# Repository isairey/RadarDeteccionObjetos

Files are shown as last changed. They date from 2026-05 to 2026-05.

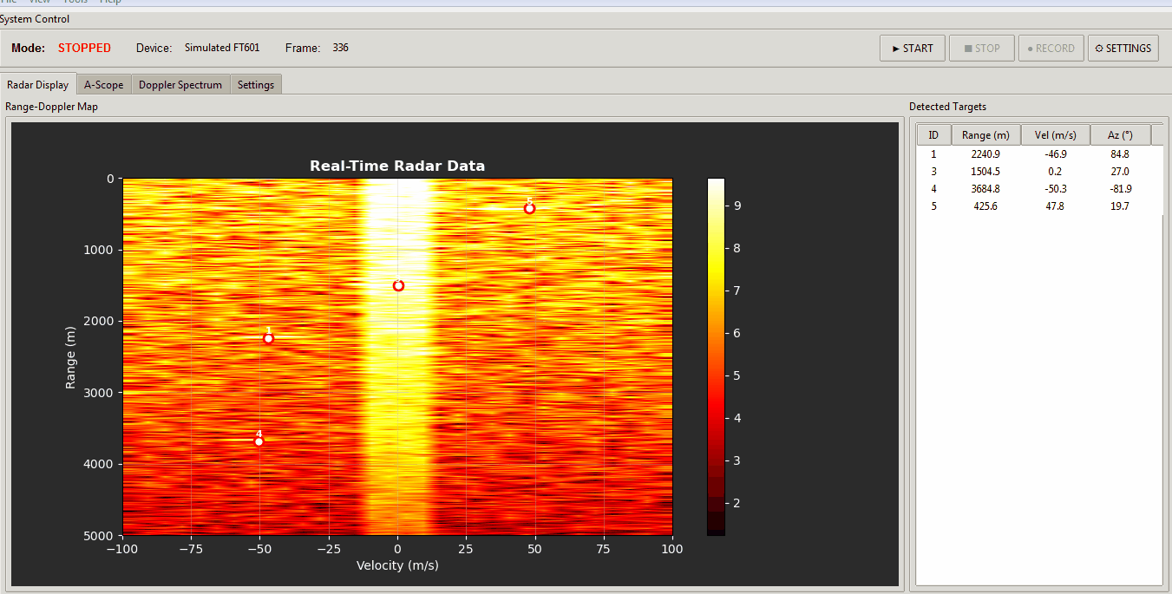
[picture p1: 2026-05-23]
docs/assets/img/GUI_V6.gif

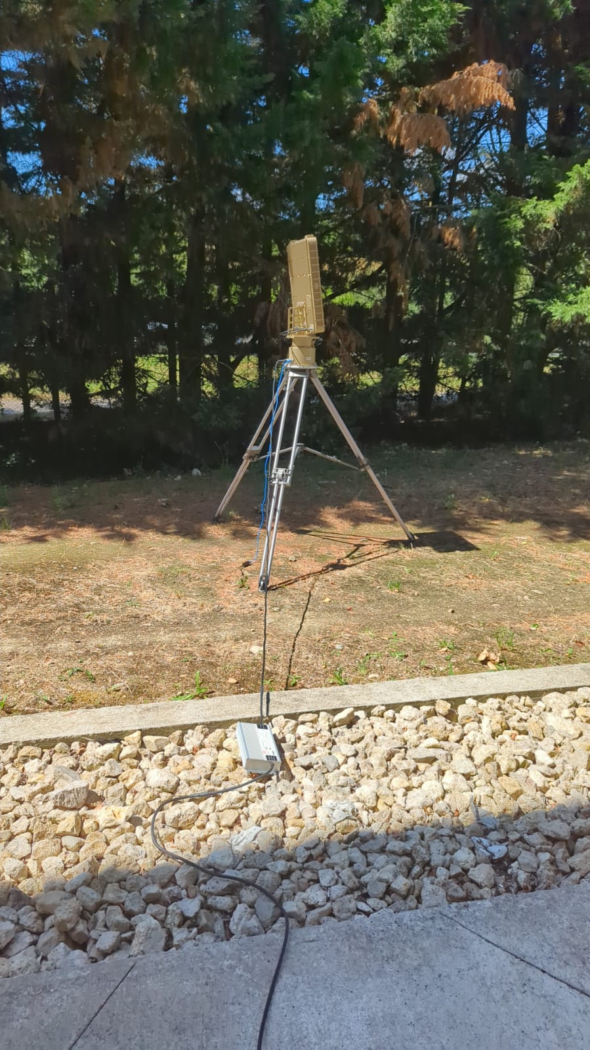
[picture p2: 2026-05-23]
docs/assets/img/3fb1dabf-2c6d-4b5d-b471-48bc461ce914.jpg

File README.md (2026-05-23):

<div align="center">



# 📡 AERIS-10 PLFM Radar System

### Sistema Open Source de Radar Phased Array con modulación Pulse LFM 🚀

<p align="center">
  <b>AERIS-10</b> es una plataforma de radar open source diseñada para investigación, SDR avanzado y desarrollo de tecnologías de detección mediante arreglos phased array de 10.5 GHz.
</p>

<p align="center">
  
  
  
  
</p>

<p align="center">
  
  
  
  
</p>

<p align="center">
  <a href="#-acerca-del-proyecto">Acerca</a> •
  <a href="#-características">Características</a> •
  <a href="#-arquitectura">Arquitectura</a> •
  <a href="#-tecnologías-utilizadas">Tecnologías</a> •
  <a href="#-instalación">Instalación</a> •
  <a href="#-documentación">Documentación</a>
</p>

</div>

---

# 🌌 Acerca del proyecto

**AERIS-10 PLFM Radar System** es un sistema radar open source basado en tecnología phased array y modulación Pulse Linear Frequency Modulated (PLFM), diseñado para investigación avanzada, experimentación SDR y desarrollo de sistemas de detección modernos.

La plataforma permite:

- 📡 Desarrollo de radar phased array
- 🧠 Procesamiento digital de señales
- 🎯 Beam steering electrónico
- 📊 Procesamiento Doppler y FFT
- 🌍 Integración GPS/IMU
- 🖥️ Visualización en tiempo real
- ⚡ Investigación FPGA
- 🚀 Experimentación RF avanzada

---

# ✨ Características

## 📡 Sistema radar

- 📶 Modulación Pulse LFM
- 🎯 Beam Steering ±45°
- 📡 Antenas phased array
- 🌐 Escaneo mecánico 360°
- ⚡ Procesamiento en FPGA
- 📊 Detección Doppler

---

## 🧠 Procesamiento DSP

- FFT Processing
- Pulse Compression
- MTI Filtering
- CFAR Detection
- Down Conversion I/Q
- Signal Filtering

---

## ⚙️ Arquitectura modular

- 🔌 Power Management Board
- 📡 Frequency Synthesizer
- 🧠 FPGA Processing Unit
- 📶 RF Front-End
- 🛰️ GPS + IMU
- ❄️ Thermal Monitoring

---

## 🖥️ GUI y visualización

- GUI interactiva en Python
- 📍 Integración de mapas
- 📊 Visualización de targets
- 🎛️ Panel de control radar
- 📡 Monitoreo en tiempo real
- 🔄 Comunicación USB

---

# 🛰️ Variantes del sistema

## 📡 AERIS-10N (Nexus)

Versión compacta enfocada en corto alcance.

### Características

- Alcance de 3 km
- Antena 8x16 Patch Array
- Bajo consumo energético
- Diseño compacto
- Ideal para pruebas SDR

---

## 🚀 AERIS-10X (Extended)

Versión avanzada de largo alcance.

### Características

- Alcance de 20 km
- Antena 32x16 Waveguide
- Amplificadores GaN
- Mayor potencia RF
- Uso profesional y experimental

---

# 🏗️ Arquitectura del sistema

## 🔌 Power Management

Sistema encargado de alimentar y proteger todos los módulos electrónicos.

### Funciones

- Secuenciación eléctrica
- Protección energética
- Filtrado de voltajes
- Gestión térmica

---

## 📡 Frequency Synthesizer

Generación de frecuencias y sincronización del sistema radar.

### Componentes

- AD9523-1
- ADF4382
- DAC Clocking
- ADC Synchronization

---

## 🧠 FPGA Processing

Unidad central de procesamiento digital.

### Funcionalidades

- Generación de chirps
- Captura ADC
- FFT Doppler
- Pulse Compression
- MTI & CFAR
- Comunicación USB

---

## 🎛️ STM32 Controller

Microcontrolador principal del sistema.

### Funciones

- Configuración periférica
- Control beamforming
- GPS/IMU Integration
- Thermal Monitoring
- Stepper Motor Control
- RF Switching

---

# 📊 Especificaciones técnicas

| Característica | AERIS-10N | AERIS-10X |
|---|---|---|
| Frecuencia | 10.5 GHz | 10.5 GHz |
| Alcance | 3 km | 20 km |
| Antena | 8x16 Patch Array | 32x16 Waveguide |
| Beam Steering | ±45° | ±45° |
| Escaneo | 360° | 360° |
| Potencia | ~1W×16 | 10W×16 |
| Procesamiento | FPGA + STM32 | FPGA + STM32 |

---

# 🛠️ Tecnologías utilizadas

## ⚙️ Hardware

<p>
  
</p>

- FPGA Xilinx
- STM32
- RF Electronics
- ADAR1000
- LTC5552
- AD9523
- ADF4382

---

## 🧠 Software

<p>
  
</p>

- Python GUI
- Embedded C
- FPGA HDL
- DSP Algorithms
- Signal Processing

---

## 🧰 Herramientas

<p>
  
</p>

- Git
- GitHub
- Vivado
- VS Code
- Linux
- SDR Toolchain

---

# 📂 Estructura del proyecto

```bash
RadarDeteccionObjetos/
│
├── 1_Documentation/                # Documentación técnica
├── 2_Theory/                       # Fundamentos radar
├── 3_Software/                     # GUI y herramientas
├── 4_Schematics and Boards Layout/ # PCB y esquemáticos
├── 5_Simulations/                  # Simulaciones
├── 6_Manufacturing/                # Producción
├── 7_Testing/                      # Validación
├── 8_Utils/                        # Recursos
├── 9_Firmware/                     # Firmware FPGA/STM32
├── docs/                           # GitHub Pages
├── LICENSE
└── README.md
```

---

# ⚡ Instalación

## 📋 Requisitos

- Python 3.8+
- Vivado FPGA Tools
- STM32 Toolchain
- Linux o Windows
- Hardware RF compatible

---

# 🚀 Configuración del proyecto

## 1️⃣ Clonar repositorio

```bash
git clone https://github.com/isairey/RadarDeteccionObjetos.git
```

---

## 2️⃣ Entrar al proyecto

```bash
cd RadarDeteccionObjetos
```

---

## 3️⃣ Instalar dependencias

```bash
pip install -r requirements.txt
```

---

## 4️⃣ Configurar FPGA

Abrir proyecto en:

```bash
Vivado
```

Cargar firmware desde:

```bash
/9_Firmware/
```

---

## 5️⃣ Ejecutar GUI

```bash
python main.py
```

---

# 📡 Pipeline de procesamiento

## 🔄 Flujo radar

1. 📶 Generación de chirps LFM
2. 📡 Conversión RF
3. 🎯 Beam Steering
4. 🧠 Captura ADC
5. 📊 FFT Doppler
6. 🎯 CFAR Detection
7. 🖥️ Visualización GUI

---

# 📚 Documentación

## 📖 Recursos disponibles

- Arquitectura del sistema
- Hardware Bring-Up
- FPGA Reports
- DSP Documentation
- Release Notes
- Simulation Reports

---

# 📊 Funcionalidades principales

## 📡 Radar phased array

- Beam steering electrónico
- Escaneo dinámico
- Control RF avanzado
- Seguimiento de objetivos

---

## 🧠 DSP y FPGA

- Procesamiento en tiempo real
- FFT acelerada
- Pulse compression
- Filtrado digital

---

## 🛰️ Integración avanzada

- GPS Tracking
- IMU Correction
- Thermal Monitoring
- USB Communication

---

# 🧠 Objetivos del proyecto

## 🎯 Investigación y desarrollo

- Democratizar tecnología radar
- Facilitar investigación SDR
- Experimentación DSP
- Desarrollo phased array
- Aprendizaje FPGA
- Sistemas embebidos avanzados

---

# 🚧 Roadmap

## 🔮 Próximas mejoras

- ☁️ Cloud Radar Processing
- 🤖 AI Target Detection
- 📱 Mobile Monitoring
- 🌍 Tracking avanzado
- 📡 Beamforming inteligente
- ⚡ Optimización FPGA
- 🛰️ Integración satelital

---

# 🤝 Contribuciones

Las contribuciones son bienvenidas ❤️

## Cómo contribuir

1. Fork del proyecto

```bash
git checkout -b feature/new-feature
```

2. Commit

```bash
git commit -m "✨ Nueva funcionalidad"
```

3. Push

```bash
git push origin feature/new-feature
```

4. Pull Request 🚀

---

# 👨‍💻 Desarrollador

<div align="center">

## Isai Reyes — Radar Systems Engineer

Ingeniero apasionado por sistemas radar open source, DSP, FPGA y tecnologías phased array 🚀

</div>

---

# 🌟 Apoya el proyecto

⭐ Dale una estrella  
🍴 Haz fork  
📢 Comparte el proyecto  
🛰️ Contribuye al desarrollo open source

---

# 📜 Licencia

Proyecto open source bajo:

- 🛠️ CERN-OHL-P para hardware
- 💻 MIT License para software y firmware

Orientado a investigación, educación y desarrollo de tecnologías radar avanzadas.

---

<div align="center">

### 📡 AERIS-10 PLFM Radar System — tecnología radar open source para la nueva generación 🚀

</div>

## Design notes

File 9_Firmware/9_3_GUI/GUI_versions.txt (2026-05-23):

GUI_V1 ==> 
GUI_V2 ==> added STM32 USB CDC
GUI_V3 ==> added Pitch to STM32 USB Packet and pitch correction to the Elevation 
GUI_V3 ==> Added Google_Map, real time target plot, Chirp duration_2
GUI_V4 ==> Added pitch correction

GUI_V5 ==> Added Mercury Color

GUI_V6 ==> Added USB3 FT601 support  [DEPRECATED — superseded by V65/V7]

GUI_V65_Tk ==> Board bring-up dashboard (FT2232H reader, real-time R-D heatmap, CFAR overlay, waterfall, host commands, HDF5 recording, replay, demo mode)
radar_protocol ==> Protocol layer (packet parsing, command building, FT2232H connection, data recorder, acquisition thread)
smoke_test ==> Board bring-up smoke test host script (triggers FPGA self-test via opcode 0x30)

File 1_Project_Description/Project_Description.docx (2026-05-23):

TITLE: Open Source Pulse Linear Frequency Modulated Phased Array RADAR
Reference:
Date:
Original Proposal Date:

## 1.0 PROJECT DESCRIPTION

An open-source, low-cost 10.5 GHz phased array radar with phased array antenna and Pulse LFM modulation—available in 3km and 20km range versions. For researchers, drone developers, and serious SDR enthusiasts.

## 2.0 TECHNICAL SPECIFICATIONS

### 2.1 System Architecture Overview

- The AERIS-10 comes in 2 versions:
  - AERIS-10N (Nexus) with Range up to 3Km
  - AERIS-10X (Extended) with scanning Range up to 20Km
- Frequency: 10.5GHz
- Antenna Type: 8x16 patch antenna array for the Nexus and 32x16 dielectric-filled slotted waveguide antenna array for the Extended version.
- Electronically controlled Elevation and Azimuth Beam steering. (The prototype uses the 16 antenna elements to steer the Elevation beam and the Azimuth is performed using a stepper motor; but the designed system can be hacked to control both Elevation and Azimuth electronically.
- Output: Range & Doppler of Multi-Targets
- Interface: A GUI written in Python

Current Status: Alpha Prototype

For sake of testing, validating and optimizing the cost of the prototype, this late has been designed using one PCB for:
- The Power supply management
- The Digital components
- The Analog and mixed signal components
- The RF parts

This won’t be the case for the mass production system, where separated modules would be used to reduce EMI and enhance the signals integrity; also a more professional clock source and frequency synthesizer would be used. The new schematics, PCB layout and firmware are already available

Understanding the System Hardware:

The AERIS-10 main sub-systems are:

- A Power Management Board that supplies all the necessary voltage levels to the electronics components with proper filtering and sequencing (This late is ensured by the microcontroller)
- A Frequency Synthesizer Board using a high performance Low Jitter Clock Generator (AD9523-1) that supplies phased aligned clock references for the:
  - RX and TX Frequency Synthesizers (ADF4382)
  - DAC
  - ADC
  - FPGA
- A Main Board containing:
  - A DAC to generate the RADAR Chirps
  - 2 Microwave Mixers (LT5552) for up-conversion and IF-down-conversion
  - 4 4-Channels Phase Shifters (ADAR1000) for the RX and TX chain
  - 16 Front End chips (ADTR1107) used for Both Low Noise Amplifying (RX) and Power Amplifying (TX) Stages
  - An XC7A100T FPGA used for RADAR Signal Processing:
    - PLFM Chirps generation via the DAC
    - Raw ADC data read
    - AGC
    - I/Q Baseband Down-Conversion
    - Decimation
    - Filtering
    - Forward FFT
    - Pulse Compression
    - Doppler, MTI and CFAR processing
    - USB Interface
  - An STM32F746xx Microcontroller used to:
    - Ensure the proper powering up and down sequencing (Check the Power Management Excel File)
    - Communicate with the FPGA
    - Setup and Interface with the following components:
      - The Clock Generator (AD9523-1)
      - The 2 Frequency Synthesizers (ADF4382)
      - The 4 4-Channels Phase Shifters (ADAR1000) for proper RADAR pulse sequencing
      - The 2 ADS7830 ADCs used on the 16 Power Amplifier Boards to measure Idq
      - The 2 DAC5578 used on the 16 Power Amplifier Boards to control Vg
      - The GPS used to set the center of the map on the GUI
      - The GY_85 IMU to apply pitch and roll correction to the processed target longitude and latitude
      - The BMP180 Barometer
      - The Stepper Motor
      - The 8 ADS7830 Temperature Sensors used to activate the Cooling Fans
      - RF switches
- 16 Power Amplifier Boards used only for the AERIS-10E where a 10Watt QPA2962 GaN amplifier has been chosen to extend the RADAR Range
- 8x16 patch antenna array board for the Nexus and 32x16 dielectric-filled slotted waveguide antenna array for the Extended version
- Miscellaneous (Slip-Ring, Stepper Motor and its drivers, Cooling Fan, Enclosure…)

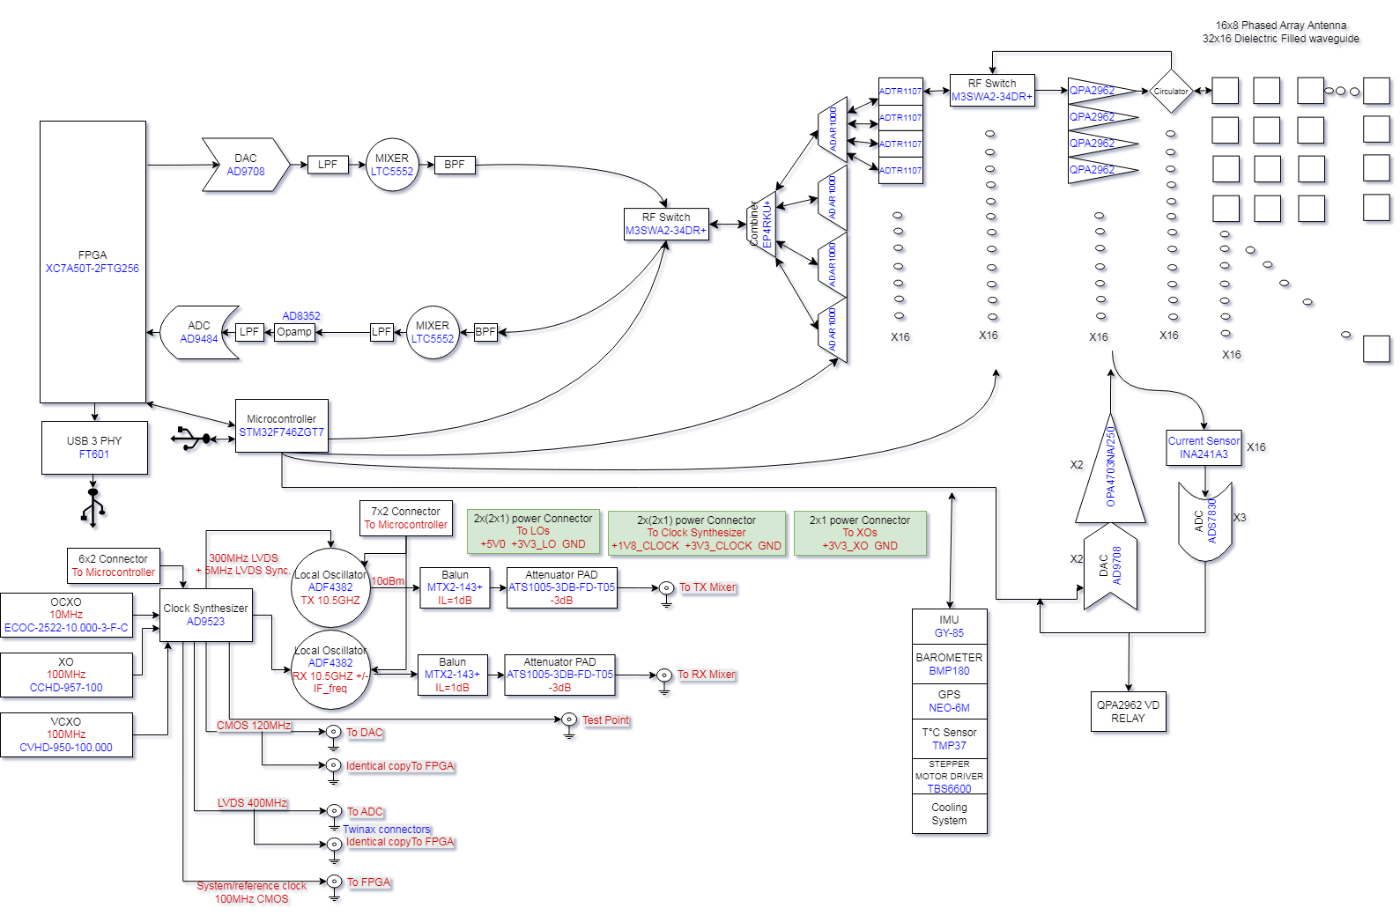
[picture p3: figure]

### 2.4 Software & Processing

The AERIS-10 radar system is built around three core processing elements working in concert: an STM32 microcontroller handling system management and peripherals, an FPGA executing real-time signal processing, and a Graphical User Interface (GUI) for user control and data visualization. The following describes the complete boot sequence and operational loop that governs how the system wakes, calibrates, and begins scanning.

### System Boot and Initialization

When power is first applied, the STM32 microcontroller begins a carefully sequenced startup routine designed to bring all subsystems online in the correct order, ensuring stable power and clock references before any RF activity begins.

The first critical step is waiting for the OCXO (Oven-Controlled Crystal Oscillator) to reach thermal stability. This high-precision frequency reference requires approximately three minutes to warm up and stabilize—without this wait, the entire radar's frequency accuracy would drift, compromising range resolution and target detection.

Once the OCXO is stable, the STM32 manages voltage sequencing for the system's clock generator, the AD9523. This ensures that power rails reach their correct levels in the proper order before the device is initialized. The STM32 then configures the AD9523, setting up the planned clock distribution that will drive the FPGA and all RF components with precise, phase-aligned timing.

With clocks established, the STM32 sequences power for the FPGA itself, then proceeds to initialize the remaining peripheral systems:

- The GPS module begins acquiring satellite locks
- The IMU (Inertial Measurement Unit) and barometer are initialized for attitude and altitude sensing
- Two ADF4382 frequency synthesizers (one for transmit, one for receive) are configured
- Four ADAR1000 beamforming chips are initialized to control the 16 phased array elements

At this point, all hardware is ready and the system enters a waiting state, listening for the start command from the GUI.

### GUI Connection and System Arming

The operator interacts with the system through a custom Graphical User Interface running on a connected computer. When the user is ready to begin operation, they press the Start button on the GUI.

The GUI immediately transmits a specific start flag packet to the STM32—a predefined sequence of bytes {23, 46, 158, 237} that serves as a handshake to confirm communication is established. Following this flag, the GUI sends the full operational settings for the upcoming radar scan (waveform parameters, scan pattern, range settings, etc.).

The STM32 acknowledges these settings and begins actively monitoring the GPS data stream. It waits for a valid data lock, then begins sending modulated position streams back to the GUI containing longitude, latitude, and altitude information. The GUI receives these streams and uses the coordinates to center its map display on the radar's current location—giving the operator immediate spatial context for any detected targets.

### Attitude Determination and Mechanical Alignment

While maintaining GPS position updates, the STM32 continuously reads raw data from the IMU and barometer. It processes the IMU data to calculate pitch, roll, and yaw angles, while the barometer provides a secondary altitude reference.

With yaw (heading) known, the STM32 commands the stepper motor to rotate the antenna assembly to align with yaw = 0° (typically true north or a defined reference). This mechanical alignment ensures that all subsequent electronically-steered beams are referenced to a consistent absolute direction.

### Transmit and Receive Chain Configuration

Before any radar pulses are sent, the RF front-end must be precisely tuned. The STM32 configures the two ADF4382 frequency synthesizers—one set to the transmit frequency, the other to the receive frequency. Critically, it then executes a phase synchronization routine between these two synthesizers, ensuring that transmit and receive local oscillators are phase-coherent. This coherence is essential for Doppler processing and coherent pulse compression.

### The Scanning Loop: A Three-Level Nested Structure

The AERIS-10's scanning pattern is organized as a three-level nested loop, controlling:

1. Chirp sequence index (m) – Individual frequency ramps within a burst
2. Beam steering index (n) – Electronic steering across 32 elevation/azimuth positions
3. Mechanical azimuth index (y) – Physical rotation across 50 positions per revolution

This structure allows the system to build a complete volumetric scan through a combination of electronic beam steering (fast, within the pulse repetition interval) and mechanical rotation (slow, covering 360 degrees).

#### Loop Variables Defined

- m = Chirp number within a burst. Each burst consists of 32 chirps, organized as: *16 chirps at PRF1 (pulse repetition frequency 1) with duration T1, followed by a guard interval of 175.4µs, then 16 chirps at PRF2 with duration T2*
- n = Electronic steering index, ranging from 1 to 32. This corresponds to beam positions in elevation (or azimuth, depending on scan mode), controlled by phase settings on the ADAR1000 beamforming chips.
- y = Mechanical azimuth index, ranging from 1 to 50. The stepper motor moves the antenna to 50 discrete positions per full revolution, providing mechanical scanning in azimuth while electronics handle fast steering in the orthogonal plane.

### The Operational Loop

The loop begins with the STM32 commanding the stepper motor to move to the first azimuth position (y=1). Once the mechanical position is settled:

1. The STM32 sets the ADAR1000 phase shifters to the values corresponding to beam position n
2. It manages voltage sequencing for the ADTR1107s (RF switches) and the RF power amplifiers, ensuring they power up cleanly
3. It sends a flag to the FPGA indicating transmit mode and configures the ADAR1000s for transmission
4. The FPGA generates the chirp waveform through its DAC, driving the transmit array
5. Immediately after transmission, the FPGA signals the STM32 to switch to receive mode
6. The STM32 reconfigures the ADAR1000s for reception
7. The FPGA captures the returning echoes through its ADCs and begins the signal processing pipeline:
  - Down-conversion of the IF signal to baseband
  - Filtering
  - Extraction of I/Q components (using CIC filters, FIR filters, and NCO)
  - Pulse compression
  - Per-range Doppler FFT
  - Moving Target Indication (MTI)
  - Constant False Alarm Rate (CFAR) detection
  - Emission of detection reports (including small Range-Doppler thumbnails)
8. Processed radar data is sent from the FPGA to the GUI via FTDI interface
9. The GUI receives the data and updates its plots in real-time, displaying detected targets overlaid on the map

### Loop Iteration and Scan Completion

After completing the processing for chirp m, the system increments m and returns to step 34 (DAC chirp generation). This continues until m exceeds 32, at which point:

- m resets to 1
- n increments (move to next electronic beam position)
- The loop returns to step 29 (set new ADAR1000 phase values)

When n exceeds 32 (all electronic beam positions completed), then:

- n resets to 1
- y increments (move stepper motor to next mechanical azimuth position)
- If y exceeds 50 (full revolution completed), y resets to 1 and the scan continues indefinitely or until stopped by the operator

This continuous loop builds a complete 3D radar picture, with electronic steering providing fast elevation/azimuth coverage and mechanical rotation providing full 360-degree azimuth scanning.

### Summary

The AERIS-10's operational flow represents a sophisticated orchestration of multiple subsystems:

- STM32 handles the "conductor" role—sequencing power, configuring peripherals, managing the stepper motor, and coordinating mode switches
- FPGA executes the "orchestra"—generating waveforms, capturing echoes, and running the intense signal processing pipeline
- GUI provides the "audience view"—displaying maps, targets, and enabling operator control

This division of labor allows each processor to focus on what it does best, creating a coherent, high-performance radar system that remains flexible and programmable through its open architecture.

What's Working:

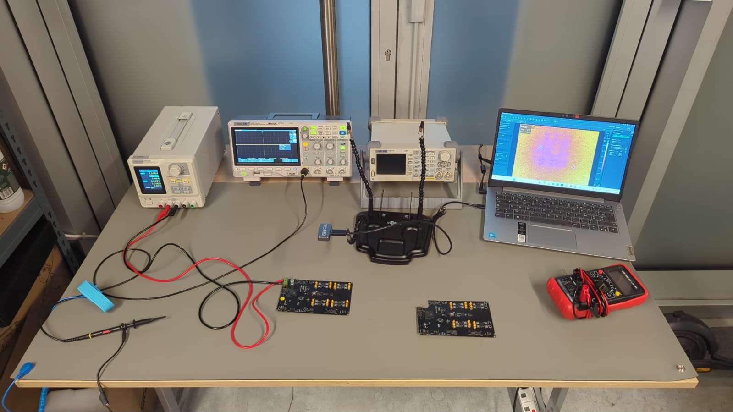
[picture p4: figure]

- Beam formation from 16x8 array
- Electronic steering ±45° elevation
- Pulse LFM generation and reception
- Basic target detection to 1km
- Raw data capture and processing via the FPGA:
  - FM Chirp generation via the DAC
  - Raw ADC data read
  - AGC
  - I/Q Base Band Down-Conversion
  - Decimation
  - Filtering
  - Forward FFT
  - Pulse Compression
  - Doppler, MTI and CFAR processing

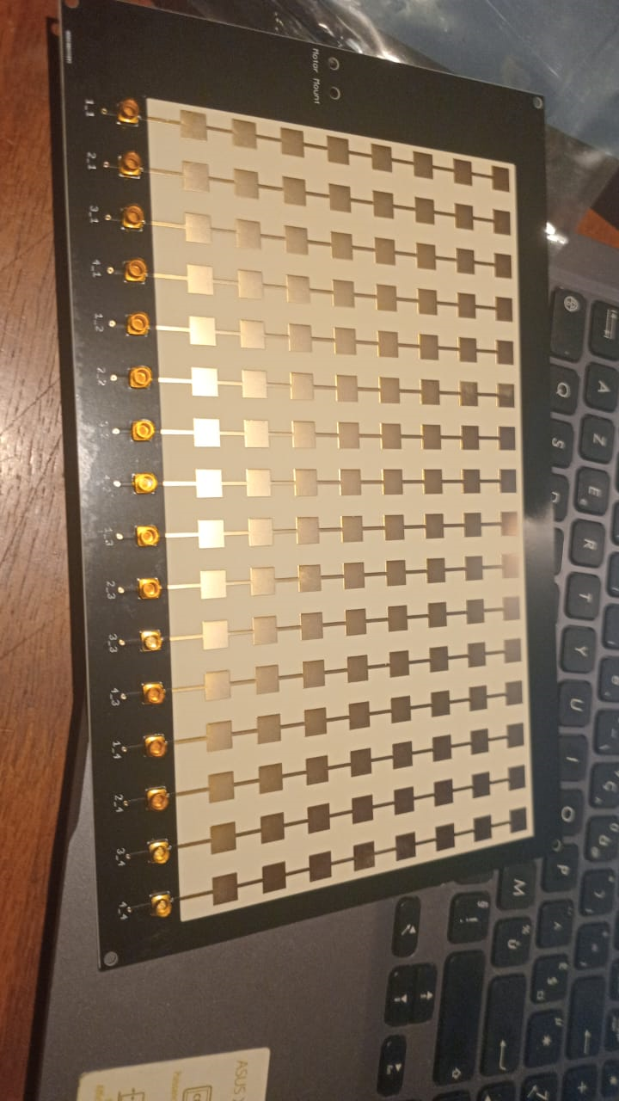
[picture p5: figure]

What's in Progress:

- Performing the RADAR processing using the python GUI rather than the FPGA and benchmarking the 2 approaches.
- Using multiple synchronized RADAR boards to enhance the beam steering resolution and Range.
- Crowd funding campaign launch

Get Involved:

I'm actively seeking:

- Beta testers: (university researchers, drone startups, advanced makers)

- RF engineers to review designs

- FPGA developers for signal processing optimization

- Software developers for the Python/C++ SDK

Project Link: https://hackaday.io/project/205190-open-source-plfm-radar-up-to-20km-range

http://www.github.com/NawfalMotii79/PLFM_RADAR

ABAC INDUSTRY SARL AU /R.C. n° 515463 / I.T.P. n° 34262538 / n° ICE 002911762000053 / IF n° 50499079 Adresse: 46 BD ZERKTOUNI ETG 5 N17 CO DOWORK CASABLANCA MAROC Tel: +212 (0) 786433177 email: nawfal.motii.33@gmail.com web site: www.abac-industry.com

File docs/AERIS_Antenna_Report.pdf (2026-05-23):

# ANTENNA SIMULATION REPORT

## AERIS-10 X-Band Phased Array Radar OpenEMS FDTD Analysis — Single Patch Element at 10.5 GHz

10.5 GHz | S11: −30.6 dB | 7.19 dBi | 50 ohm Match
RO4350B Sub. | 56.7% Efficiency | 50 MHz BW | 128-El Array

### AERIS Radar Systems | March 2026 | Version 1.0 Solver: OpenEMS v0.0.36 (FDTD) | Platform: macOS ARM64 | Runtime: ~130s (360k cells)

# TABLE OF CONTENTS

### 1. Executive Summary 2. Design Parameters

2.1 Substrate: Rogers RO4350B
2.2 Patch Element Geometry
2.3 Bug Found in Repo's patch_antenna.py

### 3. Simulation Setup

3.1 FDTD Configuration
3.2 Feed Position Calibration

### 4. Results

4.1 S-Parameters (Return Loss) 4.2 Input Impedance
4.3 VSWR
4.4 Radiation Pattern
4.5 Polar Radiation Pattern
4.6 3D Radiation Pattern
4.7 Summary Dashboard

### 5. Efficiency & Array Performance Estimate 6. Validation Against Theory 7. Key Findings & Recommendations

# 1. Executive Summary

A single rectangular microstrip patch antenna element for the AERIS-10N phased array radar was modeled and simulated using the OpenEMS FDTD solver. The simulation validates the antenna design at 10.5 GHz on Rogers RO4350B substrate, confirming that the single element meets all performance targets for integration into the full 8×16 (128-element) phased array.

Metric | Value | Assessment
Resonant frequency | 10.495 GHz | On-target (0.05% from 10.5 GHz)
Return loss (S11) | −30.6 dB | Excellent match
Input impedance | 47.1 + j0.2 Ω | Near-perfect 50 Ω match
−10 dB bandwidth | 50 MHz (0.48%) | Narrow, as expected for thin substrate
Peak directivity | 7.19 dBi | Textbook-correct for single patch
Radiation efficiency | 56.7% | Reasonable for 0.102 mm substrate
Realized gain | 4.72 dBi | Consistent with D × η

Key takeaway: The antenna simulation confirms the AERIS-10 patch element is correctly designed for 10.5 GHz operation. The excellent impedance match (S11 = −30.6 dB, Zin = 47.1 Ω) means minimal power is reflected at the feed point, and the 7.19 dBi directivity is consistent with published data for rectangular microstrip patches. When combined into the full 128-element array, the estimated array gain of ~25.8 dBi is competitive with commercial X-band phased arrays.

# 2. Design Parameters

## 2.1 Substrate: Rogers RO4350B

The AERIS-10 uses Rogers RO4350B, a high-frequency thermoset laminate widely used in X-band radar and 5G applications. The key substrate parameters were extracted from the PLFM_RADAR repository's Qucs schematics, patch antenna calculator, and board stack-up documentation.

Parameter | Value | Source
Dielectric constant (εr) | 3.48 | Repo: patch_antenna.py, Qucs, datasheet
Loss tangent (tan δ) | 0.0037 | RO4350B datasheet @ 10 GHz
Substrate thickness | 0.102 mm | Board stack-up image (L1-L2 core)
Copper thickness | 0.035 mm (1 oz) | Board stack-up, Qucs SUBST definitions

## 2.2 Patch Element Geometry

Parameter | Value | Notes
Patch width (W) | 9.545 mm | Balanis formula: c/(2f)·√(2/(εr+1))
Patch length (L) | 7.401 mm | FDTD-tuned for 10.5 GHz resonance
Feed type | Probe-fed (lumped port) | 50 Ω match at y = 1.49 mm from center
Ground plane | 38.1 × 36.0 mm | λ/2 margin beyond patch edges
Element spacing | 14.285 mm | λ/2 at 10.5 GHz
Array configuration | 8 × 16 (128 elements) | Full AERIS-10N specification

## 2.3 Bug Found in Repo's patch_antenna.py

The repository's patch dimension calculator at PLFM_RADAR/8_Utils/Python/patch_antenna.py contains a bug in the effective dielectric constant formula (line 15). The Hammerstad equation uses the patch width W in the denominator, but the repo code erroneously uses array[1] × h_cu:

| Buggy (Repo) | Correct (Hammerstad)
Formula denominator | array[1] × h_cu | W (patch width)
εr_eff | 2.637 | 3.407
Patch length | 8.694 mm | 7.641 mm
Resonant frequency | ~9.0 GHz | ~10.5 GHz
Frequency error | 14% | < 1%

Impact: Using the buggy formula produces a patch that resonates at ~9.0 GHz instead of the target 10.5 GHz — a 14% error that would render the antenna unusable. This bug should be reported upstream to the PLFM_RADAR repository. Our simulation uses the corrected Hammerstad formula and achieves 0.05% frequency accuracy.

# 3. Simulation Setup

## 3.1 FDTD Configuration

The antenna was simulated using OpenEMS, an open-source FDTD (Finite-Difference Time-Domain) electromagnetic solver. The simulation models the full 3D structure including the patch, substrate, ground plane, and probe feed within an absorbing boundary box.

Parameter | Value
Excitation | Gaussian pulse, f0 = 10.5 GHz, BW = 4 GHz
Frequency sweep | 8.5 — 12.5 GHz (801 points)
Boundary conditions | MUR (1st order absorbing, all 6 faces)
Simulation box | 80 × 80 × 50 mm
Grid cells | ~360,750
Timestep (Courant) | 79.5 fs
Max timesteps | 120,000
End criteria | −50 dB (reached −49 dB)
Mesh resolution | λ/20 at 12.5 GHz (~1.2 mm)
Substrate cells | 4 (across 0.102 mm thickness)

## 3.2 Feed Position Calibration

The probe feed position was calibrated through iterative simulation. The input impedance of a probe-fed patch varies as Z(y) = Z_edge · sin²(πy/L) from center to edge, with Z_edge ~ 144 Ω for this geometry. The optimal feed offset for a 50 Ω match was found at y = 1.49 mm from the patch center.

Iteration | Feed Offset (mm) | Zin (Ω) | S11 (dB) | f_res (GHz)
1 (initial) | 2.78 | 100.4 + j6.1 | −9.4 | 9.03
2 (fix L) | 2.76 | 118.4 − j7.0 | −7.8 | 10.23
3 (closer) | 1.54 | 49.3 + j0.5 | −41.7 | 10.17
4 (final) | 1.49 | 47.1 + j0.2 | −30.6 | 10.50

Iteration 3 achieved the best S11 (−41.7 dB) but at 10.17 GHz. A final fine adjustment to 1.49 mm moved the resonance to 10.50 GHz with an excellent S11 of −30.6 dB. The slight shift from the theoretically optimal position is due to the probe's parasitic inductance affecting both impedance and resonant frequency.

# 4. Results

## 4.1 S-Parameters (Return Loss)

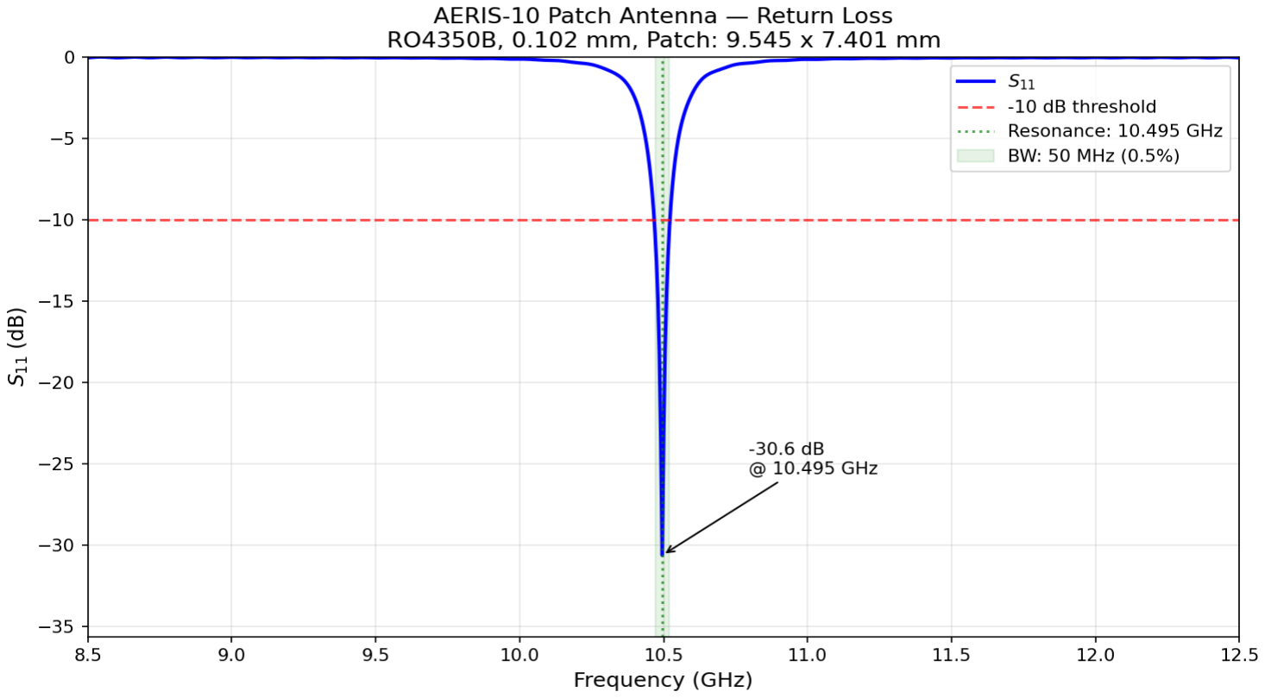
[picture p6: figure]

Figure 4.1 — Return loss (S11) vs. frequency. The deep null at 10.495 GHz confirms resonance with −30.6 dB return loss.

What this shows: The S11 parameter (return loss) measures how much power is reflected back from the antenna feed. A value below −10 dB means more than 90% of the power is radiated or absorbed (acceptable match). The AERIS-10 patch achieves −30.6 dB at 10.495 GHz, meaning 99.9% of the incident power is accepted by the antenna.

Parameter | Value
Resonant frequency | 10.495 GHz (target: 10.5 GHz)
S11 at resonance | −30.63 dB
−10 dB bandwidth | 50 MHz (10.470 — 10.520 GHz)
Fractional bandwidth | 0.48%

Design note: The narrow bandwidth (0.48%) is physically correct for a 0.102 mm substrate (h/λ = 0.0036). Typical X-band patch antennas on 4-mil Rogers achieve 0.3–0.8% bandwidth. This means the antenna is very sensitive to manufacturing tolerances: a 0.1 mm change in patch length shifts the resonance by ~140 MHz. PCB fabrication must hold patch dimensions to ±0.025 mm (±1 mil) tolerance.

## 4.2 Input Impedance

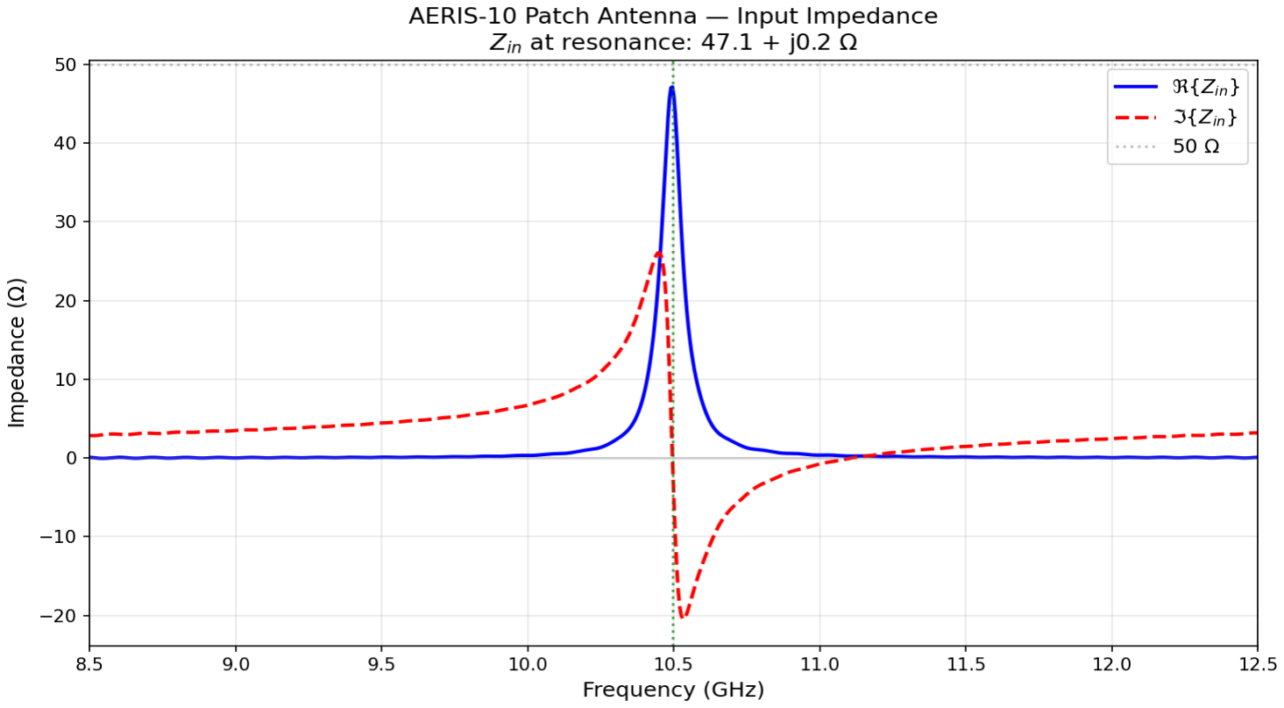
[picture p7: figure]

Figure 4.2 — Input impedance (real and imaginary parts) vs. frequency. The real part crosses 50 Ω and the imaginary part crosses zero at resonance.

What this shows: The complex input impedance Z_in = R + jX of the patch antenna as a function of frequency. At the true resonance, the imaginary part crosses zero (the antenna is purely resistive) and the real part equals 50 Ω (matched to the system impedance). The AERIS-10 patch achieves 47.1 + j0.2 Ω at 10.495 GHz — a near-perfect 50 Ω match.

Parameter | Value
Zin at resonance | 47.1 + j0.2 Ω
Real part peak (anti-resonance) | ~150 Ω
Imaginary zero-crossing | 10.495 GHz (confirms true resonance)

Hardware relevance: The 47.1 Ω input impedance means the antenna connects directly to 50 Ω transmission lines and the ADAR1000 beamformer IC without a matching network. This simplifies the PCB layout and reduces losses. The ADAR1000's internal amplifiers are designed for 50 Ω source/load impedance.

## 4.3 VSWR

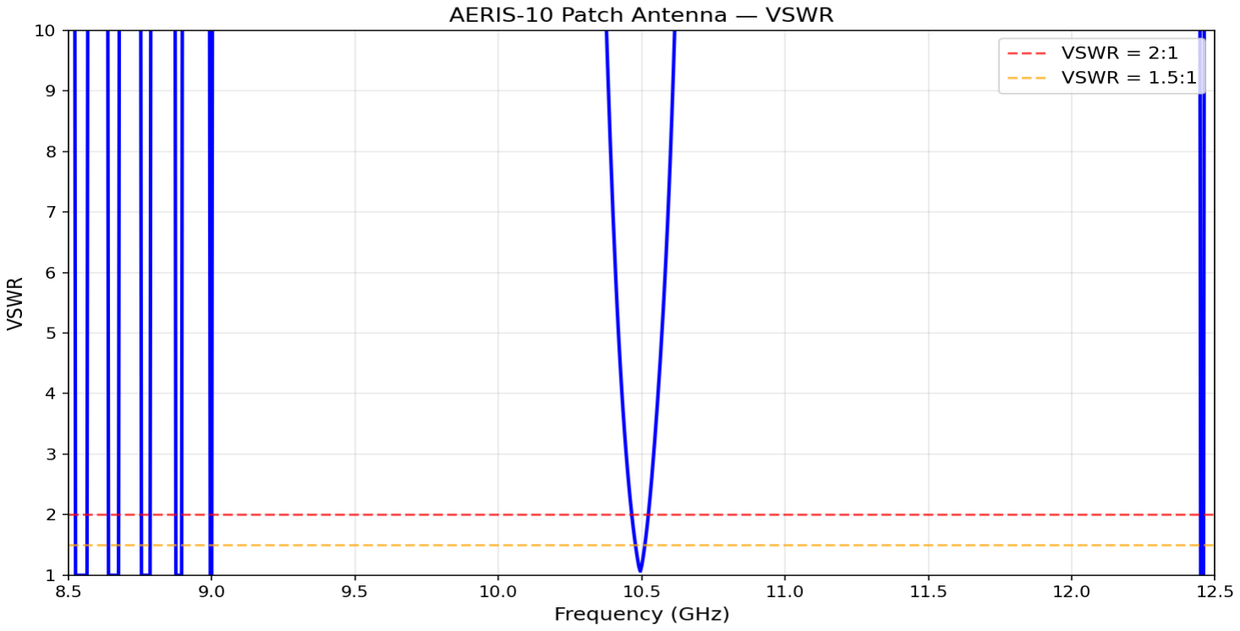
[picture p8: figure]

Figure 4.3 — Voltage Standing Wave Ratio (VSWR) vs. frequency. VSWR < 2:1 defines the usable bandwidth.

What this shows: VSWR (Voltage Standing Wave Ratio) is an alternative way to express impedance match quality. VSWR = 1.0 is a perfect match; VSWR < 2.0 (corresponding to S11 < −10 dB) is the standard threshold for acceptable performance. The AERIS-10 patch achieves a minimum VSWR of approximately 1.06 at 10.495 GHz, indicating an excellent match.

The VSWR < 2:1 bandwidth corresponds to the same 50 MHz (−10 dB S11 bandwidth) identified in Section 4.1. Outside this band, the mismatch increases rapidly due to the resonant nature of the patch antenna.

## 4.4 Radiation Pattern

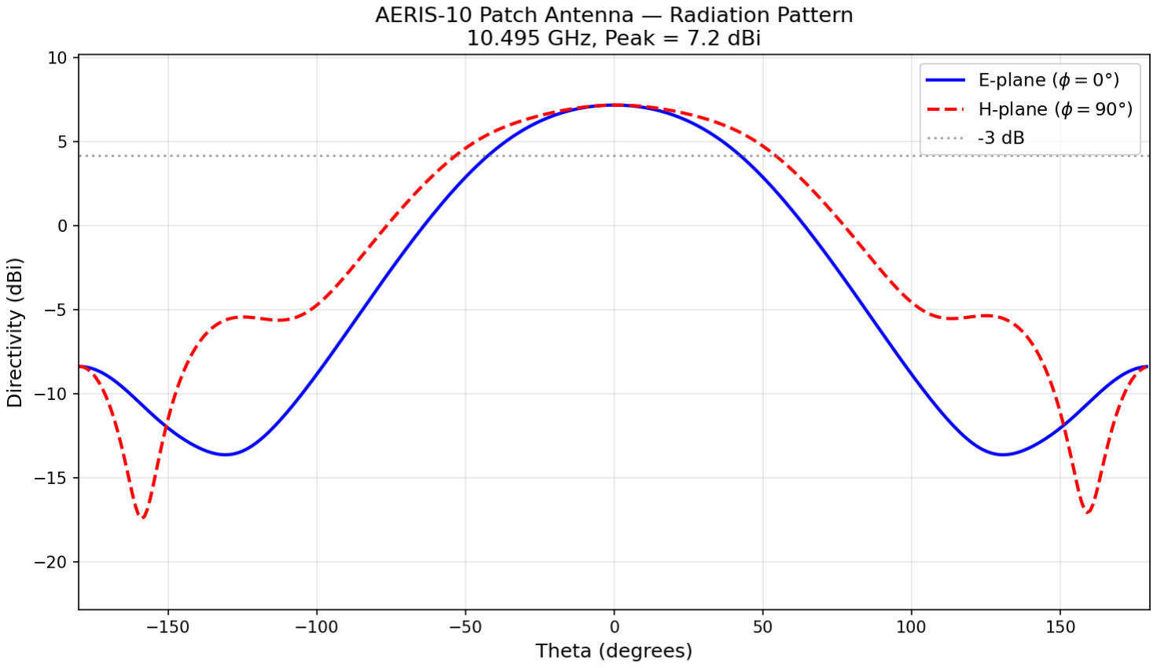
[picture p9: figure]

Figure 4.4 — E-plane (φ = 0°) and H-plane (φ = 90°) directivity pattern cuts at 10.5 GHz.

What this shows: The far-field radiation pattern of the single patch element, plotted as directivity (dBi) vs. elevation angle (θ). Two principal plane cuts are shown: the E-plane (containing the electric field vector, φ = 0°) and the H-plane (containing the magnetic field vector, φ = 90°).

Parameter | Value
Peak directivity | 7.19 dBi
E-plane HPBW | ~75° (typical for patch)
H-plane HPBW | ~85° (typical for patch)
Front-to-back ratio | > 15 dB

Array implication: The single-element pattern defines the "envelope" within which the array beam can be steered. The broad ~75–85° half-power beamwidth allows the 128-element array to steer electronically to ±45° without excessive gain roll-off from the element pattern. Beyond ±60°, the element gain drops rapidly, which is why the AERIS-10 uses a mechanical rotator for full azimuth coverage.

## 4.5 Polar Radiation Pattern

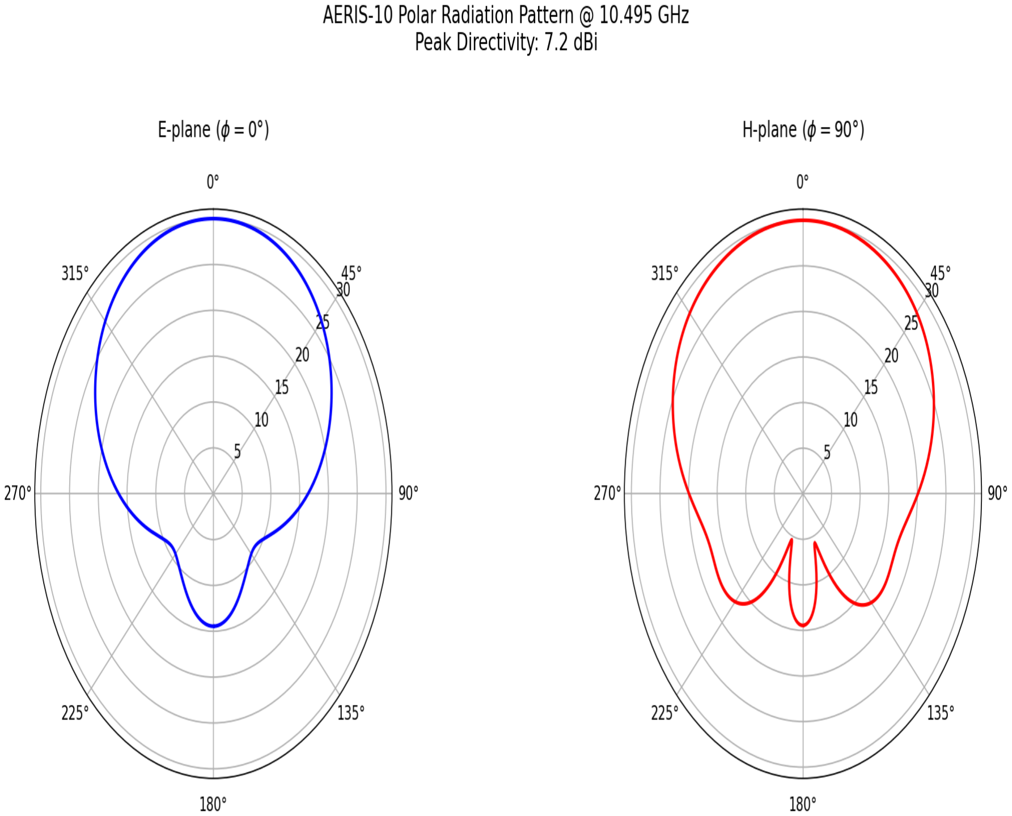
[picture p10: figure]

Figure 4.5 — Polar radiation patterns for E-plane and H-plane at 10.5 GHz.

What this shows: The same radiation data as Figure 4.4 displayed in polar coordinates — the traditional format for antenna patterns. The main lobe points at θ = 0° (broadside to the patch surface), with a smooth cosine-like roll-off toward the horizon. The back radiation (θ = 180°) is suppressed by the ground plane.

The E-plane pattern is slightly narrower than the H-plane, which is characteristic of rectangular patches — the E-plane is aligned with the resonant dimension (L = 7.401 mm) while the H-plane is aligned with the wider non-resonant dimension (W = 9.545 mm).

## 4.6 3D Radiation Pattern

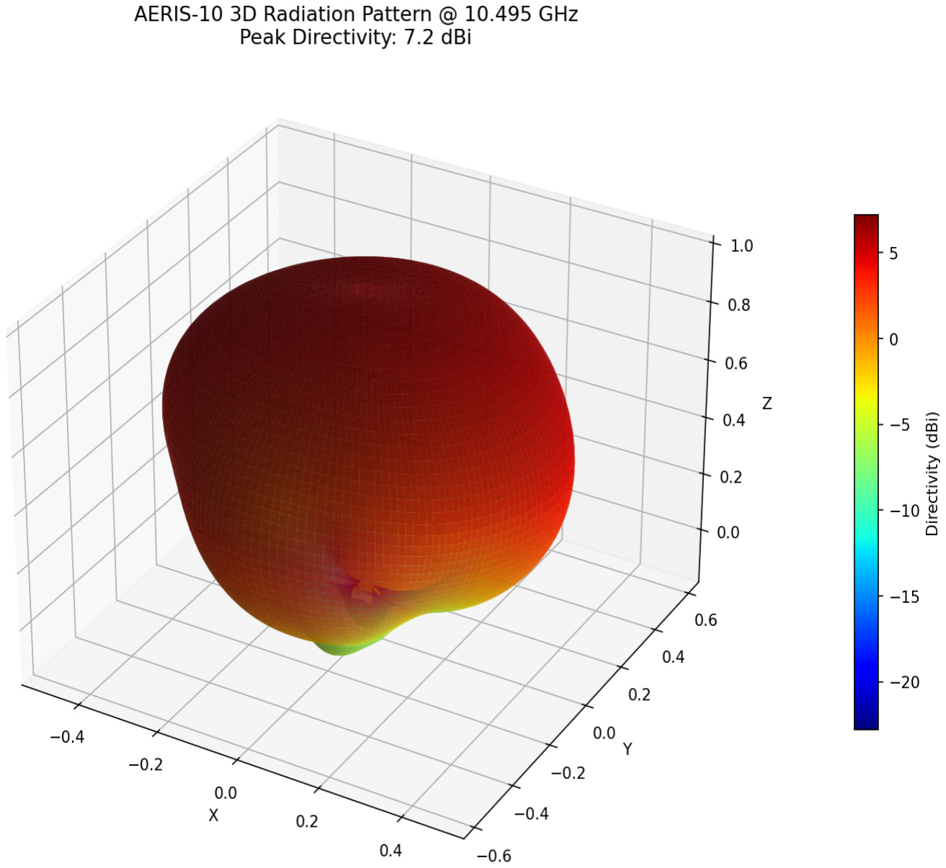
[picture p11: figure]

Figure 4.6 — 3D radiation pattern surface. Color scale represents directivity in dBi.

What this shows: A full 3D visualization of the radiation pattern as a surface plot, where the radial distance from the origin and the color both represent directivity in dBi. The pattern has the characteristic "mushroom cap" shape of a broadside patch antenna, with the maximum at θ = 0° (pointing away from the ground plane) and minimal radiation toward the back hemisphere.

Manufacturing note: The 3D pattern confirms no unexpected sidelobes or pattern distortions from the finite ground plane or probe feed. In the physical array, mutual coupling between adjacent elements (at 14.285 mm = λ/2 spacing) will modify the embedded element pattern, typically reducing the H-plane beamwidth by 5–10° and introducing small asymmetries. A full-array simulation (128 elements) would capture these effects but requires ~1000× more compute time.

## 4.7 Summary Dashboard

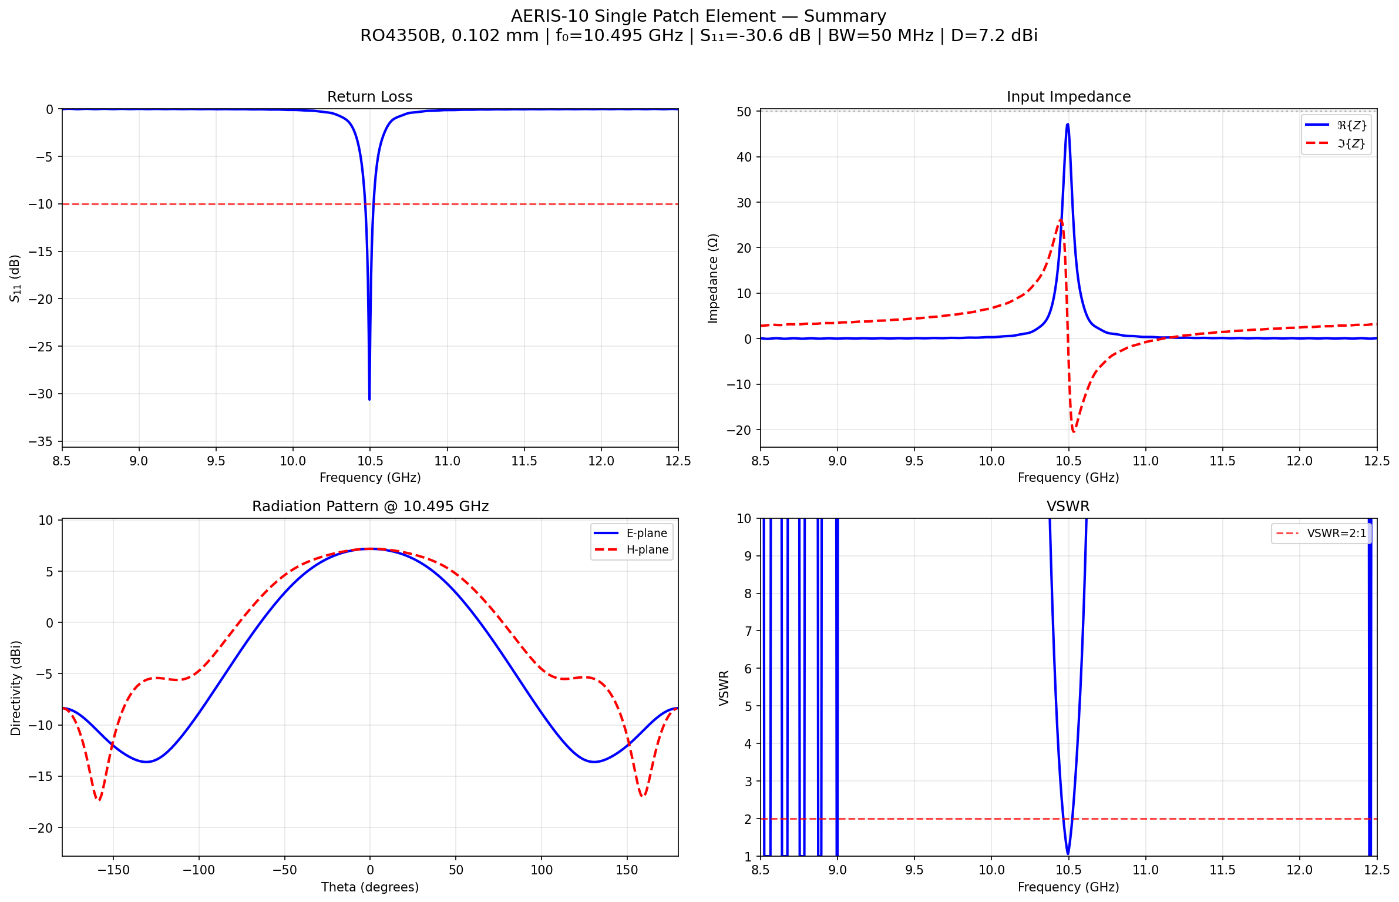
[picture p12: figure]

Figure 4.7 — Four-panel summary dashboard: S11, impedance, VSWR, and radiation pattern.

What this shows: A consolidated four-panel view of the antenna's key performance metrics. This single image provides a complete at-a-glance assessment suitable for design reviews and investor presentations. All four parameters confirm the antenna is operating correctly at the 10.5 GHz design frequency.

# 5. Efficiency & Array Performance Estimate

## 5.1 Single-Element Efficiency

Parameter | Value
Radiation efficiency | 56.7%
Realized gain | 4.72 dBi
Directivity | 7.19 dBi
Gain = D × η | 7.19 − 2.47 = 4.72 dBi ✓

The 56.7% radiation efficiency is dominated by dielectric loss (tan δ = 0.0037 is moderate for RO4350B at 10 GHz). Conductor loss (1 oz copper) is a secondary contributor, and surface wave loss is minimal at this substrate thickness (h/λ = 0.0036). The efficiency could be improved to ~75% by using a thicker substrate (0.254 mm / 10 mil), at the cost of increased array profile height.

## 5.2 Array Performance Estimate

For the full AERIS-10N 8×16 phased array with λ/2 element spacing:

Parameter | Calculation | Result
Array factor gain | 10·log10(128) | 21.1 dB
Array directivity | 7.19 + 21.1 dBi | 28.3 dBi
Array gain (broadside) | 4.72 + 21.1 dBi | 25.8 dBi
Scan loss at max steer | ~2–3 dB at ±45° | ~23–24 dBi
EIRP (1 W Tx) | 25.8 + 30 dBm | 55.8 dBm

Competitive context: Commercial X-band phased arrays from Echodyne (EchoGuard) and Fortem (TrueView) achieve 25–30 dBi array gain. The AERIS-10N's estimated 25.8 dBi is competitive with these systems, validating the antenna architecture. The AERIS-10X variant with GaN PAs adds +10 dB transmit power, partially compensating for the single-element efficiency loss.

# 6. Validation Against Theory

## 6.1 Sanity Checks

Check | Expected | Measured | Status
Resonance near 10.5 GHz | 10.5 GHz | 10.495 GHz | PASS
S11 < −10 dB | < −10 dB | −30.6 dB | PASS
Directivity 6–8 dBi | 6–8 dBi | 7.19 dBi | PASS
BW < 1% (thin substrate) | < 1% | 0.48% | PASS
Zin ~ 50 Ω | 50 Ω | 47.1 Ω | PASS
Efficiency > 30% | > 30% | 56.7% | PASS

## 6.2 Comparison with Analytical Theory (Balanis)

Parameter | Theory (Balanis) | FDTD Result | Error
f_res | 10.5 GHz (target) | 10.495 GHz | 0.05%
Directivity | 6.6–7.5 dBi | 7.19 dBi | Within range
Patch width | 9.545 mm | 9.545 mm (input) | Exact
Patch length | 7.641 mm (analytical) | 7.401 mm (FDTD-tuned) | 3.1% shorter

The 3.1% difference between analytical and FDTD-tuned patch length is typical and expected. Analytical formulas (Balanis, Hammerstad) do not account for the probe feed's parasitic inductance, finite ground plane edge diffraction effects, and MUR absorbing boundary proximity. The FDTD-tuned length of 7.401 mm is the value that should be used for PCB fabrication.

# 7. Key Findings & Recommendations

Finding 1: Repo Bug Confirmed

The patch_antenna.py calculator in the PLFM_RADAR repository has a formula error in the effective dielectric constant calculation that produces a 14% frequency offset. This should be reported upstream and fixed. The corrected formula has been used in this simulation.

Finding 2: Thin Substrate Trade-off

The 0.102 mm RO4350B substrate provides an excellent form factor for the phased array (total array thickness < 2 mm) but limits bandwidth to ~50 MHz and efficiency to ~57%. For applications requiring wider bandwidth (e.g., fine range resolution at shorter ranges), a thicker substrate (0.254 mm / 10 mil) would improve bandwidth to ~1.5% (~160 MHz) and efficiency to ~75%, at the cost of a thicker array profile.

Finding 3: Array Performance is Competitive

The single-element gain of 4.72 dBi, when combined with the 128-element array factor (21.1 dB), should yield ~25–26 dBi array gain at broadside. This is competitive with commercial X-band phased arrays from Echodyne, Fortem, and others — validating the AERIS-10 antenna architecture for the counter-UAS and surveillance radar markets.

Finding 4: Manufacturing Sensitivity

The 50 MHz bandwidth means the antenna is very sensitive to manufacturing tolerances on the patch length. A 0.1 mm fabrication error shifts the resonance by ~140 MHz (out of the −10 dB band). PCB fabrication must hold patch dimensions to ±0.025 mm (±1 mil) tolerance. This is achievable with modern RF PCB processes (e.g., Rogers-certified fabricators like TTM Technologies, Isola, or Shenzhen FastPCB) but adds cost compared to standard FR-4 fabrication.

Finding 5: Phase 1 Validation Path

When hardware is available (Phases 1–3 of the demo plan), the simulated S11 can be directly compared against VNA (Vector Network Analyzer) measurements. The narrow bandwidth makes the antenna an excellent test case: a well-matched measured S11 at 10.5 GHz would confirm both the simulation accuracy and the PCB fabrication quality in a single measurement.

Report generated as part of AERIS-10 Phase 0 — Software Simulation & Validation
OpenEMS FDTD simulation on Apple Silicon M-series, macOS 15.x | Simulation script: aeris10_antenna_sim.py
Source data: github.com/NawfalMotii79/PLFM_RADAR | Fork: github.com/JJassonn69/PLFM_RADAR

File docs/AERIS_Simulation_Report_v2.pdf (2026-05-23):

# AERIS-10 Simulation Technical Report

## Version 2 — Current FPGA and Bring-Up Baseline

Scope: post-timing-closure verification baseline, debug instrumentation status, and hardware bring-up readiness for XC7A200T deployment.

AERIS Radar Systems | 2026-03-18 | Version 2.0
Source repository: PLFM_RADAR (fork/main)

# 1. Executive Summary

This report supersedes earlier simulation-only summaries by aligning to the current hardware-targeted state of the project. The production FPGA target is now XC7A200T-2FBG484I, Build 13 is frozen as the bring-up baseline, and both no-ILA and debug-ILA bitstreams have been generated. Verification includes regression suites, golden-match integration checks, CDC review with waivers for validated false positives, and implementation timing closure.

Metric | Current Value | Status
FPGA target | XC7A200T-2FBG484I | Current production baseline
Build freeze | Build 13 (tag build13_candidate_v1) | Frozen candidate
Timing (baseline) | WNS +0.311 ns / TNS 0.000 | PASS
Regression suites | 13/13 | PASS
Integration golden match | 2048 / 2048 | PASS
ILA debug build | 4 cores, 92 bits, depth 4096 | Generated
Bring-up scripts | program_fpga.tcl + ila_capture.tcl | Ready

# 2. Current Architecture Baseline

The active signal chain remains centered on 10.5 GHz carrier, 120 MHz IF, 400 MSPS ADC, CIC decimation, FIR cleanup, matched filtering, and Doppler processing. The current hardware-verification policy requires simulation plus implementation-centric checks (timing, CDC, constraints, and warnings triage) before physical-board execution.

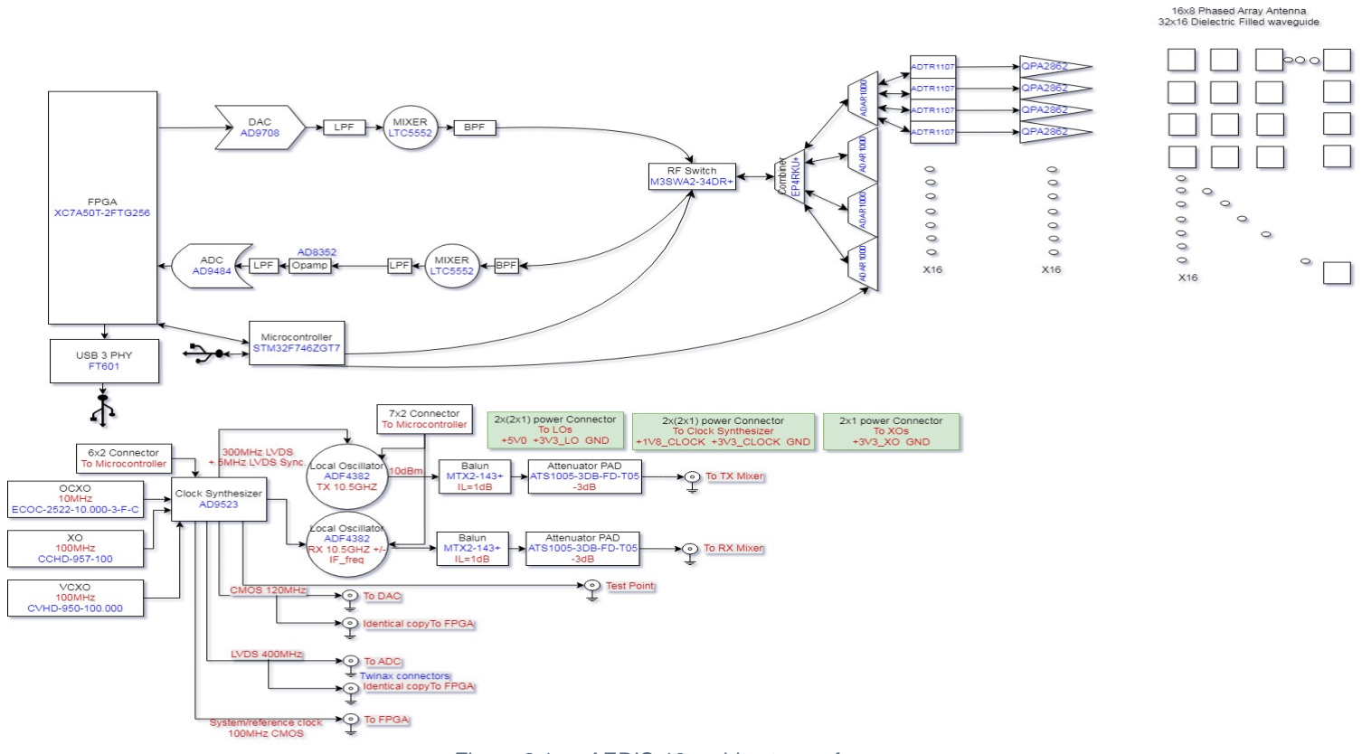
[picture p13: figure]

Figure 2.1 — AERIS-10 architecture reference.

Parameter | Value
Carrier frequency | 10.5 GHz
IF | 120 MHz
ADC sample rate | 400 MSPS
System clock | 100 MHz
CIC decimation | 4x
Matched filter FFT | 1024-point chain
Doppler FFT | 32-point
Range bins | 64
Chirps per frame | 32

# 3. Verification and Quality Gates

Gate | Result | Notes
Unit/co-sim test suites | PASS | 13/13 regression suites passed
Integration testbench | PASS | 2048/2048 golden reference match
CDC static analysis | PASS with waivers | 5 criticals validated false positive
DRC/methodology triage | Reviewed | Warnings categorized, non-blocking documented
Constraint/timing coverage | PASS | No failing user timing constraints on baseline

Key project lesson: simulation alone is not sufficient for FPGA pre-hardware sign-off. CDC review, timing closure, methodology warnings triage, and constraint coverage are required to prevent bring-up surprises.

# 4. Debug Instrumentation and Bring-Up Readiness

Artifact | Current State
Baseline bitstream | Generated (no ILA)
Debug bitstream | Generated with 4 ILA cores
Probe coverage | 92 bits total
ILA timing | 100 MHz domain clean; 400 MHz debug path has negative slack and is marked debug-use
Net mapping strategy | Post-synth targeted net discovery + robust wildcard/pin-based resolution

Bring-up scripts are prepared and validated in flow: FPGA programming and structured ILA capture scenarios. This supports staged hardware execution from clock/reset sanity through DDC, matched filter, and range/doppler validation.

# 5. Development-Board Migration Strategy

Target | Top wrapper | Constraint file | Build script
Production | radar_system_top | constraints/xc7a200t_fbg484.xdc | project main flow
TE0712/TE0701 | radar_system_top_te0712_dev | constraints/te0712_te0701_minimal.xdc scripts/build_te0712_dev.tcl
TE0713/TE0701 | radar_system_top_te0713_dev | constraints/te0713_te0701_minimal.xdc scripts/build_te0713_dev.tcl

This split-target architecture isolates board-specific pinout and clocking decisions from core RTL, minimizing risk while enabling early hardware testing on in-stock modules.

# 6. Key Change Log (Current Generation)

Commit | Change Summary
f6877aa | Phase 1 bring-up prep: ILA debug probes, CDC waivers, programming scripts
12e63b7 | Hardened ILA insertion script (deferred core creation, net resolution, MU_CNT fix)
0ae7b40 | Added TE0712/TE0701 split target with dedicated top/XDC/build flow
967ce17 | Added TE0713/TE0701 alternate in-stock SoM target
fcdd270 | Published initial docs and report PDFs on GitHub Pages
94eed1e | Expanded into full multi-page engineering documentation site

# 7. Conclusion

AERIS-10 has transitioned from simulation-centric readiness into a hardware-targeted baseline with timing closure, robust debug instrumentation, and reproducible bring-up workflows. Remaining uncertainty is now primarily physical-board execution risk, not unresolved architecture or verification gaps. This report should be treated as the current state reference replacing older simulation-only summaries.

Report classification: Engineering baseline (current state).

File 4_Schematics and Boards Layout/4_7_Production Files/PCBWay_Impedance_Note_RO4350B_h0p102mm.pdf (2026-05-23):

# Controlled Impedance Note — RO4350B (h = 0.102

mm)

## Stackup Details

- Material: Rogers RO4350B
- Dielectric constant (Design Dk): 3.66 (diff-phase method)
- Dielectric constant (Process Dk): 3.48 ± 0.05 (IPC clamped)
- Dielectric thickness (h): 0.102 mm
- Copper thickness: 35 µm base, ~40–45 µm finished after plating
- Solder mask: None (maskless RF traces over air)
- Reference: Continuous ground plane directly beneath RF layer

## Targets

Differential pair (LVDS) | Zdiff = 100 Ω ± 8%
Single-ended reference | Z0 = 50 Ω ± 10%

## Starting Geometry (maskless microstrip)

Values are starting points for PCBWay CAM to field-solve and tune with coupons.

Assumption | 50 Ω microstrip (w, mm) | 100 Ω diff pair (w, mm) | 100 Ω diff pair (s edge-edge, mm)
Process Dk = 3.48 | 0.204 | 0.204 | 0.26
Design Dk = 3.66 | 0.195 | 0.195 | 0.26

## Alternate Option (keep w = 0.204 mm; adjust gap for Design Dk)

Assumption | w (mm) | s edge-edge (mm) | Expected Zdiff
Design Dk = 3.66 | 0.204 | 0.30 | ≈ 100–102 Ω

## Routing Rules

- Continuous reference plane; no splits/slots beneath the pair
- Point-to-point routing; no stubs or tees; equal via count per leg
- Intra-pair length match: ≤ 1–2 mm for 10.5 GHz RF; ≤ 5 mm for LVDS clocks
- No same-layer ground pour near the pair unless re-solved for CPWG
- If via fencing is used: via-center to outer trace edge ≈ 0.5 mm; pitch ≤ 1.0 mm; symmetric on both sides
- Receiver termination: 100 Ω differential (omit external if receiver provides internal 100 Ω)

## Coupon/Test Notes

- Provide impedance coupons for both 50 Ω microstrip and 100 Ω differential pair
- PCBWay may tune w by ±0.02–0.04 mm and/or s by ±0.03–0.05 mm to hit targets
- Return as-built geometry values (w, s) in the fab report

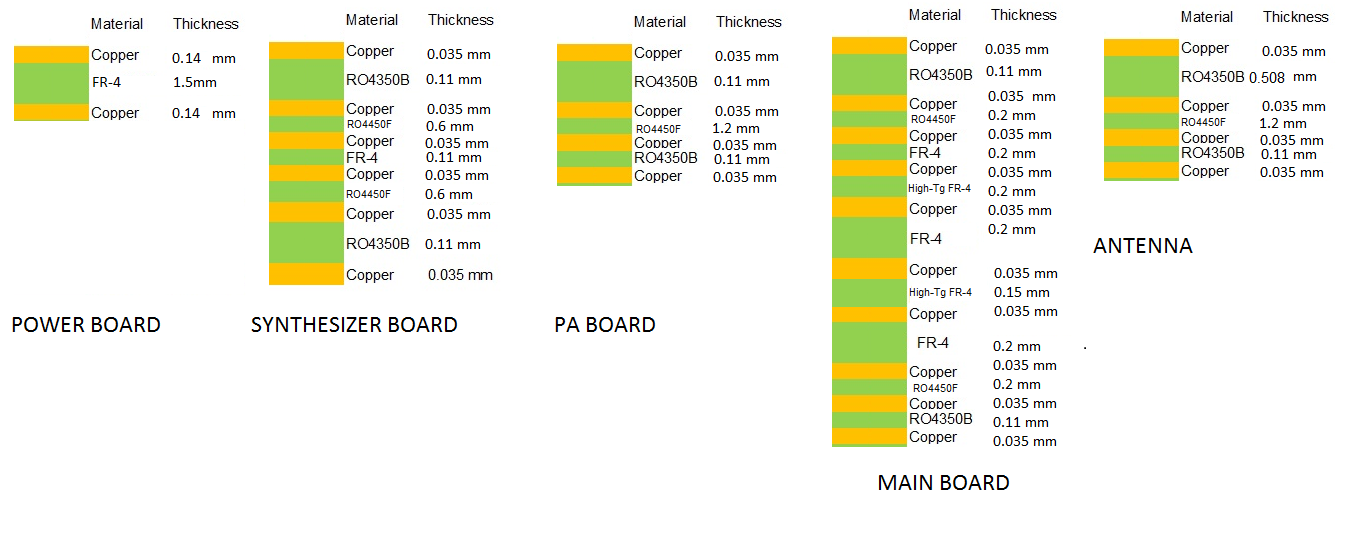
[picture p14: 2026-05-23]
4_Schematics and Boards Layout/4_4_Board Stack-up/Stack_Hybrid.png

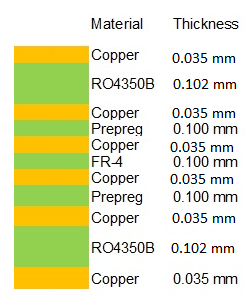
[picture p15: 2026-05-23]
4_Schematics and Boards Layout/4_6_Schematics/Stack_Hybrid.png

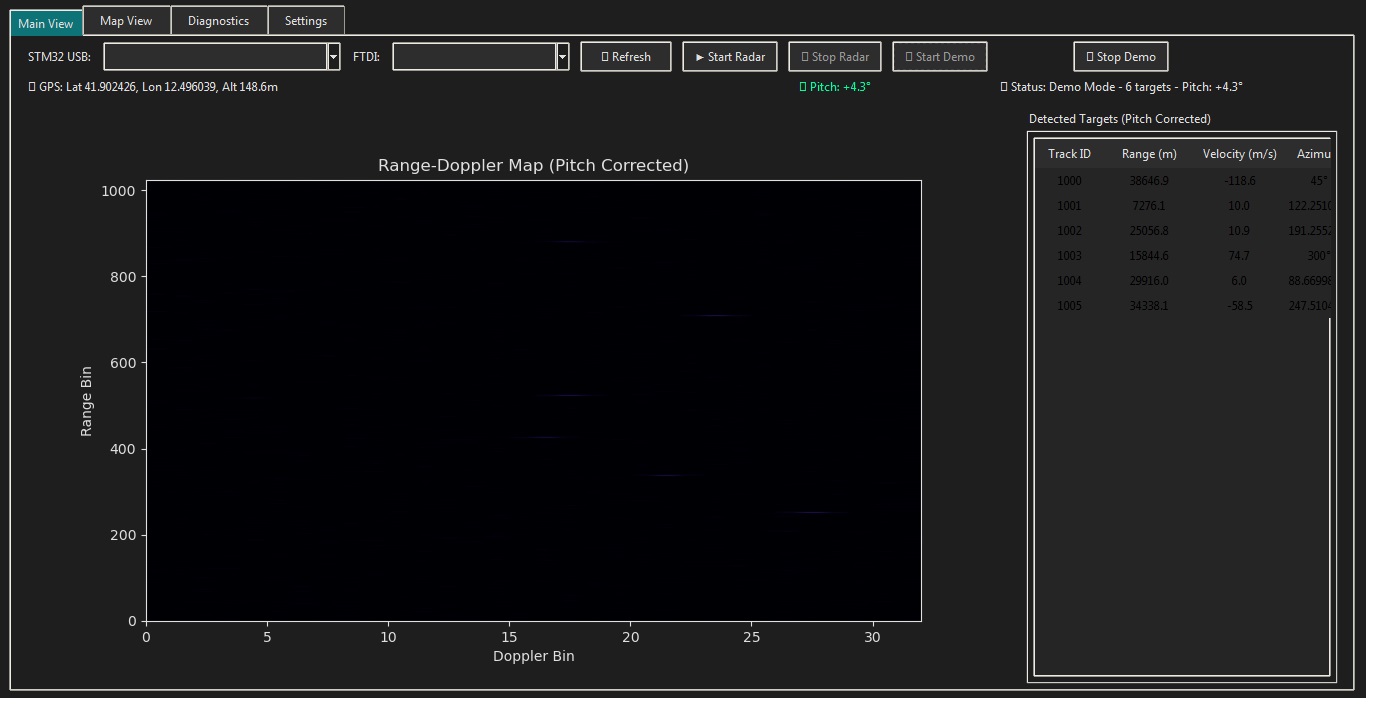
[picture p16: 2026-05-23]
docs/assets/img/GUI.jpg

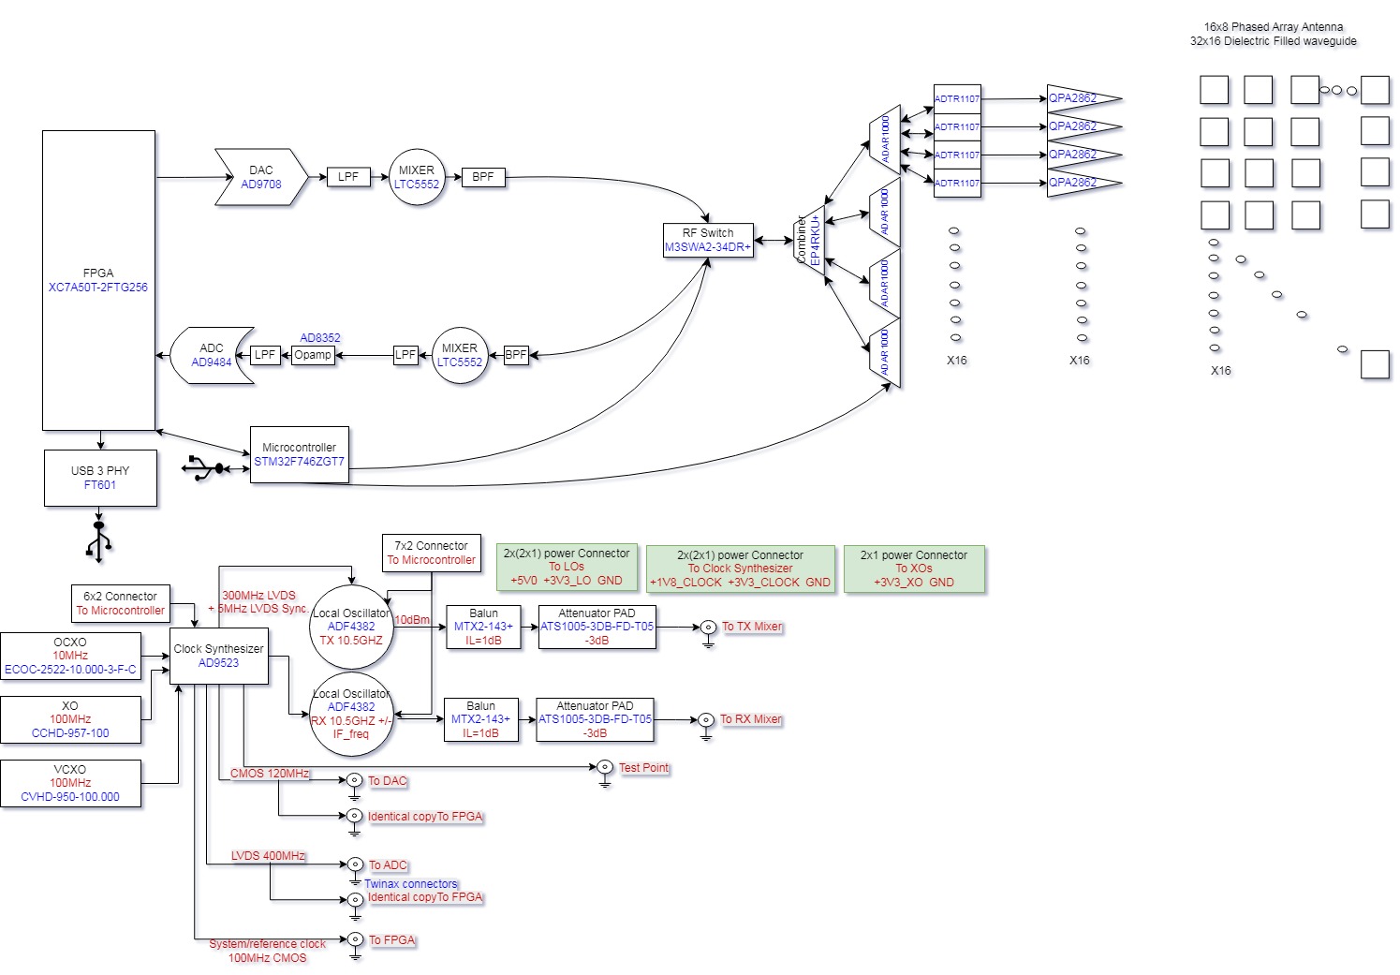
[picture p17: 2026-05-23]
docs/assets/img/RADAR_V6.jpg

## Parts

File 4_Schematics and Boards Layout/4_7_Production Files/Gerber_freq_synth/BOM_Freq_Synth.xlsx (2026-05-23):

Qty | Value | Device | Package | Parts | Description | MANUFACTURER_PART_NUMBER
5 |  | L-EUL5650M | L5650M | L9, L10, L11, L12, L13 | INDUCTOR, European symbol | HI2220P601R-10
1 |  | PINHD-2X6 | 2X06 | JP1 | PIN HEADER | 87834-1211 (https://eu.mouser.com/ProductDetail/Molex/87834-1211?qs=kNSQ05%252BLZoDv7br%252B0FPisw%3D%3D)
1 |  | PINHD-2X7 | 2X07 | JP2 | PIN HEADER | 90130-1314 (https://eu.mouser.com/ProductDetail/Molex/90130-1314?qs=kEwmkoUtv7Q0tkiQKJqMSw%3D%3D)
28 | 0.1µF | C-EUC0201 | C0201 | C16, C18, C20, C22, C24, C26, C28, C30, C32, C34, C35, C36, C37, C41, C42, C43, C44, C64, C65, C66, C67, C87, C88, C90, C91, C4, C5, C7 | CAPACITOR, European symbol | CL03A104KP3NNNH
1 | 0.1µf | C-EUC0201 | C0201 | C92 | CAPACITOR, European symbol | CL03A104KP3NNNH
2 | 0.33µF | C-EUC0201 | C0201 | C2, C6 | CAPACITOR, European symbol | 0201X334M6R3CT (https://eu.mouser.com/ProductDetail/Walsin/0201X334M6R3CT?qs=iLbezkQI%252Bsj6TtN1Mk8apQ%3D%3D)
2 | 0.47µF | C-EUC0201 | C0201 | C9, C10 | CAPACITOR, European symbol | CL03A474KP3NNNC
1 | 0.47µf | C-EUC0201 | C0201 | C3 | CAPACITOR, European symbol | CL03A474KP3NNNC
3 | 0.65k | R-EU_R0201 | R0201 | R6, R8, R10 | RESISTOR, European symbol | CPF0201B649RE1 (https://eu.mouser.com/ProductDetail/TE-Connectivity-Holsworthy/CPF0201B649RE1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)
9 | 0R | R-EU_R0201 | R0201 | R5, R14, R15, R19, R20, R27, R28, R32, R33 | RESISTOR, European symbol | RCA02010000ZSEDSR
8 | 1.3nH | L-USL0201 | L0201 | L1, L2, L3, L4, L5, L6, L7, L8 | INDUCTOR, American symbol | LQP03HQ1N3W02D (https://eu.mouser.com/ProductDetail/Murata-Electronics/LQP03HQ1N3W02D?qs=B6kkDfuK7%2FBCgkEUu6f9mw%3D%3D)
1 | 1000pF | C-EUC0201 | C0201 | C8 | CAPACITOR, European symbol | CL03B102KA3NNNC
4 | 100R | R-EU_R0201 | R0201 | R1, R12, R13, R26 | RESISTOR, European symbol | RC0201FR-07100RL
2 | 10nF | C-EUC0201 | C0201 | C61, C84 | CAPACITOR, European symbol | 0201B103K250NT
3 | 10nF | C-EUC0402 | C0402 | C15, C17, C19 | CAPACITOR, European symbol | GRM1555CYA103GE01J (https://eu.mouser.com/ProductDetail/Murata-Electronics/GRM1555CYA103GE01J?qs=d0WKAl%252BL4KbA7gCogz12ew%3D%3D)
6 | 10pF | C-EUC0201 | C0201 | C1, C62, C63, C85, C86, C89 | CAPACITOR, European symbol | CL03C100JA3GNNC
5 | 10µF | C-EUC1210 | C1210 | C23, C27, C31, C45, C47 | CAPACITOR, European symbol | MBASU32MAB7106KPNA01 (https://eu.mouser.com/ProductDetail/TAIYO-YUDEN/MBASU32MAB7106KPNA01?qs=tlsG%2FOw5FFjbKuqA1IZNFA%3D%3D)
11 | 142-0731-211 | 142-0731-211 | 1420731211 | J1, J2, J5, J6, J7, J8, J9, J10, J11, J12, J13 | SMA Connector Jack, Female Socket 50 Ohms Through Hole Solder | 142-0731-211
6 | 1k | R-EU_R0201 | R0201 | R2, R3, R4, R7, R9, R11 | RESISTOR, European symbol | 1-2176072-2 (https://eu.mouser.com/ProductDetail/TE-Connectivity-Holsworthy/1-2176072-2?qs=TqB%2FzLOUcHJkUvL3%2FB9tYg%3D%3D)
10 | 1µF | C-EUC0201 | C0201 | C11, C12, C13, C14, C59, C68, C69, C70, C71, C82 | CAPACITOR, European symbol | CL03A105MQ3CSNH
8 | 200k | R-EU_R0201 | R0201 | R22, R23, R24, R25, R35, R36, R37, R38 | RESISTOR, European symbol | RE0201BRE07200KL (https://eu.mouser.com/ProductDetail/YAGEO/RE0201BRE07200KL)
6 | 22-23-2021 | 22-23-2021 | 22-23-2021 | X10, X11, X12, X13, X14, X15 | .100 (2.54mm) Center Header - 2 Pin" | 22-23-2021
3 | 22R | R-EU_R0201 | R0201 | R39, R40, R41 | RESISTOR, European symbol | RT0201FRE0722RL (https://eu.mouser.com/ProductDetail/YAGEO/RT0201FRE0722RL)
6 | 22µF | C-EUC1210 | C1210 | C21, C25, C29, C33, C46, C51 | CAPACITOR, European symbol | MAAST32MSB7226MPNA01 (https://eu.mouser.com/ProductDetail/TAIYO-YUDEN/MAAST32MSB7226MPNA01?qs=FmjOKN4Os876lp2kR04m7Q%3D%3D)
2 | 30R | R-EU_R0201 | R0201 | R17, R30 | RESISTOR, European symbol | ERJ-U01J300C (https://eu.mouser.com/ProductDetail/Panasonic/ERJ-U01J300C)
2 | 31pF | C-EUC0201 | C0201 | C60, C83 | CAPACITOR, European symbol | GCM0335C1H300FA16J (https://eu.mouser.com/ProductDetail/Murata-Electronics/GCM0335C1H300FA16J?qs=5aG0NVq1C4ze9%252Bgr8KZLTg%3D%3D)
2 | 330R | R-EU_R0201 | R0201 | R18, R31 | RESISTOR, European symbol | RC0201FR-7D330RL (https://eu.mouser.com/ProductDetail/YAGEO/RC0201FR-7D330RL?qs=sGAEpiMZZMtlubZbdhIBINSnPd898yDP6M5V2P2FozI%3D)
20 | 4.7µF | C-EUC0201 | C0201 | C38, C39, C40, C48, C49, C50, C55, C56, C57, C58, C72, C73, C74, C75, C76, C77, C78, C79, C80, C81 | CAPACITOR, European symbol | GRM035R60J475ME15D (https://eu.mouser.com/ProductDetail/Murata-Electronics/GRM035R60J475ME15D?qs=I53XXhTNm8vhFCgPvCZ%252BPQ%3D%3D)
2 | 500R | R-EU_R0201 | R0201 | R21, R34 | RESISTOR, European symbol | CPF0201B499RE1 (https://eu.mouser.com/ProductDetail/TE-Connectivity-Holsworthy/CPF0201B499RE1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)
2 | 931R | R-EU_R0201 | R0201 | R16, R29 | RESISTOR, European symbol | CRCW0201931RFKED (https://eu.mouser.com/ProductDetail/Vishay/CRCW0201931RFKED)
1 | AD9523BCPZ | AD9523BCPZ | QFN50P1000X1000X100-73N | IC1 | AD9523BCPZ, PLL Clock Driver Dual, 72-Pin LFCSP VQ | AD9523BCPZ
2 | ADF4382ABCCZ | ADF4382ABCCZ | CC-48-10_ADI | U1, U6 |  | ADF4382ABCCZ
4 | ATS1005-3DB-FD-T05 | ATS1005-3DB-FD-T05 | SMT_DB-FD-T05_SUS | U4, U5, U8, U10 |  | ATS1005-3DB-FD-T05
2 | CJT-T-P-HH-ST-TH1 | CJT-T-P-HH-ST-TH1 | CONN_CJT-T-P-XX-ST-TH1_SAI | J3, J4 |  | CJT-T-P-HH-ST-TH1
2 | CVHD-950-50.000 | CVHD-950-50.000 | SMD4_CVHD-950_CRX | X5, X6 |  | CVHD-950-50.000
1 | ECOC-2522-100.000-3HC | ECOC-2522-100.000-3HC | SMD5_ECOC-2522_25P4X22_ECS | X4 |  | ECOC-2522-100.000-3HC
4 | FBMH1608HL601-T | FBMH1608HL601-T | BEADC1608X90N | FB1, FB2, FB3, FB4 |  | FBMH1608HL601-T
2 | Green | LED-GREEN-0603-WE | LED-0603 | D1, D2 | Green SMD LED | KB EELP41.12-P1R2-36-3X4X-5-R18
4 | MTX2-143+ | MTX2-143+ | DQ1225_MNC | U2, U3, U7, U9 |  | MTX2-143+

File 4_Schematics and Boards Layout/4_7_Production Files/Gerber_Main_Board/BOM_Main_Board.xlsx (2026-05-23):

Qty | Value | Device | Package | Parts | Description | MANUFACTURER_PART_NUMBER
11 |  | L-EUL5650M | L5650M | L1, L11, L12, L13, L14, L15, L16, L17, L18, L21, L23 | INDUCTOR, European symbol | HI2220P601R-10
1 |  | MA10-2 | MA10-2 | SV1 | PIN HEADER | MA10-2
1 |  | PINHD-1X2 | 1X02 | JP20 | PIN HEADER | Do Not Put
11 |  | PINHD-1X3 | 1X03 | JP4, JP5, JP6, JP10, JP11, JP12, JP14, JP15, JP16, JP17, JP19 | PIN HEADER | Do Not Put
3 |  | PINHD-1X4 | 1X04 | JP8, JP9, JP18 | PIN HEADER | Do Not Put
1 |  | PINHD-1X6 | 1X06 | JP2 | PIN HEADER | Do Not Put
1 |  | PINHD-1X8 | 1X08 | JP7 | PIN HEADER | Do Not Put
1 |  | PINHD-2X4 | 2X04 | JP3 | PIN HEADER | Do Not Put
1 |  | PINHD-2X6 | 2X06 | JP1 | PIN HEADER | 87834-1211 (https://eu.mouser.com/ProductDetail/Molex/87834-1211?qs=kNSQ05%252BLZoDv7br%252B0FPisw%3D%3D)
1 |  | PINHD-2X7 | 2X07 | JP13 | PIN HEADER | 90130-1314 (https://eu.mouser.com/ProductDetail/Molex/90130-1314?qs=kEwmkoUtv7Q0tkiQKJqMSw%3D%3D)
1 |  | SJ2W | SJ_2 | SJ1 | SMD solder JUMPER | Do Not Put
71 | 0.1uF | CC0201 | C0201 | C1, C2, C4, C5, C6, C7, C8, C9, C10, C11, C12, C13, C14, C15, C16, C36, C38, C39, C41, C42, C44, C45, C46, C47, C51, C52, C53, C56, C67, C69, C74, C80, C82, C125, C131, C133, C138, C140, C146, C148, C159, C160, C162, C168, C170, C175, C188, C189, C190, C192, C193, C194, C195, C196, C201, C203, C208, C210, C215, C217, C222, C224, C229, C231, C236, C238, C243, C245, C250, C252, C293 | CAPACITOR, European symbol | CL03A104KP3NNNH
4 | 0.1uF | C-EUC0402 | C0402 | C48, C49, C57, C58 | CAPACITOR, European symbol | GRM155R71C104KA88D
6 | 0.1uF | CC0201 | C0201 | C277, C278, C295, C297, C299, C301 | CAPACITOR, European symbol | CL03A104KP3NNNH
1 | 0.2pF | C-EUC0201 | C0201 | C43 | CAPACITOR, European symbol | GJM0335C1ER20WB01D
13 | 0.47uF | CC0201 | C0201 | C110, C111, C112, C113, C155, C156, C157, C158, C179, C180, C181, C182, C291 | CAPACITOR, European symbol | CL03A474KP3NNNC
1 | 0.6pF | C-EUC0201 | C0201 | C54 | CAPACITOR, European symbol | GJM0335C1ER60WB01D
4 | 0R | RR0201 | R0201 | R18, R19, R34, R35 | RESISTOR, European symbol | RCA02010000ZSEDSR
12 | 100R | RR0201 | R0201 | R2, R3, R4, R5, R6, R7, R8, R9, R10, R11, R12, R173 | RESISTOR, European symbol | RC0201FR-07100RL
28 | 100nF | C-EUC0402 | C0402 | C76, C78, C258, C259, C260, C262, C264, C266, C313, C317, C320, C324, C327, C331, C334, C337, C339, C341, C342, C343, C344, C345, C346, C347, C348, C349, C350, C351 | CAPACITOR, European symbol | GRM155R71C104KA88D
24 | 100nF | CC0201 | C0201 | C24, C25, C26, C27, C28, C29, C30, C32, C33, C34, C35, C50, C256, C257, C279, C281, C298, C302, C303, C304, C305, C306, C307, C310 | CAPACITOR, European symbol | CL03A104KP3NNNH
34 | 100pF | CC0201 | C0201 | C66, C68, C73, C79, C81, C124, C130, C132, C137, C139, C145, C147, C152, C161, C167, C169, C174, C183, C200, C202, C207, C209, C214, C216, C221, C223, C228, C230, C235, C237, C242, C244, C249, C251 | CAPACITOR, European symbol | 0201CG101J500NT
2 | 103pF | CC0201 | C0201 | C60, C63 | CAPACITOR, European symbol | MLASU063SCG101JFNA01
1 | 106pF | CC0201 | C0201 | C141 | CAPACITOR, European symbol | GRM0335C1H111GA01D
4 | 107.3nH | LL0201 | L0201 | L22, L25, L26, L27 | INDUCTOR, European symbol | MLG0603PR11JTD25
9 | 10k | RR0201 | R0201 | R39, R40, R83, R84, R111, R123, R145, R151, R153 | RESISTOR, European symbol | AC0201FR-0710KL
16 | 10nF | CC0201 | C0201 | C102, C103, C104, C105, C106, C107, C114, C115, C116, C117, C118, C119, C120, C121, C122, C123 | CAPACITOR, European symbol | 0201B103K250NT
2 | 10uF | CC0201 | C0201 | C37, C40 | CAPACITOR, European symbol | KGM03DS60E106MH
12 | 10uF | C-EUC0805 | C0805 | C75, C77, C312, C316, C319, C323, C326, C330, C333, C336, C338, C340 | CAPACITOR, European symbol | GRM21BR61E106KA73L
1 | 115R | R-EU_R0201 | R0201 | R14 | RESISTOR, European symbol | RC0201FR-07115RL
2 | 12nH | LL0201 | L0201 | L2, L8 | INDUCTOR, European symbol | LQP02TN12NH02D
2 | 12pF | CC0201 | C0201 | C184, C185 | CAPACITOR, European symbol | GRM0335C1E120JA01D
37 | 142-0731-211 | 142-0731-211 | 1420731211 | J1, J18, J20, J22, J23, J24, J25, J26, J27, J28, J29, J30, J31, J32, J33, J34, J35, J36, J37, J38, J39, J40, J41, J42, J43, J44, J45, J46, J47, J48, J49, J50, J51, J52, J53, J54, J55 | SMA Connector Jack, Female Socket 50 Ohms Through Hole Solder | 142-0731-211
2 | 159nH | LL0201 | L0201 | L3, L4 | INDUCTOR, European symbol | LQP03TNR16H02D
2 | 18pF | CC0201 | C0201 | C272, C274 | CAPACITOR, European symbol | GRM0335C1E180JA01D
1 | 1k | R-EU_R0402 | R0402 | R37 | RESISTOR, European symbol | RC0402FR-071KL
49 | 1k | RR0201 | R0201 | R41, R43, R55, R56, R57, R58, R59, R61, R82, R85, R86, R87, R88, R93, R94, R99, R100, R101, R102, R107, R108, R109, R118, R124, R125, R126, R127, R128, R129, R130, R131, R133, R134, R135, R136, R137, R138, R139, R140, R144, R147, R148, R149, R167, R168, R169, R170, R171, R172 | RESISTOR, European symbol | 1-2176072-2 (https://eu.mouser.com/ProductDetail/TE-Connectivity-Holsworthy/1-2176072-2?qs=TqB%2FzLOUcHJkUvL3%2FB9tYg%3D%3D)
1 | 1k2_1% | RR0201 | R0201 | R60 | RESISTOR, European symbol | RC0201FR-071K2L
7 | 1nF | C-EUC0402 | C0402 | C314, C318, C321, C325, C328, C332, C335 | CAPACITOR, European symbol | CL03B102KA3NNNC
51 | 1pF | CC0201 | C0201 | C70, C71, C72, C83, C84, C85, C126, C128, C129, C134, C135, C136, C142, C143, C144, C149, C150, C151, C163, C165, C166, C171, C172, C173, C197, C198, C199, C204, C205, C206, C211, C212, C213, C218, C219, C220, C225, C226, C227, C232, C233, C234, C239, C240, C241, C246, C247, C248, C253, C254, C255 | CAPACITOR, European symbol | GJM0335C1E1R0WB01D
16 | 1uF | CC0201 | C0201 | C86, C87, C88, C89, C90, C91, C92, C93, C94, C95, C96, C97, C98, C99, C100, C101 | CAPACITOR, European symbol | CL03A105MQ3CSNH
3 | 1uF | CC0201 | C0201 | C276, C296, C300 | CAPACITOR, European symbol | CL03A105MQ3CSNH
1 | 2.2k | RR0201 | R0201 | R146 | RESISTOR, European symbol | RC0201FR-072K2L
3 | 2.2uF | CC0201 | C0201 | C22, C23, C164 | CAPACITOR, European symbol | GRM033R60J225ME47D
16 | 2.443k | RR0201 | R0201 | R89, R90, R91, R92, R95, R96, R97, R98, R103, R104, R105, R106, R119, R120, R121, R122 | RESISTOR, European symbol | RC0201FR-072K44L
1 | 2.7pF | C-EUC0402 | C0402 | C3 | CAPACITOR, European symbol | GJM1555C1H2R7WB01D
2 | 2.7pF | CC0201 | C0201 | C18, C19 | CAPACITOR, European symbol | GJM0335C1E2R7WB01D
4 | 200R | RR0201 | R0201 | R16, R17, R20, R21 | RESISTOR, European symbol | RC0201FR-07200RL
1 | 20k | R-EU_R0402 | R0402 | R38 | RESISTOR, European symbol | RC0402FR-0720KL
40 | 22-23-2021 | 22-23-2021 | 22-23-2021 | X1, X4, X5, X6, X7, X8, X9, X10, X11, X12, X13, X14, X15, X16, X17, X18, X19, X20, X21, X22, X24, X54, X55, X56, X_1, X_2, X_3, X_4, X_5, X_6, X_7, X_8, X_9, X_10, X_11, X_12, X_13, X_14, X_15, X_16 | .100 (2.54mm) Center Header - 2 Pin" | 22-23-2021
16 | 22-23-2031 | 22-23-2031 | 22-23-2031 | X3, X38, X39, X40, X41, X42, X43, X44, X45, X46, X47, X48, X49, X50, X51, X52 | .100 (2.54mm) Center Header - 3 Pin" | 22-23-2031
11 | 22.1k | RR0201 | R0201 | R154, R155, R156, R157, R158, R159, R160, R161, R162, R163, R164 | RESISTOR, European symbol | RC0201FR-0722K1L
13 | 22R | RR0201 | R0201 | R23, R24, R25, R26, R27, R28, R29, R30, R49, R51, R62, R63, R64 | RESISTOR, European symbol | RC0201FR-0722RL
2 | 22pF | CC0201 | C0201 | C308, C309 | CAPACITOR, European symbol | GRM0335C1E220JA01D
5 | 22uF | C-EUC1206 | C1206 | C283, C311, C315, C322, C329 | CAPACITOR, European symbol | GRM31CR61E226ME15L
2 | 24R | R-EU_R0402 | R0402 | R1, R13 | RESISTOR, European symbol | RC0402FR-0724RL
2 | 25R | RR0201 | R0201 | R165, R166 | RESISTOR, European symbol | RC0201FR-0725RL
4 | 25pF | CC0201 | C0201 | C64, C65, C268, C270 | CAPACITOR, European symbol | GRM0335C1E250JA01D
1 | 3.3uF | CC0201 | C0201 | C191 | CAPACITOR, European symbol | GRM033R60J335ME47D
2 | 32.8pF | CC0201 | C0201 | C59, C127 | CAPACITOR, European symbol | GJM0335C1E330JB01D
1 | 3k2 | RR0201 | R0201 | R33 | RESISTOR, European symbol | RC0201FR-073K2L
2 | 4.3k | R-EU_R0201 | R0201 | R15, R32 | RESISTOR, European symbol | RC0201FR-074K3L
2 | 4.3pF | CC0201 | C0201 | C20, C21 | CAPACITOR, European symbol | GJM0335C1E4R3WB01D
27 | 4.7k | RR0201 | R0201 | R42, R44, R45, R46, R47, R48, R50, R52, R53, R54, R65, R66, R67, R68, R69, R70, R71, R72, R73, R74, R75, R76, R77, R117, R141, R142, R143 | RESISTOR, European symbol | RC0201FR-074K7L
16 | 4.7nF | CC0201 | C0201 | C261, C263, C265, C267, C269, C271, C273, C275, C280, C282, C284, C286, C288, C290, C292, C294 | CAPACITOR, European symbol | GRM033R71E472KA88D
8 | 4.7uF | CC0201 | C0201 | C108, C109, C153, C154, C177, C178, C287, C289 | CAPACITOR, European symbol | GRM033R60J475ME47D
2 | 4.7uF 35V | 4.7UF-POLAR-EIA3528-35V-10%(TANT) | EIA3528 | C186, C187 |  | 595D475X9035B2T
1 | 47nF | CC0201 | C0201 | C31 | CAPACITOR, European symbol | GRM033R71E473KA88D
4 | 4.7uF | CC0201 | C0201 | C17, C55, C176, C285 | CAPACITOR, European symbol | CM03X5R475M06AH055
4 | 500R | RR0201 | R0201 | R110, R112, R113, R114 | RESISTOR, European symbol | RC0201FR-07500RL
3 | 50R | RR0201 | R0201 | R31, R115, R116 | RESISTOR, European symbol | RC0201FR-0750RL
4 | 50nH | LL0201 | L0201 | L9, L10, L24, L28 | INDUCTOR, European symbol | CE0603M-51NH
1 | 56R | R-EU_R0201 | R0201 | R22 | RESISTOR, European symbol | RC0201FR-0756RL
3 | 5R | RR0201 | R0201 | R132, R150, R152 | RESISTOR, European symbol | RC0201FR-075R1L
2 | 7.8pF | CC0201 | C0201 | C61, C62 | CAPACITOR, European symbol | GJM0335C1E7R8WB01D
1 | 830R | R-EU_R0402 | R0402 | R36 | RESISTOR, European symbol | RC0402FR-07830RL
4 | 840R | RR0201 | R0201 | R78, R79, R80, R81 | RESISTOR, European symbol | RC0201FR-07840RL
2 | AD8352ACPZ-R7 | AD8352ACPZ-R7 | CP_16_3_ADI | U4, U8 |  | AD8352ACPZ-R7
1 | AD9484BCPZ-500 | AD9484BCPZ-500 | CP_56_5_ADI | U1 |  | AD9484BCPZ-500
1 | AD9708AR | AD9708AR | RW_28_ADI | U3 |  | AD9708AR
4 | ADAR1000ACCZN | ADAR1000ACCZN | CC-88-1_ADI | ADAR1_, ADAR2_, ADAR3_, ADAR4_ |  | ADAR1000ACCZN
3 | ADS7830IPWR | ADS7830IPWR | PW16 | U10, U88, U89 |  | ADS7830IPWR
16 | ADTR1107ACCZ | ADTR1107ACCZ | CC-24-8_ADI | ADTR1107_1, ADTR1107_2, ADTR1107_3, ADTR1107_4, ADTR1107_5, ADTR1107_6, ADTR1107_7, ADTR1107_8, ADTR1107_9, ADTR1107_10, ADTR1107_11, ADTR1107_12, ADTR1107_13, ADTR1107_14, ADTR1107_15, ADTR1107_16 |  | ADTR1107ACCZ
1 | AT93C46A-10SQ-2.7 | AT93C46A-10SQ-2.7 | SOIC8 | IC1 | Three-wire Automotive Temperature Serial EEPROM 1K (64 x 16) | AT93C46A-10SQ-2.7
5 | BLM15HB121SN1 | BLM15HB121SN1 | L0402 | L5, L6, L7, L19, L20 | EMIFIL (R) Chip Ferrite Bead for GHz Noise | BLM15PE121SH1D
2 | BPF2 | BPF2 | BPF2 | U$2, U$3 |  | Not a component
4 | Blue | LED-BLUE0603 | LED-0603 | D2, D3, D4, D5 | Blue SMD LED | KB EELP41.12-P1R2-36-3X4X-5-R18
2 | CJT-T-P-HH-ST-TH1 | CJT-T-P-HH-ST-TH1 | CJTTPHHSTTH1 | J19, J21 | Conn Twinax F 0Hz to 4GHz 100Ohm Solder ST Thru-Hole Gold | CJT-T-P-HH-ST-TH1
2 | DAC5578SRGET | DAC5578SRGET | RGE24_2P7X2P7 | U7, U69 |  | DAC5578SRGET
1 | ECS-120-10-36B2-JTN-TR | CRYSTAL-12MHZ | CRYSTAL-SMD-2X2.5MM | Y1 | 12.0MHz Crystal | ECS-120-10-36B2-JTN-TR
1 | EP4RKU+ | EP4RKU+ | DG1677-2_MNC | U16 |  | EP4RKU+
1 | FT2232HQ | FT2232HQ | 64QFN_FT2232HQ_FTD | U6 |  | FT2232HQ
16 | INA241A3IDGKRDGK0008A-MFG | INA241A3IDGKRDGK0008A-MFG | DGK0008A-MFG | U11, U73, U74, U75, U76, U77, U78, U79, U80, U81, U82, U83, U84, U85, U86, U87 |  | INA241A3IDGKR
2 | LTC5552IUDBTRMPBF | LTC5552IUDBTRMPBF | UDB_12_ADI | U5, U13 |  | LTC5552IUDB#TRMPBF
17 | M3SWA2-34DR+ | M3SWA2-34DR+ | 16_QFN | RF_SW_1, RF_SW_2, RF_SW_3, RF_SW_4, RF_SW_5, RF_SW_6, RF_SW_7, RF_SW_8, RF_SW_9, RF_SW_10, RF_SW_11, RF_SW_12, RF_SW_13, RF_SW_14, RF_SW_15, RF_SW_16, U$1 |  | M3SWA2-34DR+
2 | MINI-USB-32005-201 | MINI-USB-32005-201 | 32005-201 | X2, X53 | MINI USB-B Conector | 10118192-0002LF
1 | MOMENTARY-SWITCH-SPST-SMD-4.6X2.8MM | MOMENTARY-SWITCH-SPST-SMD-4.6X2.8MM | TACTILE_SWITCH_SMD_4.6X2.8MM | S1 | Momentary Switch (Pushbutton) - SPST | EVQP0E07K
1 | MT25QL01GBBB8E12-0AUT | MT25QL01GBBB8E12-0AUT | BGA24_MT25QL_MRN | U9 |  | MT25QL01GBBB8E12-0AUT
1 | NX3215SA-32.768KHz | NX3225GD-8MHZ-STD-CRA-3 | XTAL_NX3225GD-8MHZ-STD-CRA-3_N | XTAL3 |  | NX3215SA-32.768K-STD-MUS-2
1 | NX3225GD-8MHZ-STD-CRA-3 | NX3225GD-8MHZ-STD-CRA-3 | XTAL_NX3225GD-8MHZ-STD-CRA-3_N | XTAL1 |  | NX3225GD-8MHZ-STD-CRA-3
4 | OPA4703EA/250 | OPA4703EA/250 | PW14 | OPA_1, OPA_2, OPA_3, OPA_4 |  | OPA4703EA/250
1 | STM32F746ZGT7 | STM32F746ZGT7 | LQFP-144_STM | U2 |  | STM32F746ZGT7
34 | SZMMSZ5232BT1G | SZMMSZ5232BT1G | SOD-123_ONS | U14, U15, U17, U37, U38, U39, U40, U41, U43, U44, U45, U46, U47, U48, U49, U50, U51, U52, U53, U54, U55, U56, U57, U58, U59, U60, U61, U62, U63, U64, U65, U66, U67, U68 |  | SZMMSZ5232BT1G
1 | XC7A50T-2FTG256I | XC7A50T-2FTG256I | BGA256C100P16X16_1700X1700X155 | U42 | Artix-7 Field Programmable Gate Array (FPGA) IC 170 2764800 52160 256-LBGA Check availability | XC7A50T-2FTG256I

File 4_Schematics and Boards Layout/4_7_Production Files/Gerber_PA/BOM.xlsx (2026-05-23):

Qty | Value | Device | Package | Parts | Description | MANUFACTURER_PART_NUMBER | MPN | OC_FARNELL | OC_NEWARK
1 |  | AK300/2 | AK300/2 | 22V | CONNECTOR |  |  | unknown | unknown
6 | 0.1µF | C-EUC0402 | C0402 | C2, C3, C6, C7, C8, C9 | CAPACITOR, European symbol
6 | 0R | R-EU_R0402 | R0402 | R2, R3, R5, R7, R8, R9 | RESISTOR, European symbol
1 | 0R | R-EU_R0603 | R0603 | R6 | RESISTOR, European symbol
2 | 10R | R-EU_R0402 | R0402 | R1, R4 | RESISTOR, European symbol
3 | 10µF | C-EUC1206 | C1206 | C1, C4, C5 | CAPACITOR, European symbol
2 | 142-0731-211 | 142-0731-211 | 1420731211 | J1, J2 | SMA Connector Jack, Female Socket 50 Ohms Through Hole Solder | 142-0731-211
1 | 22-23-2021 | 22-23-2021 | 22-23-2021 | X2 | .100 (2.54mm) Center Header - 2 Pin" |  | 22-23-2021 | 1462926 | 25C3832
1 | 22-23-2031 | 22-23-2031 | 22-23-2031 | X3 | .100 (2.54mm) Center Header - 3 Pin" |  | 22-23-2031 | 1462950 | 30C0862
1 | 5mR | WSL2816R1000FEH | WSL2816_VIS | R10 |  | WSL2816R1000FEH
1 | QPA2962_B | QPA2962_B | QPA2962_B | U$1

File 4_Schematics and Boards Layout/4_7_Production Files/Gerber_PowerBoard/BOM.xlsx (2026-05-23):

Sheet: Feuil1
DESIGNATOR | Qty | *Mfg Part # | Value | Device | Package | Description | DESCRIPTION |  |  |  |  |  |  |  |  | unknown | unknown | 16
X1 | 1 |  |  | AK300/2 | AK300/2 | CONNECTOR |  |  |  |  |  |  |  |  |  | unknown | unknown | 3
SV1 | 1 |  |  | MA10-2 | MA10-2 | PIN HEADER |  |  |  |  |  |  |  |  |  |  |  | 88 |  | C
C1, C6, C12, C18, C29, C30, C36, C42, C54, C60, C66, C71, C76, C77, C83, C89, C109, C119, C129, C144, C154 | 21 |  | 0.1µF | C-EUC0805 | C0805 | CAPACITOR, European symbol |  |  |  |  |  |  |  |  |  |  |  | 45 |  | R
R2, R4, R6, R8, R10, R12, R14, R16, R18, R20, R22, R24, R26, R28, R30, R32, R34, R36, R38, R40, R42, R44, R46, R48, R50, R52, R56 | 27 |  | 10k | R-EU_M0805 | M0805 | RESISTOR, European symbol |  |  |  |  |  |  |  |  |  |  |  | 73 |  | C
C150, C152, C160, C162 | 4 |  | 10nF | C-EUC0603 | C0603 | CAPACITOR, European symbol |  |  |  |  |  |  |  |  |  |  |  | 73 |  | C
C151, C153, C161, C163 | 4 |  | 10µF | C-EUC0603 | C0603 | CAPACITOR, European symbol |  |  |  |  |  |  |  |  |  |  |  | 88 |  | C
C4, C5, C9, C10, C15, C16, C21, C22, C24, C25, C28, C33, C34, C39, C40, C45, C46, C50, C51, C52, C53, C57, C58, C63, C64, C69, C70, C74, C75, C80, C81, C86, C87, C92, C93, C94, C95, C108, C112, C113, C114, C115, C118, C122, C123, C124, C125, C128, C132, C133, C134, C135, C138, C139, C140, C143, C147, C148, C157, C158 | 60 |  | 10µF | C-EUC0805 | C0805 | CAPACITOR, European symbol |  |  |  |  |  |  |  |  |  |  |  | 45 |  | R
R54, R58 | 2 |  | 11.5k | R-EU_M0805 | M0805 | RESISTOR, European symbol |  |  |  |  |  |  |  |  |  |  |  | 45 |  | R
R9, R35, R43, R47 | 4 |  | 12k | R-EU_M0805 | M0805 | RESISTOR, European symbol |  |  |  |  |  |  |  |  |  |  |  | 45 |  | R
R3 | 1 |  | 13.7k | R-EU_M0805 | M0805 | RESISTOR, European symbol |  |  |  |  |  |  |  |  |  |  |  | 88 |  | C
C26, C27, C106, C107, C116, C117, C126, C127, C136, C137, C141, C142 | 12 |  | 1µF | C-EUC0805 | C0805 | CAPACITOR, European symbol
U$1, U$2 | 2 |  | 2.2µH | POWER_INDUCTOR | IND_VLP8040T-1R0N_TDK |  |  |  |  |  | MOLEX |  |  |  | 22-23-2021 | 1462926 | 25C3832 | 40
X2, X3, X4, X5, X6, X7, X8, X9, X10, X11, X12, X13, X14, X15, X16, X17, X18, X19, X20, X21, X22, X23, X24, X25, X26, X27, X28, X29, X30, X31, X32, X33, X34, X35, X36 | 35 |  | 22-23-2021 | 22-23-2021 | 22-23-2021 | .100 (2.54mm) Center Header - 2 Pin" |  |  |  |  |  |  |  |  |  |  |  | 73 |  | C
C2, C3, C7, C8, C11, C13, C14, C17, C19, C20, C23, C31, C32, C35, C37, C38, C41, C43, C44, C47, C48, C49, C55, C56, C59, C61, C62, C65, C67, C68, C72, C73, C78, C79, C82, C84, C85, C88, C90, C91, C110, C111, C120, C121, C130, C131, C145, C146, C149, C155, C156, C159 | 52 |  | 22µF | C-EUC0603 | C0603 | CAPACITOR, European symbol |  |  |  |  |  |  |  |  |  |  |  | 45 |  | R
R49 | 1 |  | 23.4k | R-EU_M0805 | M0805 | RESISTOR, European symbol |  |  |  |  |  |  |  |  |  |  |  | 45 |  | R
R39 | 1 |  | 2k | R-EU_M0805 | M0805 | RESISTOR, European symbol |  |  |  |  |  |  |  |  |  |  |  | 45 |  | R
R1 | 1 |  | 3.09k | R-EU_M0805 | M0805 | RESISTOR, European symbol
U$3, U$4, U$5, U$6, U$7, U$8, U$9, U$10, U$11, U$12, U$13, U$14, U$15, U$16, U$17, U$18, U$19, U$20, U$21 | 19 |  | 3.3µH | POWER_INDUCTOR | IND_VLP8040T-1R0N_TDK |  |  |  |  |  |  |  |  |  |  |  |  | 45 |  | R
R5, R7, R11, R13, R15, R19 | 6 |  | 32.2k | R-EU_M0805 | M0805 | RESISTOR, European symbol |  |  |  |  |  |  |  |  |  |  |  | 45 |  | R
R21 | 1 |  | 34.8k | R-EU_M0805 | M0805 | RESISTOR, European symbol |  |  |  |  |  |  |  |  |  |  |  | 45 |  | R
R53, R57 | 2 |  | 35.7k | R-EU_M0805 | M0805 | RESISTOR, European symbol |  |  |  |  |  |  |  |  |  |  |  | 45 |  | R
R17, R23, R25, R27, R29, R31, R37, R41, R45, R51, R55 | 11 |  | 56.2k | R-EU_M0805 | M0805 | RESISTOR, European symbol |  |  |  |  |  |  |  |  |  |  |  | 45 |  | R
R33 | 1 |  | 61.9k | R-EU_M0805 | M0805 | RESISTOR, European symbol |  |  | Analog Devices Inc | ADM7151ACPZ-04-R7
U5, U23, U25, U27, U29, U30 | 6 |  | ADM7151ACPZ-04-R7 | ADM7151ACPZ-04-R7 | CP_8_11_ADI |  | 800 mA Ultralow Noise, High PSRR, RF Linear Regulator |  |  | LM2662MX/NOPB |  | Texas Instruments |  |  |  |  |  |  |  |  | LM2662M
U18, U19, U20, U21, U22 | 5 |  | LM2662MX/NOPB | LM2662MX/NOPB | M08A |  |  | 1.5mm | KEMET | T521W476M020ATE045 |  |  | 80-T521W476M20ATE045 | https://www.mouser.co.uk/ProductDetail/KEMET/T521W476M020ATE045?qs=Ad%252Bh9aq9FyVtchBw1jwoFA%3D%3D
C96, C97, C98, C99, C100, C101, C102, C103, C104, C105 | 10 |  | T521W476M020ATE045 | T521W476M020ATE045 | T521W | T521, Tantalum, Polymer Tantalum, Commercial Grade, 47 uF, 20%, 20 VDC, 105C, -55C, 105C, SMD, Polymer, Molded, Low Profile/ESR, NonCombustible, 2,000 Hrs, 9 % , 45 mOhms, 94 uA, 222.95 mg, 7343, 1.4mm, Height Max = 1.5mm, 1000, 52 Weeks | T521, Tantalum, Polymer Tantalum, Commercial Grade, 47 uF, 20%, 20 VDC, 105C, -55C, 105C, SMD, Polymer, Molded, Low Profile/ESR, NonCombustible, 2,000 Hrs, 9 % , 45 mOhms, 94 uA, 222.95 mg, 7343, 1.4mm, Height Max = 1.5mm, 1000, 52 Weeks |  | Texas Instruments | TPS562208DDCT |  |  |  |  |  |  |  |  | RefDes |  | TYPE
U1, U2, U3, U4, U6, U7, U8, U9, U10, U11, U12, U13, U14, U15, U16, U17, U24, U26, U28, U31, U33 | 21 |  | TPS562208DDCT | TPS562208DDCT | DDC0006A_N |  | 4.5 V to 17 V input, 2 A output, synchronous step-down converter in FCCM mode 6-SOT-23-THIN -40 to 125 |  | Texas Instruments | TPS7A8300RGRR
U32, U34 | 2 |  | TPS7A8300RGRR | TPS7A8300RGRR | RGR20_2P05X2P05_TEX |  | 2-A, low-VIN, low-2-A, low-VIN, low-noise, ultra-low-dropout voltage regulator with power good wi 20-VQFN -40 to 125

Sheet: Feuil2
Item # | *Designator | *Qty | Manufacturer | *Mfg Part # | Description / Value | *Package/Footprint | Type | Your Instructions / Notes | HEIGHT | MANUFACTURER_NAME | MANUFACTURER_PART_NUMBER | MF | MFR_NAME | MOUSER_PART_NUMBER | MOUSER_PRICE-STOCK | MPN | OC_FARNELL | OC_NEWARK | POPULARITY | REFDES | SPICEPREFIX | TYPE

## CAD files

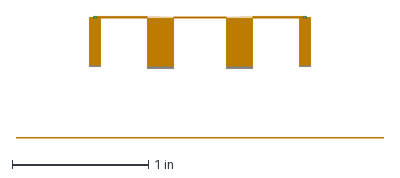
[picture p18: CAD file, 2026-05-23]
5_Simulations/Sim_BPF_Te_100um/Drawing1.dxf
2.70 x 0.892 in

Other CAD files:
8_Utils/Mechanical_Drawings/Heat_Sink_Main_Board.dwg
4_Schematics and Boards Layout/4_6_Schematics/Antennas/Waveguide/DFSWA.dwg
8_Utils/Mechanical_Drawings/Enclosure.dwg
8_Utils/Mechanical_Drawings/SlipRing.dwg
8_Utils/Mechanical_Drawings/RADAR_V1.dwg
8_Utils/Mechanical_Drawings/Upper_Part_Waveguide.dwg
8_Utils/Mechanical_Drawings/Down_Part_Waveguide.dwg
8_Utils/Mechanical_Drawings/Heat_Sink_PA.dwg

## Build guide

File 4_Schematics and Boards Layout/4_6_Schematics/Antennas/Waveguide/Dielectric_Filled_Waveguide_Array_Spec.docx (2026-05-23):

# Dielectric-Filled Waveguide Phased Array Antenna — Specifications & Deliverables

Date: 2025-08-13 | Version: 1.0 | Prepared by: Nawfal MOTII

# Project Overview

High-power, dielectric-filled rectangular waveguide phased array antenna for X-band operation. The array comprises 16 parallel waveguide columns, each with 32 longitudinal slots (travelling wave architecture), separated at λ₀/2 to enable ±60° electronic steering across columns. High purity alumina (Al₂O₃, 99.5–99.8%) is used as the dielectric fill to reduce cross section while maintaining low loss and robust thermal performance.

# Key Specifications (Customer Inputs)

Operating Frequency (f₀) | 10.5 GHz
Array Topology | 16 columns × 32 slots/column (travelling‑wave, terminated)
Inter‑column Pitch (dᵧ) | λ₀/2 ≈ 14.28 mm at 10.5 GHz
Dielectric Material | High‑purity alumina (Al₂O₃, 99.5–99.8%)
Microwave Power | 15 W per column (total 240 W)
Feed Type | 16 SMA connectors (one per waveguide column)
Total Gain (broadside) | ≥ 31 dBi
Electronic Steering Range | ±60° (across waveguide columns)

# Derived / Recommended Specifications

Free‑space wavelength (λ₀) | 28.55 mm
Guide cross‑section (internal) | a = 8.5 mm, b = 3.5 mm (alumina‑filled)
TE₁₀ cutoff (f_c10) | 5.63 GHz
Higher-order cutoffs | TE₂₀ ≈ 11.27 GHz, TE₀₁ ≈ 13.68 GHz (both > 10.5 GHz)
Guide wavelength (λ_g) | 10.81 mm
Slot spacing (s = λ_g/2) | 5.40 mm
Starter slot length (L_s≈0.47λ_g) | 5.08 mm
Column length (32 slots incl. margins) | 0.173 m
Panel height (16 columns) | 0.223 m
Geometric aperture (A=L·H) | 0.0385 m²
Ideal directivity | 27.73 dBi
EIRP at 240 W, G=31 dBi | 54.8 dBW

# Electrical Performance Targets

- Return loss (S₁₁) per column: ≤ −12 dB at 10.5 GHz; ≤ −10 dB across 10.25–10.75 GHz.
- Gain (boresight): ≥ 31 dBi; design goal 31–32 dBi with Taylor −25 dB taper.
- Sidelobe level (broadside, both principal planes): ≤ −23 dB (goal ≤ −25 dB).
- Cross‑polarization: ≤ −20 dB within main beam (goal ≤ −25 dB).
- Scan performance across columns: continuous scan to ±60°; scan loss ≤ 2 dB at 60°.
- Polarization: Linear
- Input impedance per column: nominal 50 Ω at feed; probe placed ≈ λ_g/4 from short.
- Phase shifter resolution recommendation: ≤ 5.6° LSB (≈ 1° angle steps near boresight).

# Mechanical & Materials

- Waveguide body: aluminum or copper alloy split-block; internal a=8.5 mm, b=3.5 mm (dielectric-filled).
- Dielectric: high-purity alumina (Al₂O₃ 99.5–99.8%); full fill or partial sidewall slabs (per EM optimization).
- Connectors: 16× SMA female bulkhead (power rated at X band); one per column.
- Feed geometry: coax probe feed located ≈ λ_g/4 from shorted back wall, centered (or tuned offset) in y.
- Manufacturing tolerances: slot length ±0.05 mm; slot offset ±0.03 mm; slot center position ±0.05 mm; flatness per length ≤ 0.05 mm/100 mm.
- Surface finish: Ra ≤ 1.6 µm in the RF volume; deburr and radius sharp edges.
- Optional plating: silver or electroless nickel (ENIG) as agreed; document any thickness effects.
- Optional pressurization: dry air/N₂ up to 1–2 bar for breakdown margin (include seals if required).

# Thermal & Power

- Per column CW power: 15 W; total 240 W distributed across 16 columns.
- Continuous operation over ambient −20 °C to +60 °C (goal; to be confirmed).
- Internal temperature rise limited such that dielectric and adhesives remain within ratings (supplier datasheets).

# Interfaces & Control

- RF inputs: 16 SMA female bulkhead connectors, 50 Ω.
- Beam steering: progressive phase per column (external phase shifters on customer PCB).
- Reference coordinate system and connector numbering: as per final assembly drawing.

# Verification & Test (Acceptance Criteria)

- VNA measurements: S₁₁ per column and inter column over 9–12 GHz; provide plots and Touchstone (.sNp/.s2p) and CSV.
- Anechoic chamber: boresight gain and 2D patterns at 10.3/10.5/10.7 GHz; provide polar plots and CSV.
- Scan patterns: measured principal plane cuts at θ = 0°, ±30°, ±45°, ±60° with specified phase sets; CSV exports.
- Near field to far field transform acceptable if chamber size limits; include processing details.
- Power run: operate at 15 W/column CW for 30 minutes; verify no arcing, no detuning beyond specs.
- Dimensional inspection: slot length/offset/spacing, column pitch, connector positions per tolerances.

# Deliverables

- Final 3D CAD: STEP (.stp) and/or Parasolid (.x_t); panel assembly and split‑block parts.
- 2D manufacturing drawings (PDF + native CAD) with full dimensions and tolerances.
- DXF/DWG: slot patterns, connector hole locations, and any gasket/seal cutouts.
- Materials list / BOM: metals, dielectric (alumina), fasteners, plating, adhesives, gaskets, finishes.
- EM simulation package: project files (HFSS/CST), simulation settings, and parametric studies.
- Simulation results: • S‑parameters 9–12 GHz (plots + Touchstone + CSV) • Input impedance 9–12 GHz (plots + CSV) • Surface current distributions at 10.5 GHz (images + data) • Far‑field patterns at θ = 0°, ±30°, ±45°, ±60° (plots + CSV)
- Slot synthesis tables: per‑column slot centers, lengths, and offsets (CSV).
- Assembly instructions and tuning plan (if any trim adjustments are foreseen).
- Qualification / acceptance test report with measured data and comparison to targets.

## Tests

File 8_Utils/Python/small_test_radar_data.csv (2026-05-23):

timestamp_ns | chirp_number | chirp_type | sample_index | I_value | Q_value | magnitude_squared
0 | 0 | LONG | 0 | -4 | 2 | 31
2 | 0 | LONG | 1 | 3 | -3 | 19
4 | 0 | LONG | 2 | 0 | 0 | 0
6 | 0 | LONG | 3 | -3 | 0 | 16
8 | 0 | LONG | 4 | -1 | -6 | 41
10 | 0 | LONG | 5 | 0 | 6 | 41
12 | 0 | LONG | 6 | -2 | 0 | 4
14 | 0 | LONG | 7 | -5 | 4 | 50
16 | 0 | LONG | 8 | 4 | -2 | 26
18 | 0 | LONG | 9 | 0 | -1 | 2
20 | 0 | LONG | 10 | 3 | 1 | 14
22 | 0 | LONG | 11 | 2 | -2 | 12
24 | 0 | LONG | 12 | -1 | 0 | 2
26 | 0 | LONG | 13 | 0 | -1 | 1
28 | 0 | LONG | 14 | -2 | 0 | 5
30 | 0 | LONG | 15 | 0 | 5 | 26
32 | 0 | LONG | 16 | -1 | 1 | 6
34 | 0 | LONG | 17 | -4 | 0 | 23
36 | 0 | LONG | 18 | 0 | 0 | 0
38 | 0 | LONG | 19 | -3 | -4 | 32
40 | 0 | LONG | 20 | -2 | 0 | 5
42 | 0 | LONG | 21 | 0 | -4 | 18
44 | 0 | LONG | 22 | -2 | 0 | 4
46 | 0 | LONG | 23 | 1 | -3 | 14
48 | 0 | LONG | 24 | 1 | -1 | 5
50 | 0 | LONG | 25 | 3 | 3 | 26
52 | 0 | LONG | 26 | 0 | 3 | 10
54 | 0 | LONG | 27 | -4 | -2 | 27
56 | 0 | LONG | 28 | 2 | 0 | 5
58 | 0 | LONG | 29 | 0 | -5 | 25
60 | 0 | LONG | 30 | -2 | 1 | 8
62 | 0 | LONG | 31 | 0 | 0 | 0
64 | 0 | LONG | 32 | -3 | -3 | 22
66 | 0 | LONG | 33 | 0 | 0 | 1
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

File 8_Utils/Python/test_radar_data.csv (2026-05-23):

timestamp_ns | chirp_number | chirp_type | sample_index | I_value | Q_value | magnitude_squared
0 | 0 | LONG | 0 | -15 | 16 | 499
2 | 0 | LONG | 1 | -12 | 17 | 484
4 | 0 | LONG | 2 | 0 | 9 | 94
6 | 0 | LONG | 3 | -12 | -8 | 228
8 | 0 | LONG | 4 | -2 | -4 | 26
10 | 0 | LONG | 5 | -10 | -2 | 124
12 | 0 | LONG | 6 | -4 | -13 | 195
14 | 0 | LONG | 7 | -3 | -5 | 44
16 | 0 | LONG | 8 | -12 | 14 | 356
18 | 0 | LONG | 9 | -3 | -5 | 40
20 | 0 | LONG | 10 | 0 | -8 | 76
22 | 0 | LONG | 11 | -11 | 26 | 846
24 | 0 | LONG | 12 | -7 | 1 | 53
26 | 0 | LONG | 13 | -10 | 10 | 216
28 | 0 | LONG | 14 | 3 | -3 | 27
30 | 0 | LONG | 15 | 21 | 8 | 517
32 | 0 | LONG | 16 | 17 | 3 | 317
34 | 0 | LONG | 17 | 15 | -5 | 279
36 | 0 | LONG | 18 | 29 | -1 | 886
38 | 0 | LONG | 19 | -16 | 0 | 268
40 | 0 | LONG | 20 | -6 | -9 | 129
42 | 0 | LONG | 21 | 0 | 0 | 0
44 | 0 | LONG | 22 | -5 | 1 | 30
46 | 0 | LONG | 23 | 12 | 11 | 300
48 | 0 | LONG | 24 | 10 | 1 | 116
50 | 0 | LONG | 25 | -5 | -14 | 255
52 | 0 | LONG | 26 | -2 | 3 | 18
54 | 0 | LONG | 27 | 0 | 11 | 135
56 | 0 | LONG | 28 | 9 | 19 | 466
58 | 0 | LONG | 29 | 15 | 6 | 280
60 | 0 | LONG | 30 | -13 | 4 | 187
62 | 0 | LONG | 31 | 2 | -8 | 76
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

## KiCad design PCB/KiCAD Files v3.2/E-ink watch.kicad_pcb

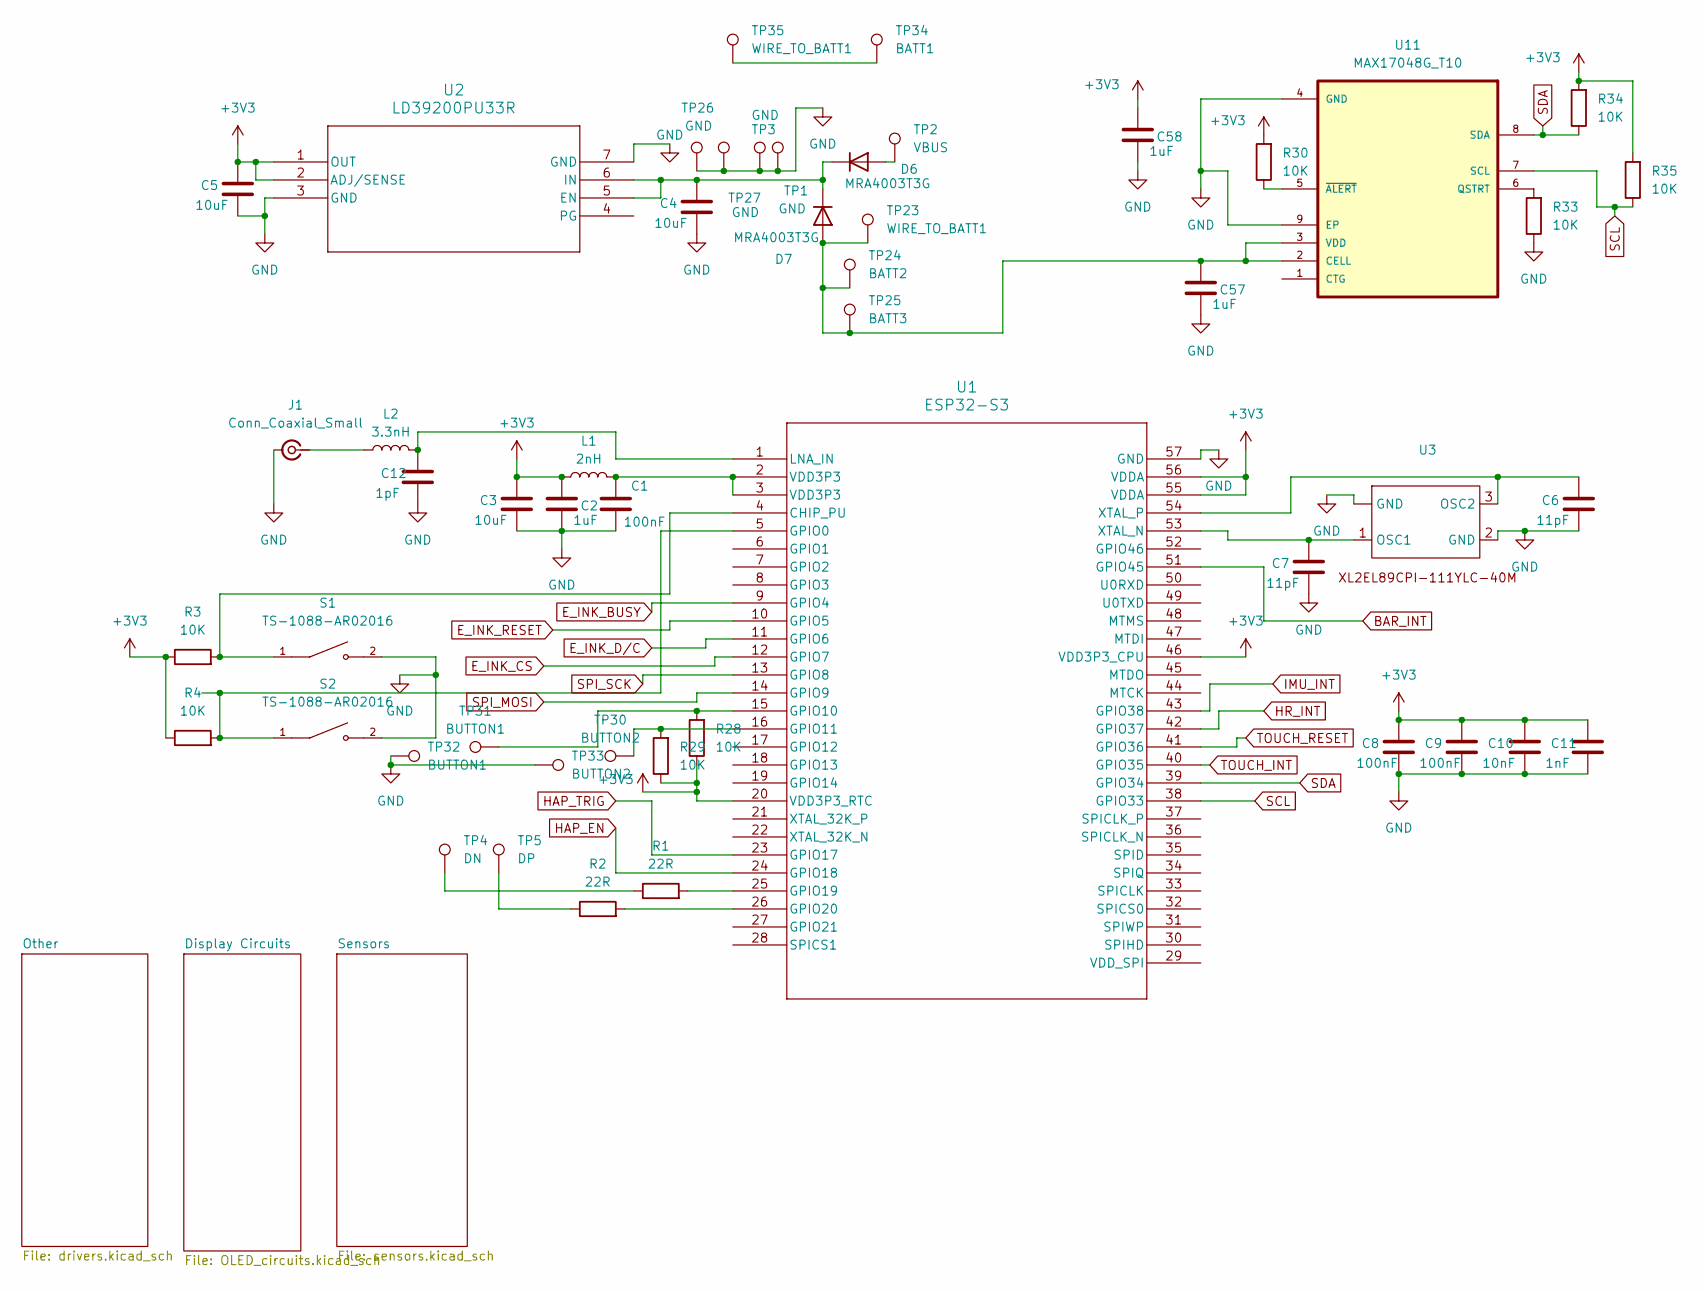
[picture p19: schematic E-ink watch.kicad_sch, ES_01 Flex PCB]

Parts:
C1, C8, C9: 100nF; C_0402_1005Metric_Pad0.74x0.62mm_HandSolder
C2, C57, C58: 1uF; C_0402_1005Metric_Pad0.74x0.62mm_HandSolder
C3, C4, C5: 10uF; C_0402_1005Metric_Pad0.74x0.62mm_HandSolder
C6, C7: 11pF; C_0402_1005Metric_Pad0.74x0.62mm_HandSolder
C10: 10nF; C_0402_1005Metric_Pad0.74x0.62mm_HandSolder
C11: 1nF; C_0402_1005Metric_Pad0.74x0.62mm_HandSolder
C12: 1pF; C_0402_1005Metric_Pad0.74x0.62mm_HandSolder
D6, D7: MRA4003T3G; D_SMA
J1: Conn_Coaxial_Small; U.FL_Hirose_U.FL-R-SMT-1_Vertical
L1: 2nH; L_0402_1005Metric_Pad0.77x0.64mm_HandSolder
L2: 3.3nH; L_0402_1005Metric_Pad0.77x0.64mm_HandSolder
R1, R2: 22R; R_0402_1005Metric_Pad0.72x0.64mm_HandSolder
R3, R4, R28, R29, R30, R33, R34, R35: 10K; R_0402_1005Metric_Pad0.72x0.64mm_HandSolder
S1, S2: TS-1088-AR02016; SW_TS-1088-AR02016; PARTREV N/A
TP1, TP3, TP26, TP27: GND; TestPoint_Pad_1.5x1.5mm
TP2: VBUS; TestPoint_Pad_1.5x1.5mm
TP4: DN; TestPoint_Pad_1.5x1.5mm
TP5: DP; TestPoint_Pad_1.5x1.5mm
TP23, TP35: WIRE_TO_BATT1; TestPoint_Pad_1.5x1.5mm
TP24: BATT2; TestPoint_Pad_1.5x1.5mm
TP25: BATT3; TestPoint_Pad_1.5x1.5mm
TP30, TP33: BUTTON2; TestPoint_Pad_1.5x1.5mm
TP31, TP32: BUTTON1; TestPoint_Pad_1.5x1.5mm
TP34: BATT1; TestPoint_Pad_1.5x1.5mm
U1: ESP32-S3; QFN56_7X7_EXP
U2: LD39200PU33R; SON_DFN6_3X3_STM
U3: Untitled
U11: MAX17048G_T10; SON50P200X200X80-9N

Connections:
+3V3: C2.1, C3.1, C5.1, C8.1, C9.1, C10.1, C11.1, C58.1, L1.1, R3.1, R4.1, R28.1, R29.1, R30.2, R34.2, R35.2, U1.20 (VDD3P3_RTC), U1.46 (VDD3P3_CPU), U1.55 (VDDA), U1.56 (VDDA), U2.1 (OUT), U2.2 (ADJ/SENSE); also elsewhere on the board
BAR_INT: U1.51 (GPIO45); also elsewhere on the board
E_INK_BUSY: U1.9 (GPIO4); also elsewhere on the board
E_INK_CS: U1.12 (GPIO7); also elsewhere on the board
E_INK_D/C: U1.11 (GPIO6); also elsewhere on the board
E_INK_RESET: U1.10 (GPIO5); also elsewhere on the board
GND: C1.2, C2.2, C3.2, C4.2, C5.2, C6.2, C7.2, C8.2, C9.2, C10.2, C11.2, C12.2, C57.2, C58.2, J1.2 (Ext), R33.1, S1.2, S2.2, TP1.1, TP3.1, TP26.1, TP27.1, TP32.1, TP33.1, U1.57 (GND), U2.3 (GND), U2.7 (GND), U3. (GND), U3.2 (GND), U11.4 (GND), U11.9 (EP); also elsewhere on the board
HAP_EN: U1.24 (GPIO18); also elsewhere on the board
HAP_TRIG: U1.23 (GPIO17); also elsewhere on the board
HR_INT: U1.42 (GPIO37); also elsewhere on the board
IMU_INT: U1.43 (GPIO38); also elsewhere on the board
unnamed: C1.1, L1.2, U1.2 (VDD3P3), U1.3 (VDD3P3)
unnamed: D6.2 (A), TP2.1
unnamed: C4.1, D6.1 (K), D7.1 (K), U2.5 (EN), U2.6 (IN)
unnamed: C57.1, D7.2 (A), TP23.1, TP24.1, TP25.1, U11.2 (CELL), U11.3 (VDD)
unnamed: J1.1 (In), L2.1
unnamed: R1.1, TP4.1
unnamed: R2.1, TP5.1
unnamed: TP34.1, TP35.1
unnamed: R3.2, S1.1, U1.4 (CHIP_PU)
unnamed: R4.2, S2.1, U1.5 (GPIO0)
unnamed: R28.2, TP31.1, U1.15 (GPIO10)
unnamed: R29.2, TP30.1, U1.16 (GPIO11)
unnamed: R1.2, U1.25 (GPIO19)
unnamed: R2.2, U1.26 (GPIO20)
unnamed: C12.1, L2.2, U1.1 (LNA_IN)
unnamed: C7.1, U1.53 (XTAL_N), U3.1 (OSC1)
unnamed: C6.1, U1.54 (XTAL_P), U3.3 (OSC2)
unnamed: R33.2, U11.6 (QSTRT)
unnamed: R30.1, U11.5 (~ALERT)
SCL: R35.1, U1.38 (GPIO33), U11.7 (SCL); also elsewhere on the board
SDA: R34.1, U1.39 (GPIO34), U11.8 (SDA); also elsewhere on the board
SPI_MOSI: U1.14 (GPIO9); also elsewhere on the board
SPI_SCK: U1.13 (GPIO8); also elsewhere on the board
TOUCH_INT: U1.40 (GPIO35); also elsewhere on the board
TOUCH_RESET: U1.41 (GPIO36); also elsewhere on the board

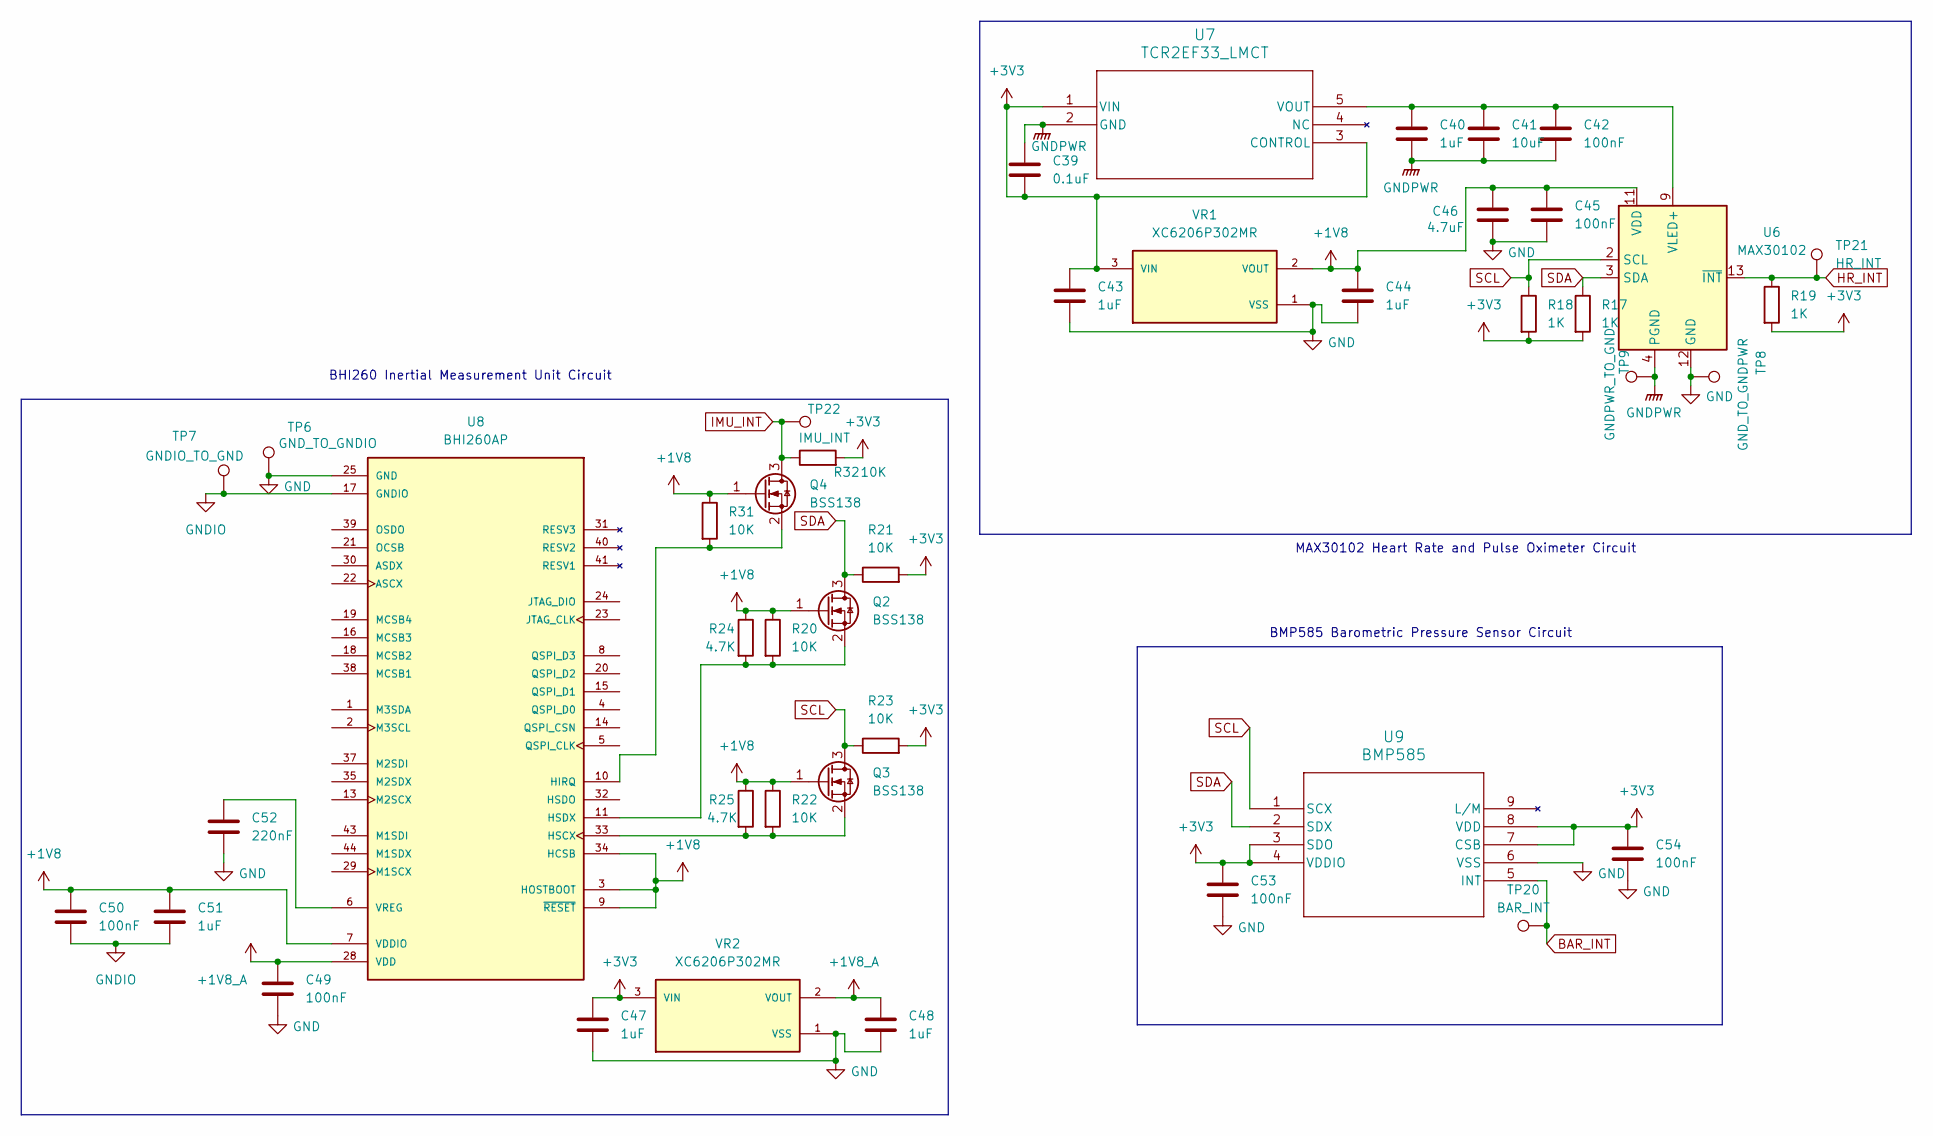
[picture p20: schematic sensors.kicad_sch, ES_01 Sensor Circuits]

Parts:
C39: 0.1uF; C_0402_1005Metric_Pad0.74x0.62mm_HandSolder
C40, C43, C44, C47, C48, C51: 1uF; C_0402_1005Metric_Pad0.74x0.62mm_HandSolder
C41: 10uF; C_0402_1005Metric_Pad0.74x0.62mm_HandSolder
C42, C45, C49, C50, C53, C54: 100nF; C_0402_1005Metric_Pad0.74x0.62mm_HandSolder
C46: 4.7uF; C_0402_1005Metric_Pad0.74x0.62mm_HandSolder
C52: 220nF; C_0402_1005Metric_Pad0.74x0.62mm_HandSolder
Q2, Q3, Q4: BSS138; SOT-23
R17, R18, R19: 1K; R_0402_1005Metric_Pad0.72x0.64mm_HandSolder
R20, R21, R22, R23, R31, R32: 10K; R_0402_1005Metric_Pad0.72x0.64mm_HandSolder
R24, R25: 4.7K; R_0402_1005Metric_Pad0.72x0.64mm_HandSolder
TP6: GND_TO_GNDIO; TestPoint_Pad_1.5x1.5mm
TP7: GNDIO_TO_GND; TestPoint_Pad_1.5x1.5mm
TP8: GND_TO_GNDPWR; TestPoint_Pad_1.5x1.5mm
TP9: GNDPWR_TO_GND; TestPoint_Pad_1.5x1.5mm
TP20: BAR_INT; TestPoint_Pad_D1.0mm
TP21: HR_INT; TestPoint_Pad_D1.0mm
TP22: IMU_INT; TestPoint_Pad_D1.0mm
U6: MAX30102; Maxim_OLGA-14_3.3x5.6mm_P0.8mm
U7: TCR2EF33_LMCT; SOT-25 SMV_TOS
U8: BHI260AP; XDCR_BHI260AP; PARTREV 1.1
U9: BMP585; LGA9_BMP585_BOS
VR1, VR2: XC6206P302MR; SOT95P280X130-3N; PARTREV N/A

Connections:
+1V8: C44.1, C45.1, C46.1, C50.1, C51.1, Q2.1 (G), Q3.1 (G), Q4.1 (G), R20.1, R22.1, R24.1, R25.1, R31.1, U6.11 (VDD), U8.3 (HOSTBOOT), U8.7 (VDDIO), U8.9 (~RESET), U8.12 (VDDIO), U8.34 (HCSB), U8.42 (VDDIO), VR1.2 (VOUT)
+1V8_A: C48.1, C49.1, U8.28 (VDD), VR2.2 (VOUT)
+3V3: C39.2, C43.1, C47.1, C53.1, C54.1, R17.2, R18.2, R19.2, R21.2, R23.2, R32.2, U7.1 (VIN), U7.3 (CONTROL), U9.3 (SDO), U9.4 (VDDIO), U9.7 (CSB), U9.8 (VDD), VR1.3 (VIN), VR2.3 (VIN); also elsewhere on the board
BAR_INT: TP20.1, U9.5 (INT); also elsewhere on the board
GND: C43.2, C44.2, C45.2, C46.2, C47.2, C48.2, C49.2, C52.2, C53.2, C54.2, TP6.1, TP8.1, U6.12 (GND), U8.25 (GND), U8.26 (GND), U8.27 (GND), U9.6 (VSS), VR1.1 (VSS), VR2.1 (VSS); also elsewhere on the board
GNDIO: C50.2, C51.2, TP7.1, U8.17 (GNDIO), U8.36 (GNDIO)
GNDPWR: C39.1, C40.2, C41.2, C42.2, TP9.1, U6.4 (PGND), U7.2 (GND)
HR_INT: R19.1, TP21.1, U6.13 (~INT); also elsewhere on the board
IMU_INT: Q4.3 (D), R32.1, TP22.1; also elsewhere on the board
unnamed: Q2.2 (S), R20.2, R24.2, U8.11 (HSDX)
unnamed: Q3.2 (S), R22.2, R25.2, U8.33 (HSCX)
unnamed: Q4.2 (S), R31.2, U8.10 (HIRQ)
unnamed: C40.1, C41.1, C42.1, U6.9 (VLED+), U6.10 (VLED+), U7.5 (VOUT)
unnamed: C52.1, U8.6 (VREG)
SCL: Q3.3 (D), R18.1, R23.1, U6.2 (SCL), U9.1 (SCX); also elsewhere on the board
SDA: Q2.3 (D), R17.1, R21.1, U6.3 (SDA), U9.2 (SDX); also elsewhere on the board

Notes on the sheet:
MAX30102 Heart Rate and Pulse Oximeter Circuit
BHI260 Inertial Measurement Unit Circuit
BMP585 Barometric Pressure Sensor Circuit

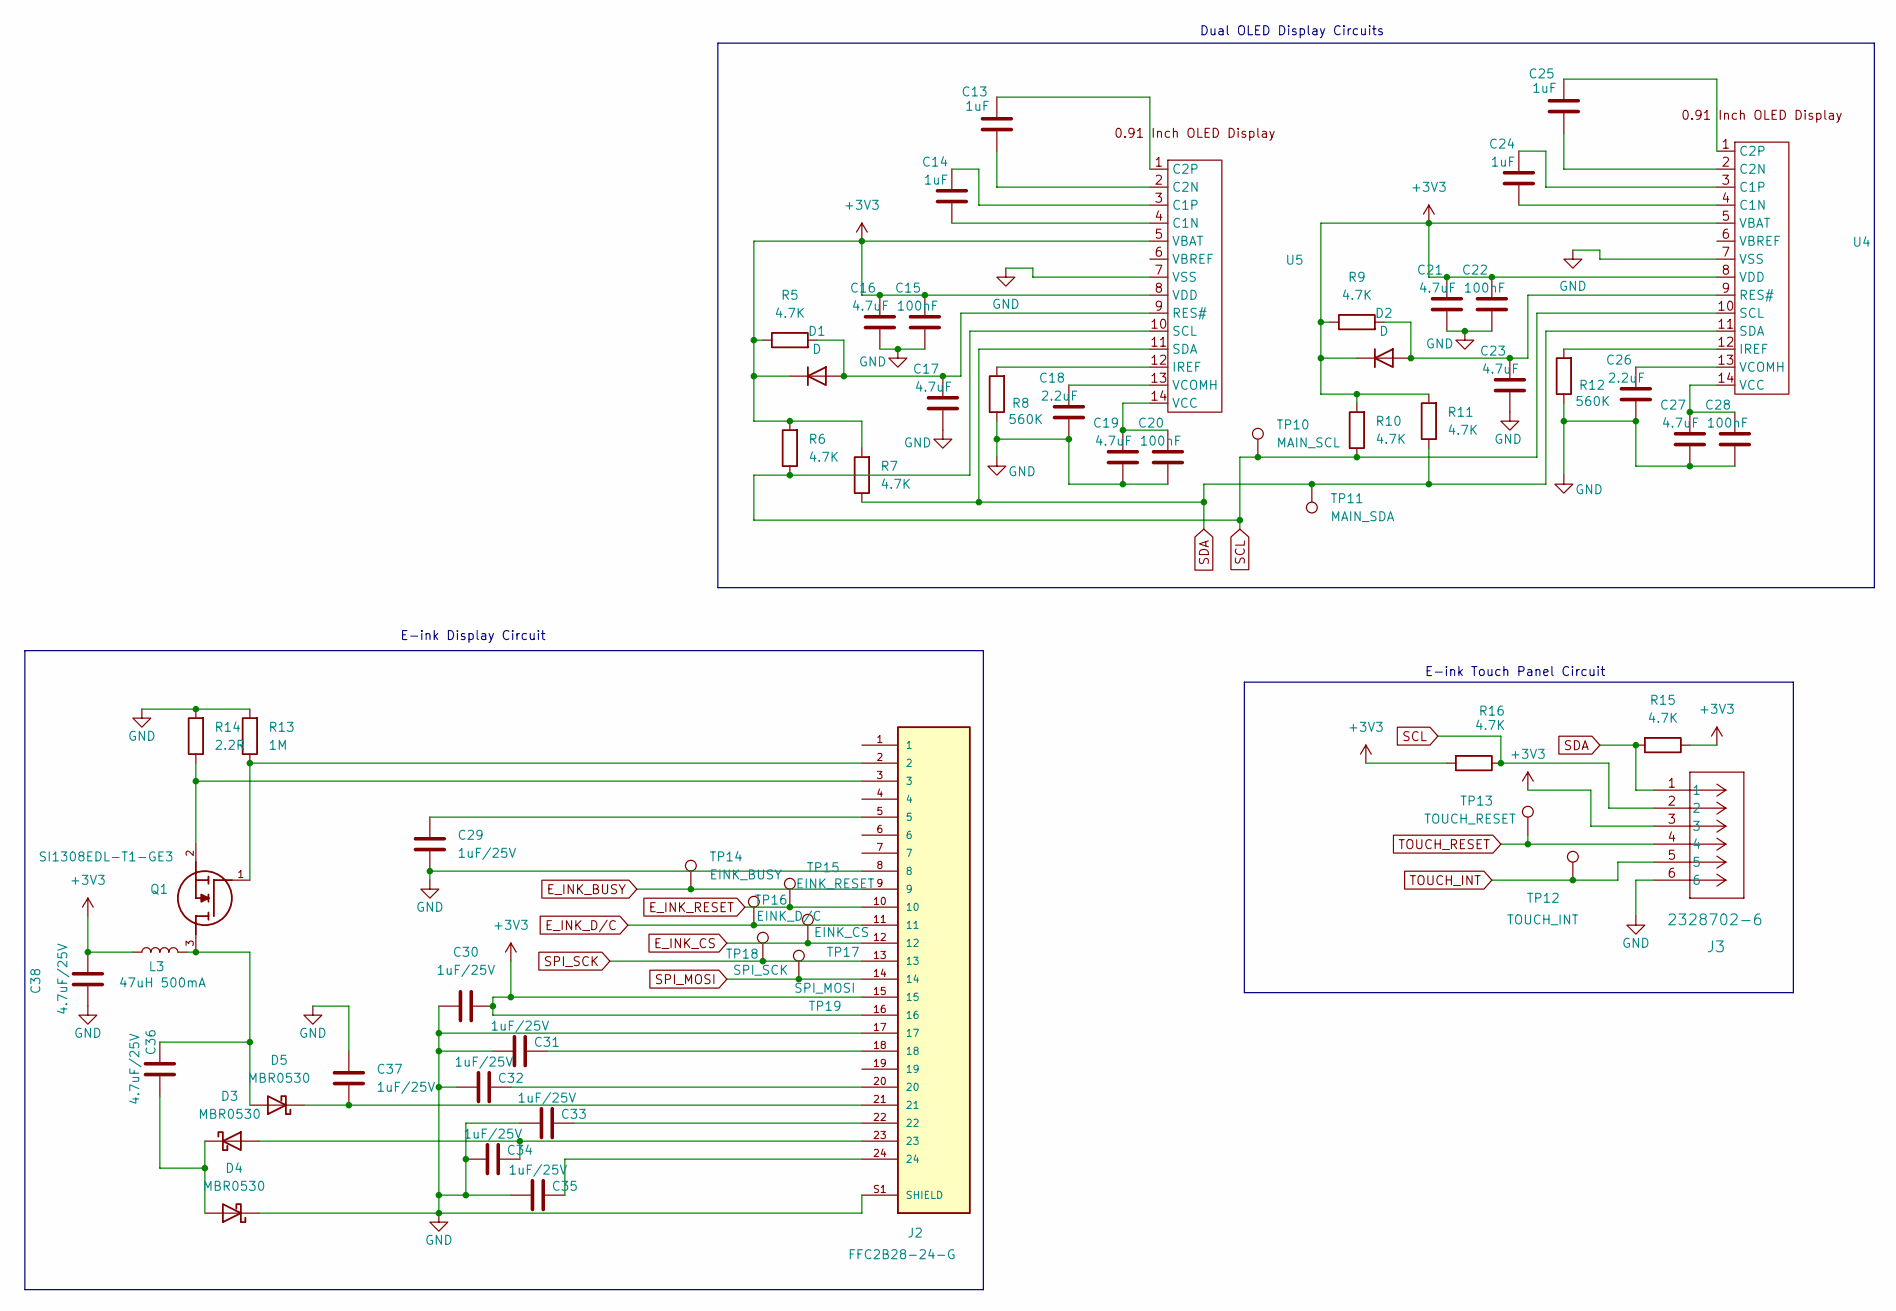
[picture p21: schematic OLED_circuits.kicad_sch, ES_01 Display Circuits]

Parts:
C13, C14, C24, C25: 1uF; C_0402_1005Metric_Pad0.74x0.62mm_HandSolder
C15, C20, C22, C28: 100nF; C_0402_1005Metric_Pad0.74x0.62mm_HandSolder
C16, C17, C19, C21, C23, C27: 4.7uF; C_0402_1005Metric_Pad0.74x0.62mm_HandSolder
C18, C26: 2.2uF; C_0402_1005Metric_Pad0.74x0.62mm_HandSolder
C29, C30, C31, C32, C33, C34, C35, C37: 1uF/25V; C_0402_1005Metric_Pad0.74x0.62mm_HandSolder
C36, C38: 4.7uF/25V; C_0402_1005Metric_Pad0.74x0.62mm_HandSolder
D1, D2: D; D_DO-35_SOD27_P7.62mm_Horizontal
D3, D4, D5: MBR0530; D_0805_2012Metric_Pad1.15x1.40mm_HandSolder
J2: FFC2B28-24-G; GCT_FFC2B28-24-G; PARTREV A
J3: 2328702-6; CONN6_2328702-6_TEC
L3: 47uH 500mA; Untitled
Q1: SI1308EDL-T1-GE3; SOT65P210X110-3N; Mouser_Part_Number 78-SI1308EDL-T1-GE3
R5, R6, R7, R9, R10, R11, R15, R16: 4.7K; R_0402_1005Metric_Pad0.72x0.64mm_HandSolder
R8, R12: 560K; R_0402_1005Metric_Pad0.72x0.64mm_HandSolder
R13: 1M; R_0402_1005Metric_Pad0.72x0.64mm_HandSolder
R14: 2.2R; R_0402_1005Metric_Pad0.72x0.64mm_HandSolder
TP10: MAIN_SCL; TestPoint_Pad_D1.0mm
TP11: MAIN_SDA; TestPoint_Pad_D1.0mm
TP12: TOUCH_INT; TestPoint_Pad_D1.0mm
TP13: TOUCH_RESET; TestPoint_Pad_D1.0mm
TP14: EINK_BUSY; TestPoint_Pad_D1.0mm
TP15: EINK_RESET; TestPoint_Pad_D1.0mm
TP16: EINK_D/C; TestPoint_Pad_D1.0mm
TP17: EINK_CS; TestPoint_Pad_D1.0mm
TP18: SPI_SCK; TestPoint_Pad_D1.0mm
TP19: SPI_MOSI; TestPoint_Pad_D1.0mm
U4, U5: Untitled

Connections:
+3V3: C15.1, C16.1, C21.1, C22.1, C30.2, C38.2, D1.1 (K), D2.1 (K), J2.15, J2.16, J3.3, L3.1, R5.1, R6.2, R7.2, R9.1, R10.2, R11.2, R15.1, R16.2, U4.5 (VBAT), U4.8 (VDD), U5.5 (VBAT), U5.8 (VDD); also elsewhere on the board
E_INK_BUSY: J2.9, TP14.1; also elsewhere on the board
E_INK_CS: J2.12, TP17.1; also elsewhere on the board
E_INK_D/C: J2.11, TP16.1; also elsewhere on the board
E_INK_RESET: J2.10, TP15.1; also elsewhere on the board
GND: C15.2, C16.2, C17.2, C18.2, C19.2, C20.2, C21.2, C22.2, C23.2, C26.2, C27.2, C28.2, C29.2, C30.1, C31.1, C32.1, C33.1, C34.1, C35.1, C37.1, C38.1, D4.1 (K), J2.8, J2.17, J2.S1 (SHIELD), J2.S2 (SHIELD), J3.6, R8.1, R12.1, R13.2, R14.2, U4.7 (VSS), U5.7 (VSS); also elsewhere on the board
unnamed: C29.1, J2.5
unnamed: C31.2, J2.18
unnamed: C32.2, J2.20
unnamed: C33.2, J2.22
unnamed: C35.2, J2.24
unnamed: C17.1, D1.2 (A), R5.2, U5.9 (RES#)
unnamed: C23.1, D2.2 (A), R9.2, U4.9 (RES#)
unnamed: C34.2, D3.2 (A), J2.23
unnamed: C36.1, D3.1 (K), D4.2 (A)
unnamed: C36.2, D5.2 (A), L3.2, Q1.3
unnamed: C37.2, D5.1 (K), J2.21
unnamed: J2.2, Q1.1, R13.1
unnamed: J2.3, Q1.2, R14.1
unnamed: C24.2, U4.4 (C1N)
unnamed: C24.1, U4.3 (C1P)
unnamed: C25.2, U4.2 (C2N)
unnamed: C25.1, U4.1 (C2P)
unnamed: R12.2, U4.12 (IREF)
unnamed: C27.1, C28.1, U4.14 (VCC)
unnamed: C26.1, U4.13 (VCOMH)
unnamed: C14.2, U5.4 (C1N)
unnamed: C14.1, U5.3 (C1P)
unnamed: C13.2, U5.2 (C2N)
unnamed: C13.1, U5.1 (C2P)
unnamed: R8.2, U5.12 (IREF)
unnamed: C19.1, C20.1, U5.14 (VCC)
unnamed: C18.1, U5.13 (VCOMH)
SCL: J3.2, R6.1, R10.1, R16.1, TP10.1, U4.10 (SCL), U5.10 (SCL); also elsewhere on the board
SDA: J3.1, R7.1, R11.1, R15.2, TP11.1, U4.11 (SDA), U5.11 (SDA); also elsewhere on the board
SPI_MOSI: J2.14, TP19.1; also elsewhere on the board
SPI_SCK: J2.13, TP18.1; also elsewhere on the board
TOUCH_INT: J3.5, TP12.1; also elsewhere on the board
TOUCH_RESET: J3.4, TP13.1; also elsewhere on the board

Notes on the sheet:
E-ink Display Circuit
Dual OLED Display Circuits
E-ink Touch Panel Circuit

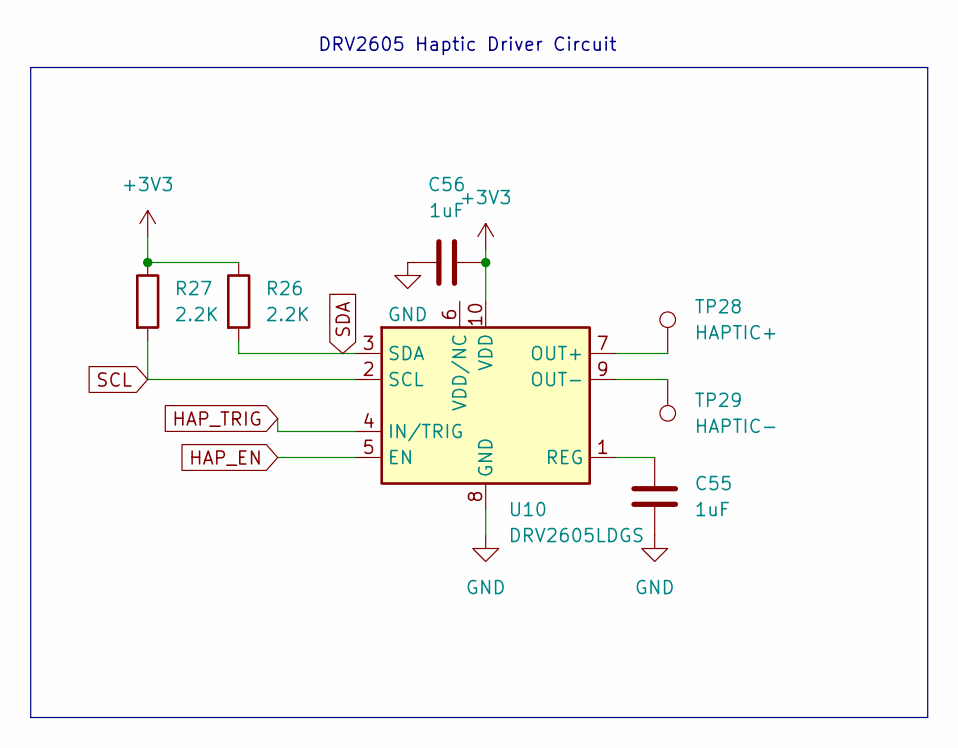
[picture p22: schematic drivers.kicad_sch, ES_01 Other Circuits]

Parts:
C55, C56: 1uF; C_0402_1005Metric_Pad0.74x0.62mm_HandSolder
R26, R27: 2.2K; R_0402_1005Metric_Pad0.72x0.64mm_HandSolder
TP28: HAPTIC+; TestPoint_Pad_1.5x1.5mm
TP29: HAPTIC-; TestPoint_Pad_1.5x1.5mm
U10: DRV2605LDGS; VSSOP-10_3x3mm_P0.5mm

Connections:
+3V3: C56.2, R26.1, R27.1, U10.10 (VDD); also elsewhere on the board
GND: C55.2, C56.1, U10.8 (GND); also elsewhere on the board
HAP_EN: U10.5 (EN); also elsewhere on the board
HAP_TRIG: U10.4 (IN/TRIG); also elsewhere on the board
unnamed: TP28.1, U10.7 (OUT+)
unnamed: TP29.1, U10.9 (OUT-)
unnamed: C55.1, U10.1 (REG)
SCL: R27.2, U10.2 (SCL); also elsewhere on the board
SDA: R26.2, U10.3 (SDA); also elsewhere on the board

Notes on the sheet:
DRV2605 Haptic Driver Circuit

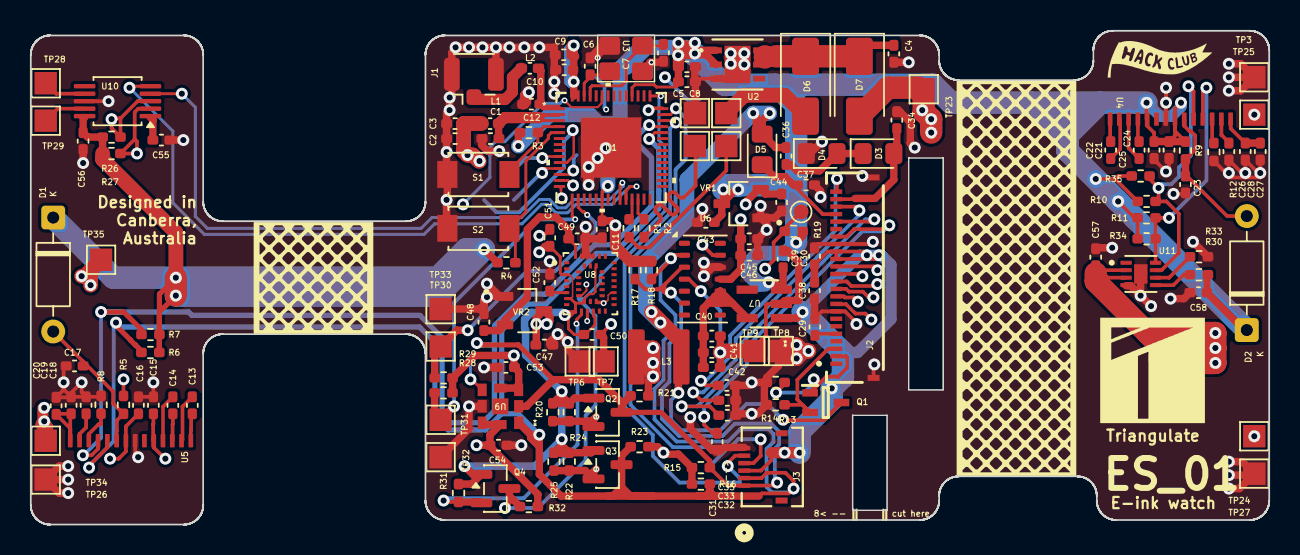
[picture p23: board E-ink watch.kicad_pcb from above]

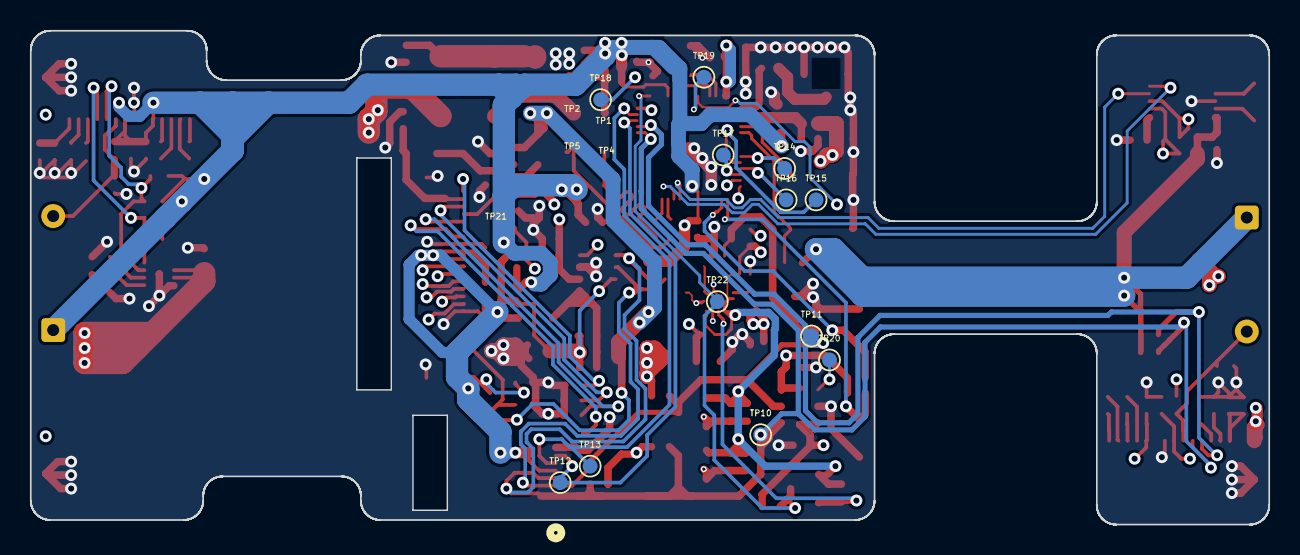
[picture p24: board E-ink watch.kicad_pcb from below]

Board: 4 copper layers, 82.8 x 33.0 mm, 160 parts (12 on the bottom side), 75 nets.

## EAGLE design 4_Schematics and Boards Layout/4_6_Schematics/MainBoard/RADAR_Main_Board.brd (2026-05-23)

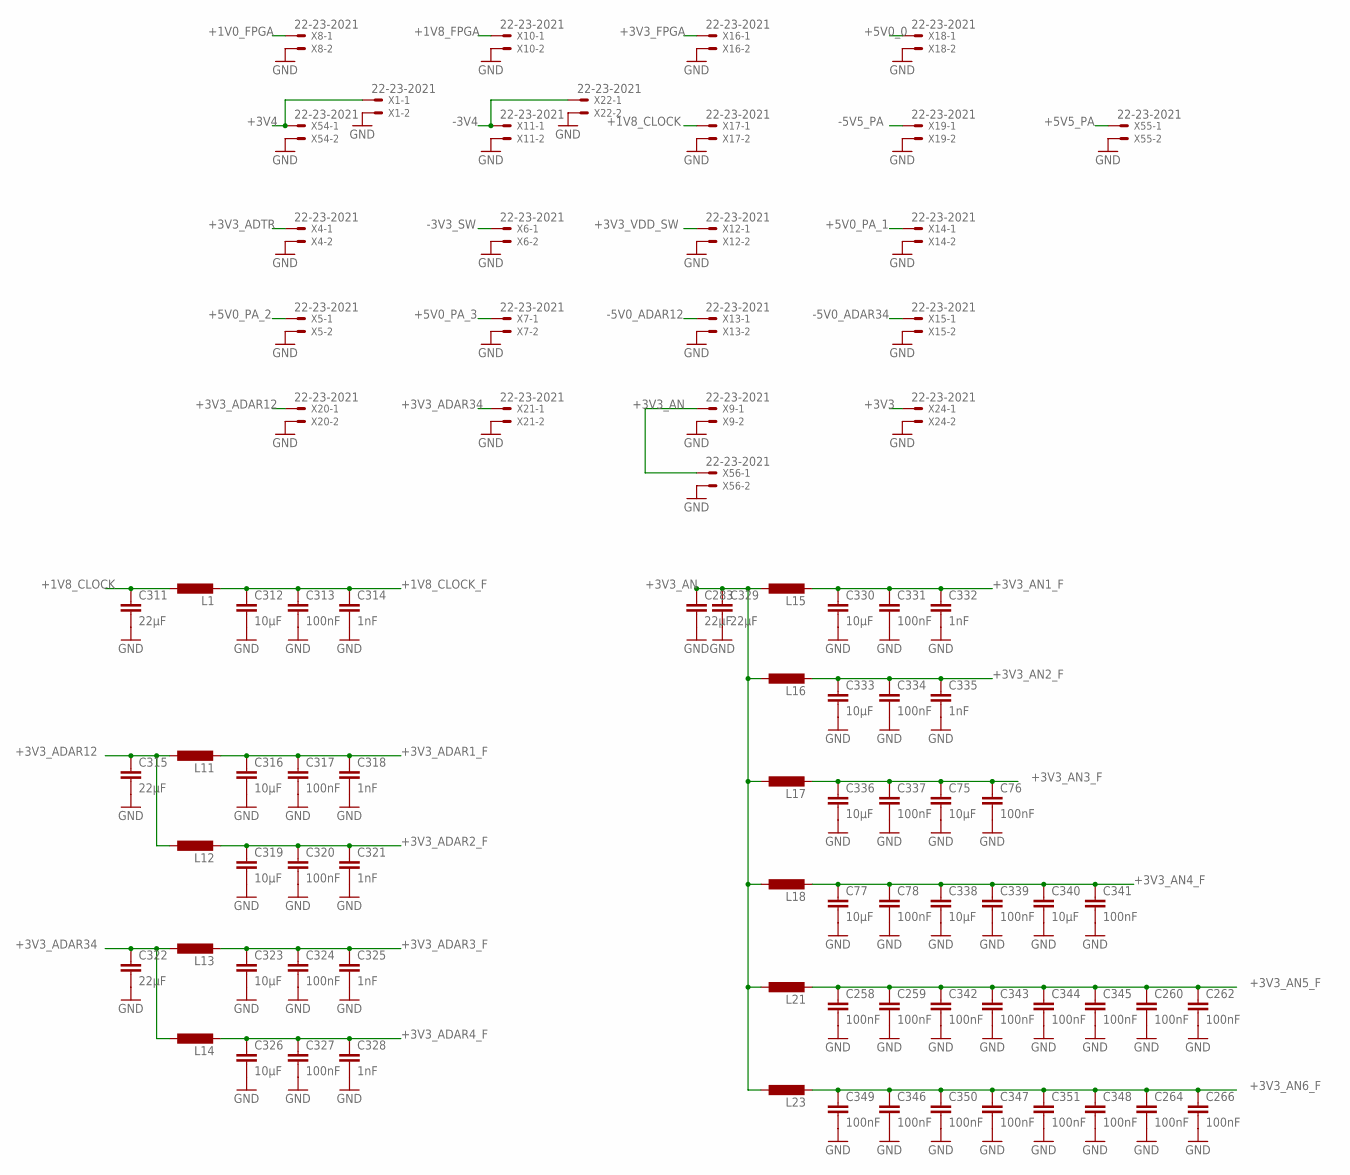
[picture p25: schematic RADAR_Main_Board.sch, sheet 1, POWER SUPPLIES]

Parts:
C75, C77, C312, C316, C319, C323, C326, C330, C333, C336, C338, C340: 10µF; C0805
C76, C78, C258, C259, C260, C262, C264, C266, C313, C317, C320, C324, C327, C331, C334, C337, C339, C341, C342, C343, C344, C345, C346, C347, C348, C349, C350, C351: 100nF; C0402
C283, C311, C315, C322, C329: 22µF; C1206
C314, C318, C321, C325, C328, C332, C335: 1nF; C0402
L1, L11, L12, L13, L14, L15, L16, L17, L18, L21, L23: L-EUL5650M; L5650M
X1, X4, X5, X6, X7, X8, X9, X10, X11, X12, X13, X14, X15, X16, X17, X18, X19, X20, X21, X22, X24, X54, X55, X56: 22-23-2021

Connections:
+1V0_FPGA: X8.1; also elsewhere on the board
+1V8_CLOCK: C311.1, L1.1, X17.1
+1V8_CLOCK_F: C312.1, C313.1, C314.1, L1.2; also elsewhere on the board
+1V8_FPGA: X10.1; also elsewhere on the board
+3V3: X24.1; also elsewhere on the board
+3V3_ADAR1_F: C316.1, C317.1, C318.1, L11.2; also elsewhere on the board
+3V3_ADAR2_F: C319.1, C320.1, C321.1, L12.2; also elsewhere on the board
+3V3_ADAR3_F: C323.1, C324.1, C325.1, L13.2; also elsewhere on the board
+3V3_ADAR4_F: C326.1, C327.1, C328.1, L14.2; also elsewhere on the board
+3V3_ADAR12: C315.1, L11.1, L12.1, X20.1
+3V3_ADAR34: C322.1, L13.1, L14.1, X21.1
+3V3_ADTR: X4.1; also elsewhere on the board
+3V3_AN: C283.1, C329.1, L15.1, L16.1, L17.1, L18.1, L21.1, L23.1, X9.1, X56.1; also elsewhere on the board
+3V3_AN1_F: C330.1, C331.1, C332.1, L15.2; also elsewhere on the board
+3V3_AN2_F: C333.1, C334.1, C335.1, L16.2; also elsewhere on the board
+3V3_AN3_F: C75.1, C76.1, C336.1, C337.1, L17.2; also elsewhere on the board
+3V3_AN4_F: C77.1, C78.1, C338.1, C339.1, C340.1, C341.1, L18.2; also elsewhere on the board
+3V3_AN5_F: C258.1, C259.1, C260.1, C262.1, C342.1, C343.1, C344.1, C345.1, L21.2; also elsewhere on the board
+3V3_AN6_F: C264.1, C266.1, C346.1, C347.1, C348.1, C349.1, C350.1, C351.1, L23.2; also elsewhere on the board
+3V3_FPGA: X16.1; also elsewhere on the board
+3V3_VDD_SW: X12.1; also elsewhere on the board
+3V4: X1.1, X54.1; also elsewhere on the board
+5V0_0: X18.1; also elsewhere on the board
+5V0_PA_1: X14.1; also elsewhere on the board
+5V0_PA_2: X5.1; also elsewhere on the board
+5V0_PA_3: X7.1; also elsewhere on the board
+5V5_PA: X55.1; also elsewhere on the board
-3V3_SW: X6.1; also elsewhere on the board
-3V4: X11.1, X22.1; also elsewhere on the board
-5V0_ADAR12: X13.1; also elsewhere on the board
-5V0_ADAR34: X15.1; also elsewhere on the board
-5V5_PA: X19.1; also elsewhere on the board
GND: C75.2, C76.2, C77.2, C78.2, C258.2, C259.2, C260.2, C262.2, C264.2, C266.2, C283.2, C311.2, C312.2, C313.2, C314.2, C315.2, C316.2, C317.2, C318.2, C319.2, C320.2, C321.2, C322.2, C323.2, C324.2, C325.2, C326.2, C327.2, C328.2, C329.2, C330.2, C331.2, C332.2, C333.2, C334.2, C335.2, C336.2, C337.2, C338.2, C339.2, C340.2, C341.2, C342.2, C343.2, C344.2, C345.2, C346.2, C347.2, C348.2, C349.2, C350.2, C351.2, X1.2, X4.2, X5.2, X6.2, X7.2, X8.2, X9.2, X10.2, X11.2, X12.2, X13.2, X14.2, X15.2, X16.2, X17.2, X18.2, X19.2, X20.2, X21.2, X22.2, X24.2, X54.2, X55.2, X56.2; also elsewhere on the board

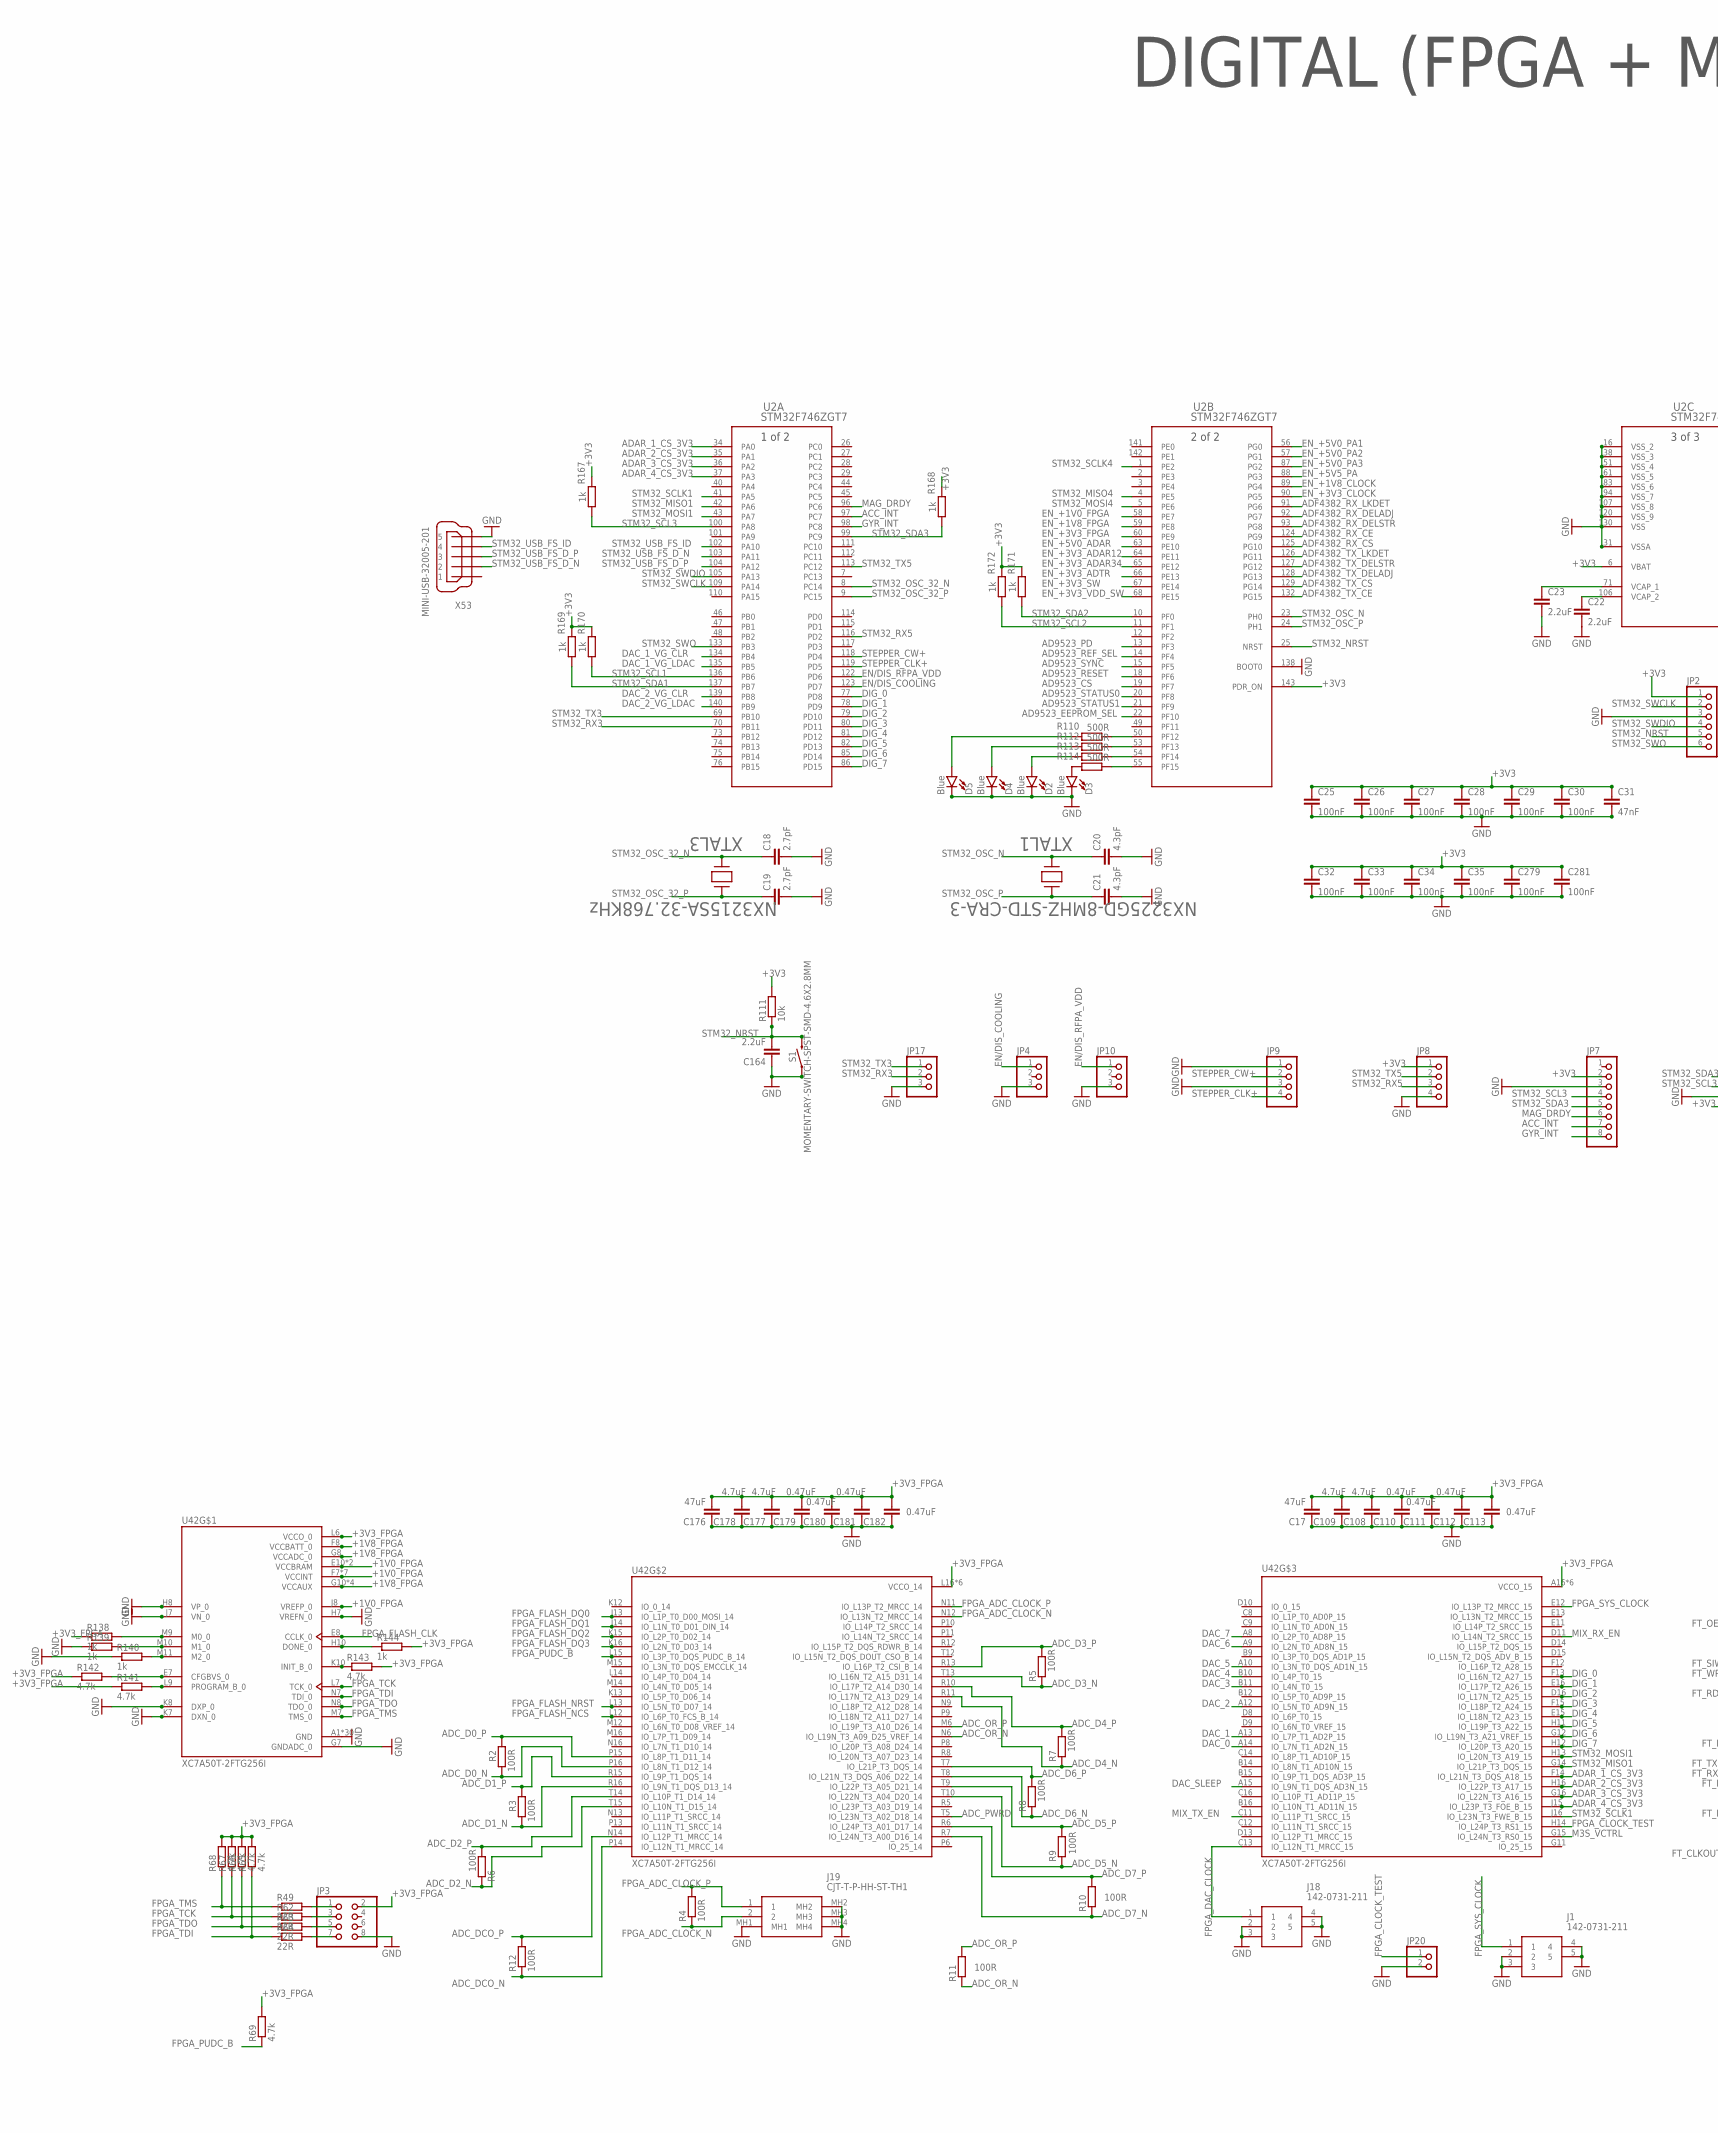
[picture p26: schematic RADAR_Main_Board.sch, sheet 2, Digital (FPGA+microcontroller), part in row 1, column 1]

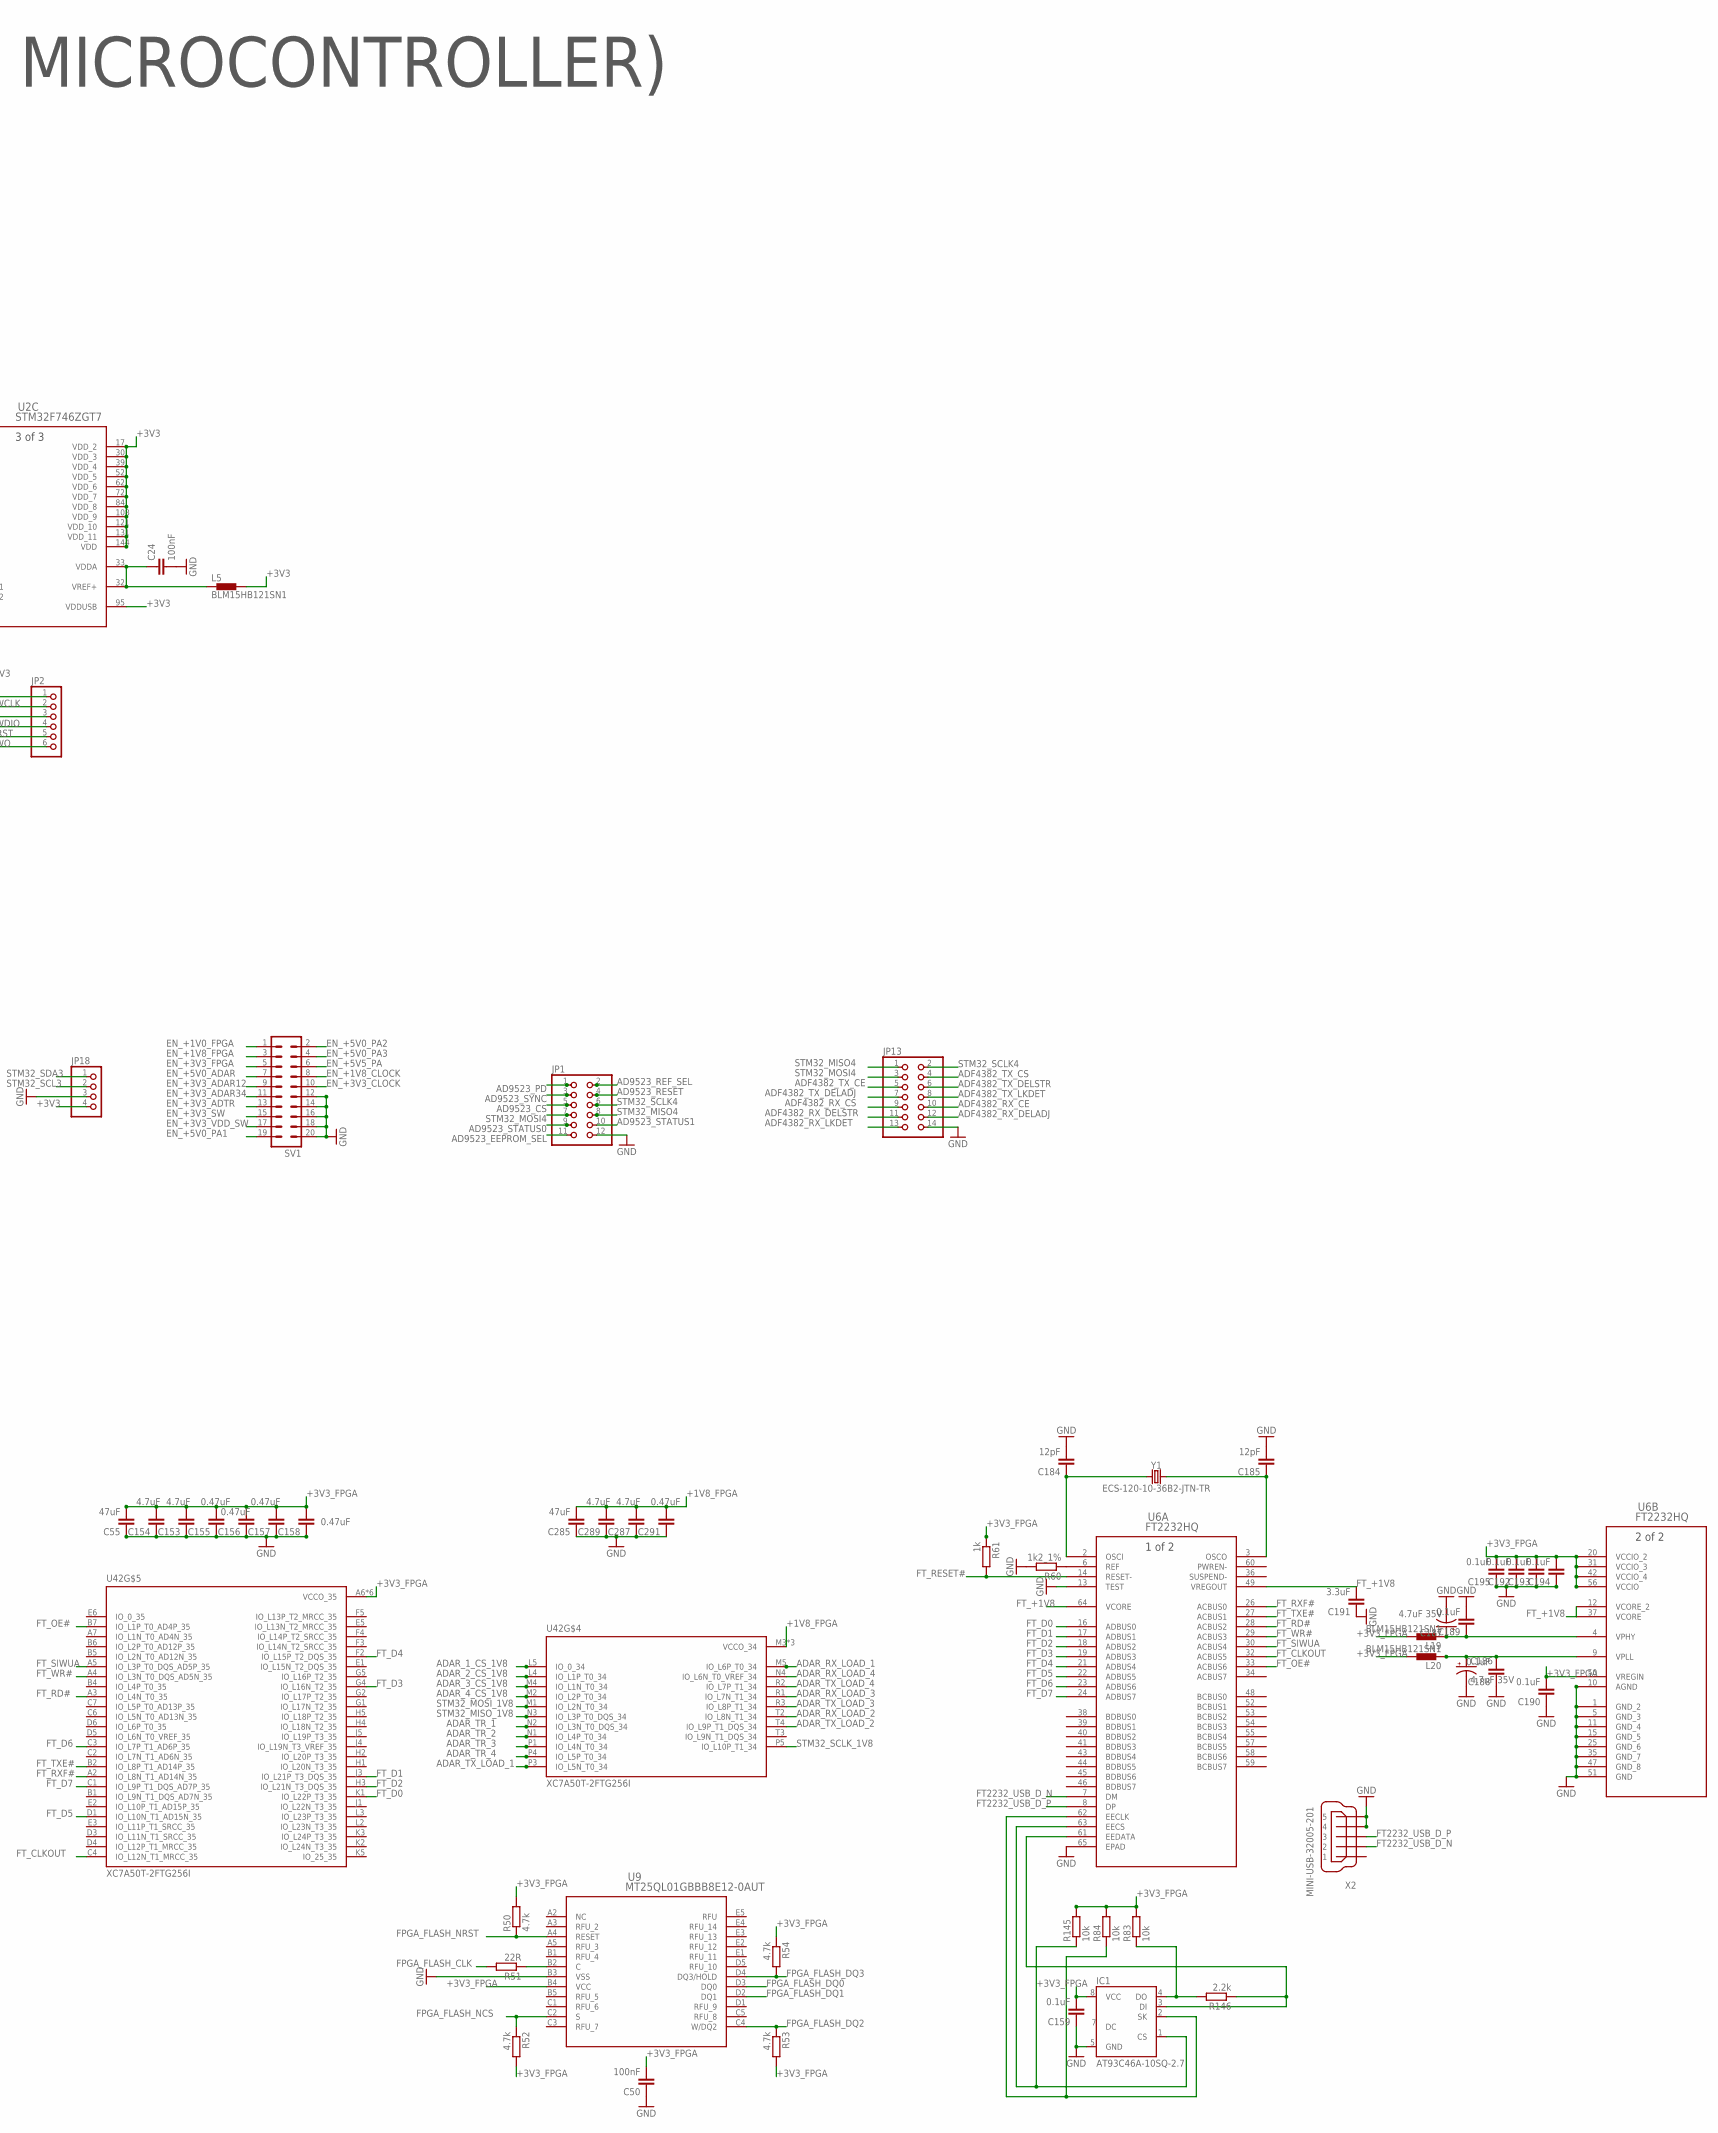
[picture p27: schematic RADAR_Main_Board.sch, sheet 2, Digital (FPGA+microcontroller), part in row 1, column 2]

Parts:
C17, C55, C176, C285: 47uF; C0201
C18, C19: 2.7pF; C0201
C20, C21: 4.3pF; C0201
C22, C23, C164: 2.2uF; C0201
C24, C25, C26, C27, C28, C29, C30, C32, C33, C34, C35, C50, C279, C281: 100nF; C0201
C31: 47nF; C0201
C108, C109, C153, C154, C177, C178, C287, C289: 4.7uF; C0201
C110, C111, C112, C113, C155, C156, C157, C158, C179, C180, C181, C182, C291: 0.47uF; C0201
C159, C188, C189, C190, C192, C193, C194, C195: 0.1uF; C0201
C184, C185: 12pF; C0201
C186, C187: 4.7uF 35V; EIA3528
C191: 3.3uF; C0201
D2, D3, D4, D5: Blue; LED-0603
IC1: AT93C46A-10SQ-2.7; SOIC8
J1, J18: 142-0731-211; 1420731211
J19: CJT-T-P-HH-ST-TH1; CJTTPHHSTTH1
JP1: PINHD-2X6; 2X06
JP2: PINHD-1X6; 1X06
JP3: PINHD-2X4; 2X04
JP4, JP10, JP17: PINHD-1X3; 1X03
JP7: PINHD-1X8; 1X08
JP8, JP9, JP18: PINHD-1X4; 1X04
JP13: PINHD-2X7; 2X07
JP20: PINHD-1X2; 1X02
L5, L19, L20: BLM15HB121SN1; 0402
R2, R3, R4, R5, R6, R7, R8, R9, R10, R11, R12: 100R; R0201
R49, R51, R62, R63, R64: 22R; R0201
R50, R52, R53, R54, R65, R66, R67, R68, R69, R141, R142, R143: 4.7k; R0201
R60: 1k2_1%; R0201
R61, R138, R139, R140, R144, R167, R168, R169, R170, R171, R172: 1k; R0201
R83, R84, R111, R145: 10k; R0201
R110, R112, R113, R114: 500R; R0201
R146: 2.2k; R0201
S1: MOMENTARY-SWITCH-SPST-SMD-4.6X2.8MM; TACTILE_SWITCH_SMD_4.6X2.8MM
SV1: MA10-2
U2: STM32F746ZGT7; LQFP-144_STM
U6: FT2232HQ; 64QFN_FT2232HQ_FTD
U9: MT25QL01GBBB8E12-0AUT; BGA24_MT25QL_MRN
U42: XC7A50T-2FTG256I; BGA256C100P16X16_1700X1700X155
X2, X53: MINI-USB-32005-201; 32005-201
XTAL1: NX3225GD-8MHZ-STD-CRA-3; XTAL_NX3225GD-8MHZ-STD-CRA-3_N
XTAL3: NX3215SA-32.768KHz; XTAL_NX3225GD-8MHZ-STD-CRA-3_N
Y1: ECS-120-10-36B2-JTN-TR; CRYSTAL-SMD-2X2.5MM

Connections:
+1V0_FPGA: U42.E10 (VCCBRAM), U42.F7 (VCCINT), U42.F9 (VCCINT), U42.F11 (VCCBRAM), U42.G6 (VCCINT), U42.H9 (VCCINT), U42.J6 (VCCINT), U42.J8 (VREFP_0), U42.K9 (VCCINT), U42.L8 (VCCINT); also elsewhere on the board
+1V8_FPGA: C285.2, C287.2, C289.2, C291.2, U42.F8 (VCCBATT_0), U42.G8 (VCCADC_0), U42.G10 (VCCAUX), U42.J10 (VCCAUX), U42.K11 (VCCAUX), U42.L10 (VCCAUX), U42.M3 (VCCO_34), U42.R4 (VCCO_34), U42.T1 (VCCO_34); also elsewhere on the board
+3V3: C25.1, C26.1, C27.1, C28.1, C29.1, C30.1, C31.1, C32.1, C33.1, C34.1, C35.1, C279.1, C281.1, JP2.1, JP7.2, JP8.1, JP18.4, L5.2, R111.2, R167.1, R168.1, R169.1, R170.1, R171.1, R172.1, U2.6 (VBAT), U2.17 (VDD_2), U2.30 (VDD_3), U2.39 (VDD_4), U2.52 (VDD_5), U2.62 (VDD_6), U2.72 (VDD_7), U2.84 (VDD_8), U2.95 (VDDUSB), U2.108 (VDD_9), U2.121 (VDD_10), U2.131 (VDD_11), U2.143 (PDR_ON), U2.144 (VDD); also elsewhere on the board
+3V3_FPGA: C17.2, C50.2, C55.2, C108.2, C109.2, C110.2, C111.2, C112.2, C113.2, C153.2, C154.2, C155.2, C156.2, C157.2, C158.2, C159.2, C176.2, C177.2, C178.2, C179.2, C180.2, C181.2, C182.2, C190.2, C192.2, C193.2, C194.2, C195.2, IC1.8 (VCC), JP3.2, L19.2, L20.2, R50.2, R52.2, R53.2, R54.1, R61.1, R65.2, R66.2, R67.2, R68.2, R69.2, R83.2, R84.2, R138.1, R141.1, R142.1, R143.2, R144.2, R145.2, U6.20 (VCCIO_2), U6.31 (VCCIO_3), U6.42 (VCCIO_4), U6.50 (VREGIN), U6.56 (VCCIO), U9.B4 (VCC), U42.A6 (VCCO_35), U42.A16 (VCCO_15), U42.B3 (VCCO_35), U42.B13 (VCCO_15), U42.C10 (VCCO_15), U42.D7 (VCCO_35), U42.E4 (VCCO_35), U42.E14 (VCCO_15), U42.F1 (VCCO_35), U42.H15 (VCCO_15), U42.J2 (VCCO_35), U42.J12 (VCCO_15), U42.L6 (VCCO_0), U42.L16 (VCCO_14), U42.M13 (VCCO_14), U42.N10 (VCCO_14), U42.P7 (VCCO_14), U42.R14 (VCCO_14), U42.T11 (VCCO_14); also elsewhere on the board
ACC_INT: JP7.7, U2.97 (PC7)
AD9523_CS: JP1.5, U2.19 (PF7)
AD9523_EEPROM_SEL: JP1.11, U2.22 (PF10)
AD9523_PD: JP1.1, U2.13 (PF3)
AD9523_REF_SEL: JP1.2, U2.14 (PF4)
AD9523_RESET: JP1.4, U2.18 (PF6)
AD9523_STATUS0: JP1.9, U2.20 (PF8)
AD9523_STATUS1: JP1.10, U2.21 (PF9)
AD9523_SYNC: JP1.3, U2.15 (PF5)
ADAR_1_CS_1V8: U42.L5 (IO_0_34); also elsewhere on the board
ADAR_1_CS_3V3: U2.34 (PA0), U42.F14 (IO_L21N_T3_DQS_A18_15)
ADAR_2_CS_1V8: U42.L4 (IO_L1P_T0_34); also elsewhere on the board
ADAR_2_CS_3V3: U2.35 (PA1), U42.H16 (IO_L22P_T3_A17_15)
ADAR_3_CS_1V8: U42.M4 (IO_L1N_T0_34); also elsewhere on the board
ADAR_3_CS_3V3: U2.36 (PA2), U42.G16 (IO_L22N_T3_A16_15)
ADAR_4_CS_1V8: U42.M2 (IO_L2P_T0_34); also elsewhere on the board
ADAR_4_CS_3V3: U2.37 (PA3), U42.J15 (IO_L23P_T3_FOE_B_15)
ADAR_RX_LOAD_1: U42.M5 (IO_L6P_T0_34); also elsewhere on the board
ADAR_RX_LOAD_2: U42.T2 (IO_L8N_T1_34); also elsewhere on the board
ADAR_RX_LOAD_3: U42.R1 (IO_L7N_T1_34); also elsewhere on the board
ADAR_RX_LOAD_4: U42.N4 (IO_L6N_T0_VREF_34); also elsewhere on the board
ADAR_TR_1: U42.N2 (IO_L3N_T0_DQS_34); also elsewhere on the board
ADAR_TR_2: U42.N1 (IO_L4P_T0_34); also elsewhere on the board
ADAR_TR_3: U42.P1 (IO_L4N_T0_34); also elsewhere on the board
ADAR_TR_4: U42.P4 (IO_L5P_T0_34); also elsewhere on the board
ADAR_TX_LOAD_1: U42.P3 (IO_L5N_T0_34); also elsewhere on the board
ADAR_TX_LOAD_2: U42.T4 (IO_L9P_T1_DQS_34); also elsewhere on the board
ADAR_TX_LOAD_3: U42.R3 (IO_L8P_T1_34); also elsewhere on the board
ADAR_TX_LOAD_4: U42.R2 (IO_L7P_T1_34); also elsewhere on the board
ADC_D0_N: R2.1, U42.P16 (IO_L8N_T1_D12_14); also elsewhere on the board
ADC_D0_P: R2.2, U42.P15 (IO_L8P_T1_D11_14); also elsewhere on the board
ADC_D1_N: R3.1, U42.R16 (IO_L9N_T1_DQS_D13_14); also elsewhere on the board
ADC_D1_P: R3.2, U42.R15 (IO_L9P_T1_DQS_14); also elsewhere on the board
ADC_D2_N: R6.1, U42.T15 (IO_L10N_T1_D15_14); also elsewhere on the board
ADC_D2_P: R6.2, U42.T14 (IO_L10P_T1_D14_14); also elsewhere on the board
ADC_D3_N: R5.1, U42.T13 (IO_L16N_T2_A15_D31_14); also elsewhere on the board
ADC_D3_P: R5.2, U42.R13 (IO_L16P_T2_CSI_B_14); also elsewhere on the board
ADC_D4_N: R7.1, U42.R11 (IO_L17N_T2_A13_D29_14); also elsewhere on the board
ADC_D4_P: R7.2, U42.R10 (IO_L17P_T2_A14_D30_14); also elsewhere on the board
ADC_D5_N: R9.1, U42.T10 (IO_L22N_T3_A04_D20_14); also elsewhere on the board
ADC_D5_P: R9.2, U42.T9 (IO_L22P_T3_A05_D21_14); also elsewhere on the board
ADC_D6_N: R8.1, U42.T8 (IO_L21N_T3_DQS_A06_D22_14); also elsewhere on the board
ADC_D6_P: R8.2, U42.T7 (IO_L21P_T3_DQS_14); also elsewhere on the board
ADC_D7_N: R10.1, U42.R7 (IO_L24N_T3_A00_D16_14); also elsewhere on the board
ADC_D7_P: R10.2, U42.R6 (IO_L24P_T3_A01_D17_14); also elsewhere on the board
ADC_DCO_N: R12.1, U42.P14 (IO_L12N_T1_MRCC_14); also elsewhere on the board
ADC_DCO_P: R12.2, U42.N14 (IO_L12P_T1_MRCC_14); also elsewhere on the board
ADC_OR_N: R11.1, U42.N6 (IO_L19N_T3_A09_D25_VREF_14); also elsewhere on the board
ADC_OR_P: R11.2, U42.M6 (IO_L19P_T3_A10_D26_14); also elsewhere on the board
ADC_PWRD: U42.T5 (IO_L23N_T3_A02_D18_14); also elsewhere on the board
ADF4382_RX_CE: JP13.10, U2.124 (PG9)
ADF4382_RX_CS: JP13.9, U2.125 (PG10)
ADF4382_RX_DELADJ: JP13.12, U2.92 (PG7)
ADF4382_RX_DELSTR: JP13.11, U2.93 (PG8)
ADF4382_RX_LKDET: JP13.13, U2.91 (PG6)
ADF4382_TX_CE: JP13.5, U2.132 (PG15)
ADF4382_TX_CS: JP13.4, U2.129 (PG14)
ADF4382_TX_DELADJ: JP13.7, U2.128 (PG13)
ADF4382_TX_DELSTR: JP13.6, U2.127 (PG12)
ADF4382_TX_LKDET: JP13.8, U2.126 (PG11)
DAC_0: U42.A14 (IO_L7N_T1_AD2N_15); also elsewhere on the board
DAC_1: U42.A13 (IO_L7P_T1_AD2P_15); also elsewhere on the board
DAC_1_VG_CLR: U2.134 (PB4); also elsewhere on the board
DAC_1_VG_LDAC: U2.135 (PB5); also elsewhere on the board
DAC_2: U42.A12 (IO_L5N_T0_AD9N_15); also elsewhere on the board
DAC_2_VG_CLR: U2.139 (PB8); also elsewhere on the board
DAC_2_VG_LDAC: U2.140 (PB9); also elsewhere on the board
DAC_3: U42.B11 (IO_L4N_T0_15); also elsewhere on the board
DAC_4: U42.B10 (IO_L4P_T0_15); also elsewhere on the board
DAC_5: U42.A10 (IO_L3N_T0_DQS_AD1N_15); also elsewhere on the board
DAC_6: U42.A9 (IO_L2N_T0_AD8N_15); also elsewhere on the board
DAC_7: U42.A8 (IO_L2P_T0_AD8P_15); also elsewhere on the board
DAC_SLEEP: U42.A15 (IO_L9N_T1_DQS_AD3N_15); also elsewhere on the board
DIG_0: U2.77 (PD8), U42.F13 (IO_L16N_T2_A27_15)
DIG_1: U2.78 (PD9), U42.E16 (IO_L17P_T2_A26_15)
DIG_2: U2.79 (PD10), U42.D16 (IO_L17N_T2_A25_15)
DIG_3: U2.80 (PD11), U42.F15 (IO_L18P_T2_A24_15)
DIG_4: U2.81 (PD12), U42.E15 (IO_L18N_T2_A23_15)
DIG_5: U2.82 (PD13), U42.H11 (IO_L19P_T3_A22_15)
DIG_6: U2.85 (PD14), U42.G12 (IO_L19N_T3_A21_VREF_15)
DIG_7: U2.86 (PD15), U42.H12 (IO_L20P_T3_A20_15)
EN/DIS_COOLING: JP4.1, U2.123 (PD7)
EN/DIS_RFPA_VDD: JP10.1, U2.122 (PD6)
EN_+1V0_FPGA: SV1.1, U2.58 (PE7)
EN_+1V8_CLOCK: SV1.8, U2.89 (PG4)
EN_+1V8_FPGA: SV1.3, U2.59 (PE8)
EN_+3V3_ADAR12: SV1.9, U2.64 (PE11)
EN_+3V3_ADAR34: SV1.11, U2.65 (PE12)
EN_+3V3_ADTR: SV1.13, U2.66 (PE13)
EN_+3V3_CLOCK: SV1.10, U2.90 (PG5)
EN_+3V3_FPGA: SV1.5, U2.60 (PE9)
EN_+3V3_SW: SV1.15, U2.67 (PE14)
EN_+3V3_VDD_SW: SV1.17, U2.68 (PE15)
EN_+5V0_ADAR: SV1.7, U2.63 (PE10)
EN_+5V0_PA1: SV1.19, U2.56 (PG0)
EN_+5V0_PA2: SV1.2, U2.57 (PG1)
EN_+5V0_PA3: SV1.4, U2.87 (PG2)
EN_+5V5_PA: SV1.6, U2.88 (PG3)
FPGA_ADC_CLOCK_N: J19.2, R4.1, U42.N12 (IO_L13N_T2_MRCC_14)
FPGA_ADC_CLOCK_P: J19.1, R4.2, U42.N11 (IO_L13P_T2_MRCC_14)
FPGA_CLOCK_TEST: JP20.1, U42.H14 (IO_L24P_T3_RS1_15)
FPGA_DAC_CLOCK: J18.1, U42.C13 (IO_L12N_T1_MRCC_15)
FPGA_FLASH_CLK: R51.2, U42.E8 (CCLK_0)
FPGA_FLASH_DQ0: U9.D3 (DQ0), U42.J13 (IO_L1P_T0_D00_MOSI_14)
FPGA_FLASH_DQ1: U9.D2 (DQ1), U42.J14 (IO_L1N_T0_D01_DIN_14)
FPGA_FLASH_DQ2: R53.1, U9.C4 (W/DQ2), U42.K15 (IO_L2P_T0_D02_14)
FPGA_FLASH_DQ3: R54.2, U9.D4 (DQ3/HOLD), U42.K16 (IO_L2N_T0_D03_14)
FPGA_FLASH_NCS: R52.1, U9.C2 (S), U42.L12 (IO_L6P_T0_FCS_B_14)
FPGA_FLASH_NRST: R50.1, U9.A4 (RESET), U42.L13 (IO_L5N_T0_D07_14)
FPGA_PUDC_B: R69.1, U42.L15 (IO_L3P_T0_DQS_PUDC_B_14)
FPGA_SYS_CLOCK: J1.1, U42.E12 (IO_L13P_T2_MRCC_15)
FPGA_TCK: R62.1, R67.1, U42.L7 (TCK_0)
FPGA_TDI: R64.1, R65.1, U42.N7 (TDI_0)
FPGA_TDO: R63.1, R66.1, U42.N8 (TDO_0)
FPGA_TMS: R49.1, R68.1, U42.M7 (TMS_0)
FT2232_USB_D_N: U6.7 (DM), X2.2
FT2232_USB_D_P: U6.8 (DP), X2.3
FT_+1V8: C191.2, U6.12 (VCORE_2), U6.37 (VCORE), U6.49 (VREGOUT), U6.64 (VCORE)
FT_CLKOUT: U6.32 (ACBUS5), U42.C4 (IO_L12N_T1_MRCC_35)
FT_D0: U6.16 (ADBUS0), U42.K1 (IO_L22P_T3_35)
FT_D1: U6.17 (ADBUS1), U42.J3 (IO_L21P_T3_DQS_35)
FT_D2: U6.18 (ADBUS2), U42.H3 (IO_L21N_T3_DQS_35)
FT_D3: U6.19 (ADBUS3), U42.G4 (IO_L16N_T2_35)
FT_D4: U6.21 (ADBUS4), U42.F2 (IO_L15P_T2_DQS_35)
FT_D5: U6.22 (ADBUS5), U42.D1 (IO_L10N_T1_AD15N_35)
FT_D6: U6.23 (ADBUS6), U42.C3 (IO_L7P_T1_AD6P_35)
FT_D7: U6.24 (ADBUS7), U42.C1 (IO_L9P_T1_DQS_AD7P_35)
FT_OE#: U6.33 (ACBUS6), U42.B7 (IO_L1P_T0_AD4P_35)
FT_RD#: U6.28 (ACBUS2), U42.A3 (IO_L4N_T0_35)
FT_RESET#: R61.2, U6.14 (RESET-)
FT_RXF#: U6.26 (ACBUS0), U42.A2 (IO_L8N_T1_AD14N_35)
FT_SIWUA: U6.30 (ACBUS4), U42.A5 (IO_L3P_T0_DQS_AD5P_35)
FT_TXE#: U6.27 (ACBUS1), U42.B2 (IO_L8P_T1_AD14P_35)
FT_WR#: U6.29 (ACBUS3), U42.A4 (IO_L3N_T0_DQS_AD5N_35)
GND: C17.1, C18.2, C19.2, C20.2, C21.2, C22.2, C23.2, C24.2, C25.2, C26.2, C27.2, C28.2, C29.2, C30.2, C31.2, C32.2, C33.2, C34.2, C35.2, C50.1, C55.1, C108.1, C109.1, C110.1, C111.1, C112.1, C113.1, C153.1, C154.1, C155.1, C156.1, C157.1, C158.1, C159.1, C164.1, C176.1, C177.1, C178.1, C179.1, C180.1, C181.1, C182.1, C184.2, C185.2, C186.C (-), C187.C (-), C188.1, C189.2, C190.1, C191.1, C192.1, C193.1, C194.1, C195.1, C279.2, C281.2, C285.1, C287.1, C289.1, C291.1, D2.C, D3.C, D4.C, D5.C, IC1.5 (GND), J1.2, J1.3, J1.4, J1.5, J18.2, J18.3, J18.4, J18.5, J19.MH1, J19.MH2, J19.MH3, J19.MH4, JP1.12, JP2.3, JP3.8, JP4.3, JP7.3, JP8.4, JP9.1, JP9.3, JP10.3, JP13.14, JP17.3, JP18.3, JP20.2, R60.2, R139.1, R140.1, S1.1, S1.2 (1), SV1.12, SV1.14, SV1.16, SV1.18, SV1.20, U2.16 (VSS_2), U2.31 (VSSA), U2.38 (VSS_3), U2.51 (VSS_4), U2.61 (VSS_5), U2.83 (VSS_6), U2.94 (VSS_7), U2.107 (VSS_8), U2.120 (VSS_9), U2.130 (VSS), U2.138 (BOOT0), U6.1 (GND_2), U6.5 (GND_3), U6.10 (AGND), U6.11 (GND_4), U6.13 (TEST), U6.15 (GND_5), U6.25 (GND_6), U6.35 (GND_7), U6.47 (GND_8), U6.51 (GND), U6.65 (EPAD), U9.B3 (VSS), U42.A1 (GND), U42.A11 (GND), U42.B8 (GND), U42.C5 (GND), U42.C15 (GND), U42.D2 (GND), U42.D12 (GND), U42.E9 (GND), U42.F6 (GND), U42.F10 (GND), U42.F16 (GND), U42.G3 (GND), U42.G7 (GNDADC_0), U42.G9 (GND), U42.G13 (GND), U42.H6 (GND), U42.H7 (VREFN_0), U42.H8 (VP_0), U42.J7 (VN_0), U42.J9 (GND), U42.J11 (GND), U42.K4 (GND), U42.K6 (GND), U42.K7 (DXN_0), U42.K8 (DXP_0), U42.K14 (GND), U42.L1 (GND), U42.L11 (GND), U42.M8 (GND), U42.N5 (GND), U42.N15 (GND), U42.P2 (GND), U42.P12 (GND), U42.R9 (GND), U42.T6 (GND), U42.T16 (GND), X2.4, X2.5, X53.5; also elsewhere on the board
GYR_INT: JP7.8, U2.98 (PC8)
M3S_VCTRL: U42.G15 (IO_L24N_T3_RS0_15); also elsewhere on the board
MAG_DRDY: JP7.6, U2.96 (PC6)
MIX_RX_EN: U42.D11 (IO_L14N_T2_SRCC_15); also elsewhere on the board
MIX_TX_EN: U42.C11 (IO_L11P_T1_SRCC_15); also elsewhere on the board
unnamed: C23.1, U2.71 (VCAP_1)
unnamed: C22.1, U2.106 (VCAP_2)
unnamed: C24.1, L5.1, U2.32 (VREF+), U2.33 (VDDA)
unnamed: R51.1, U9.B2 (C)
unnamed: JP3.1, R49.2
unnamed: JP3.3, R62.2
unnamed: JP3.5, R63.2
unnamed: JP3.7, R64.2
unnamed: R110.2, U2.50 (PF12)
unnamed: IC1.4 (DO), R83.1, R146.2
unnamed: R112.2, U2.53 (PF13)
unnamed: D3.A, R114.1
unnamed: R113.2, U2.54 (PF14)
unnamed: R114.2, U2.55 (PF15)
unnamed: D2.A, R113.1
unnamed: D4.A, R112.1
unnamed: D5.A, R110.1
unnamed: R138.2, U42.M9 (M0_0)
unnamed: R139.2, U42.M10 (M1_0)
unnamed: R140.2, U42.M11 (M2_0)
unnamed: R141.2, U42.L9 (PROGRAM_B_0)
unnamed: R142.2, U42.E7 (CFGBVS_0)
unnamed: R144.1, U42.H10 (DONE_0)
unnamed: R143.1, U42.K10 (INIT_B_0)
unnamed: R60.1, U6.6 (REF)
unnamed: C184.1, U6.2 (OSCI), Y1.P1 (1)
unnamed: C185.1, U6.3 (OSCO), Y1.P3 (2)
unnamed: C186.A (+), C188.2, L20.1, U6.9 (VPLL)
unnamed: C187.A (+), C189.1, L19.1, U6.4 (VPHY)
unnamed: IC1.1 (CS), R145.1, U6.63 (EECS)
unnamed: IC1.2 (SK), R84.1, U6.62 (EECLK)
unnamed: IC1.3 (DI), R146.1, U6.61 (EEDATA)
STEPPER_CLK+: JP9.4, U2.119 (PD5)
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

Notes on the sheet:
DIGITAL (FPGA + MICROCONTROLLER)

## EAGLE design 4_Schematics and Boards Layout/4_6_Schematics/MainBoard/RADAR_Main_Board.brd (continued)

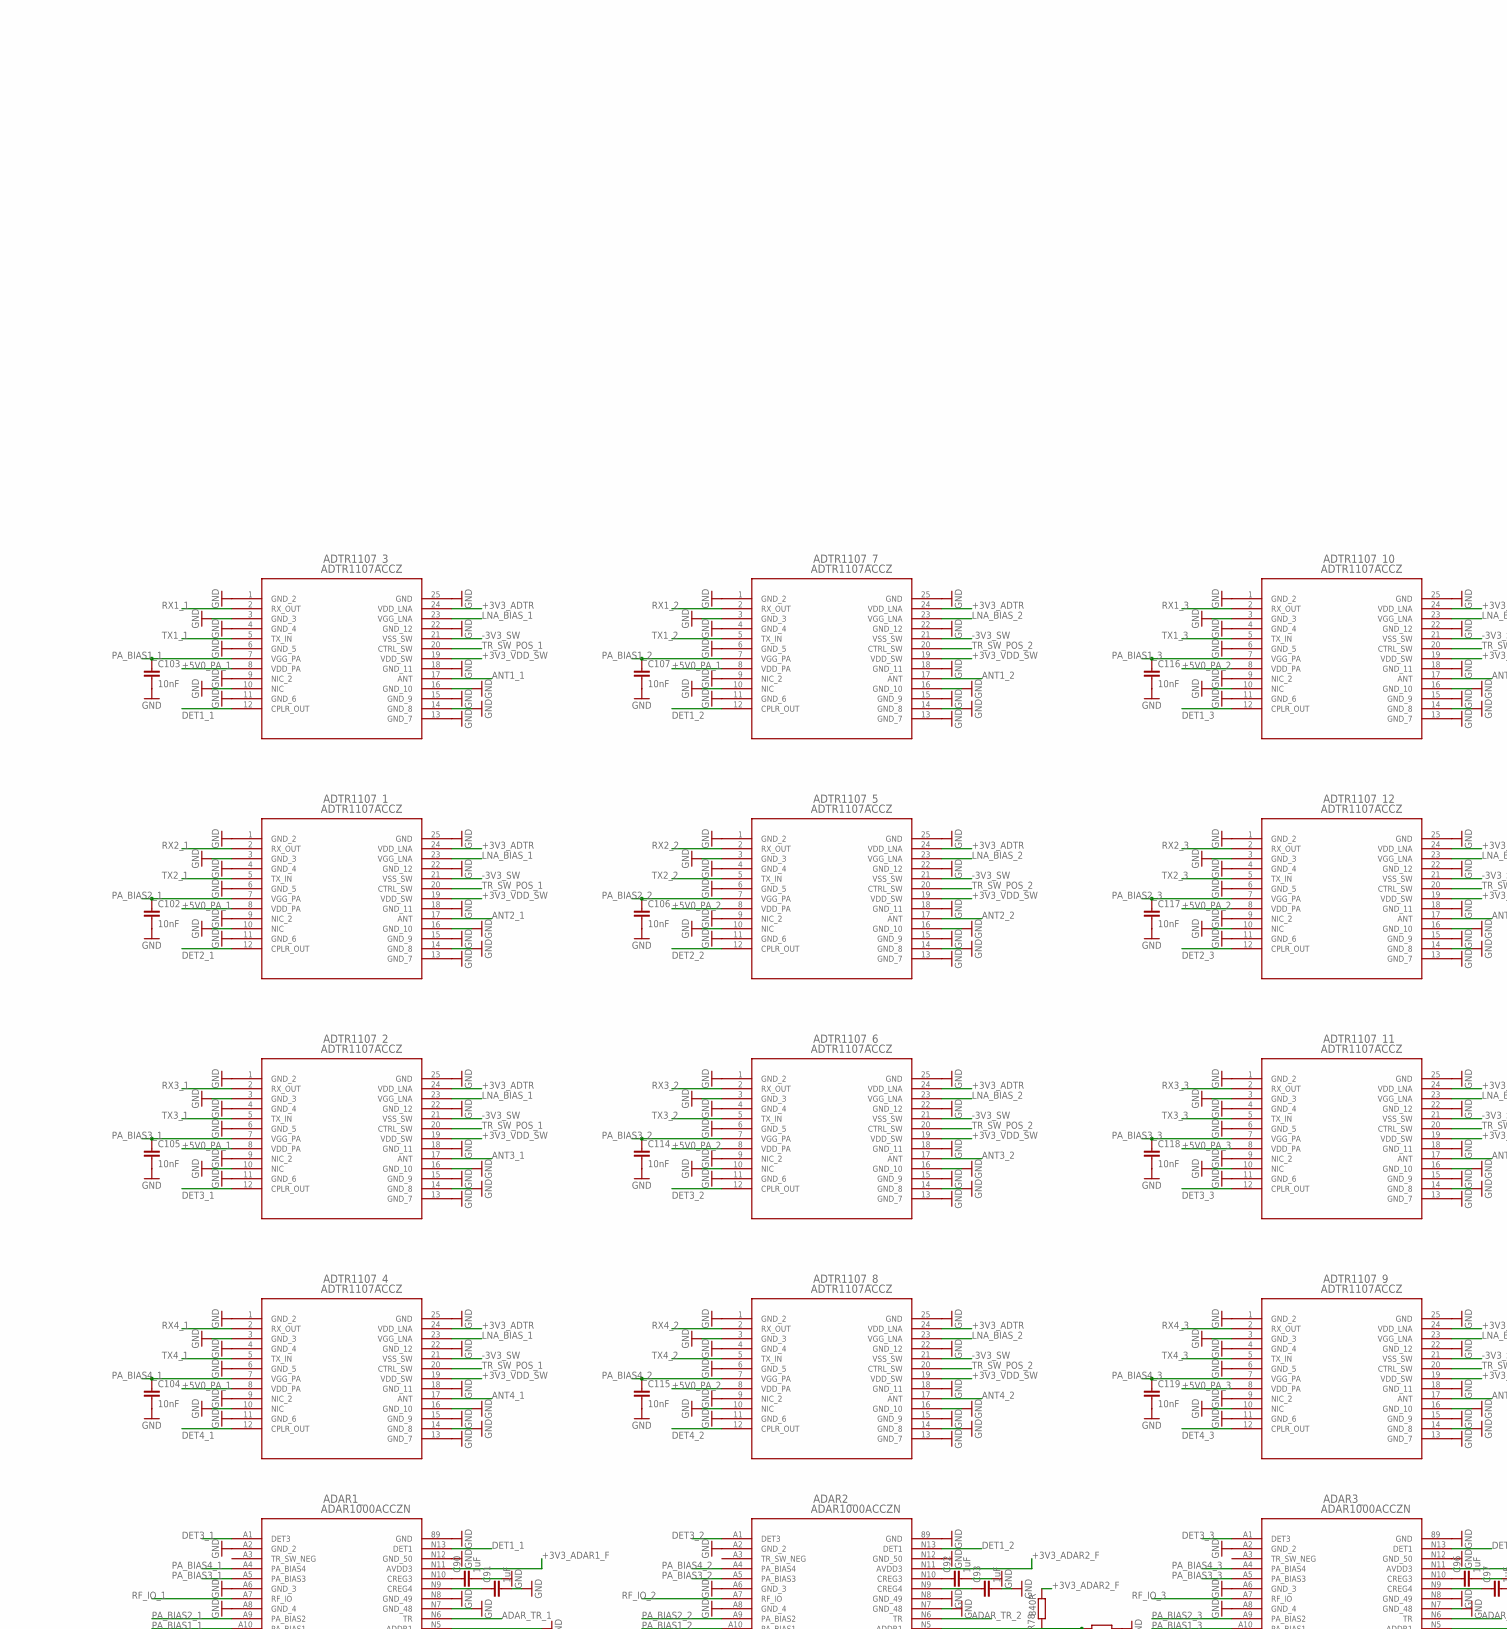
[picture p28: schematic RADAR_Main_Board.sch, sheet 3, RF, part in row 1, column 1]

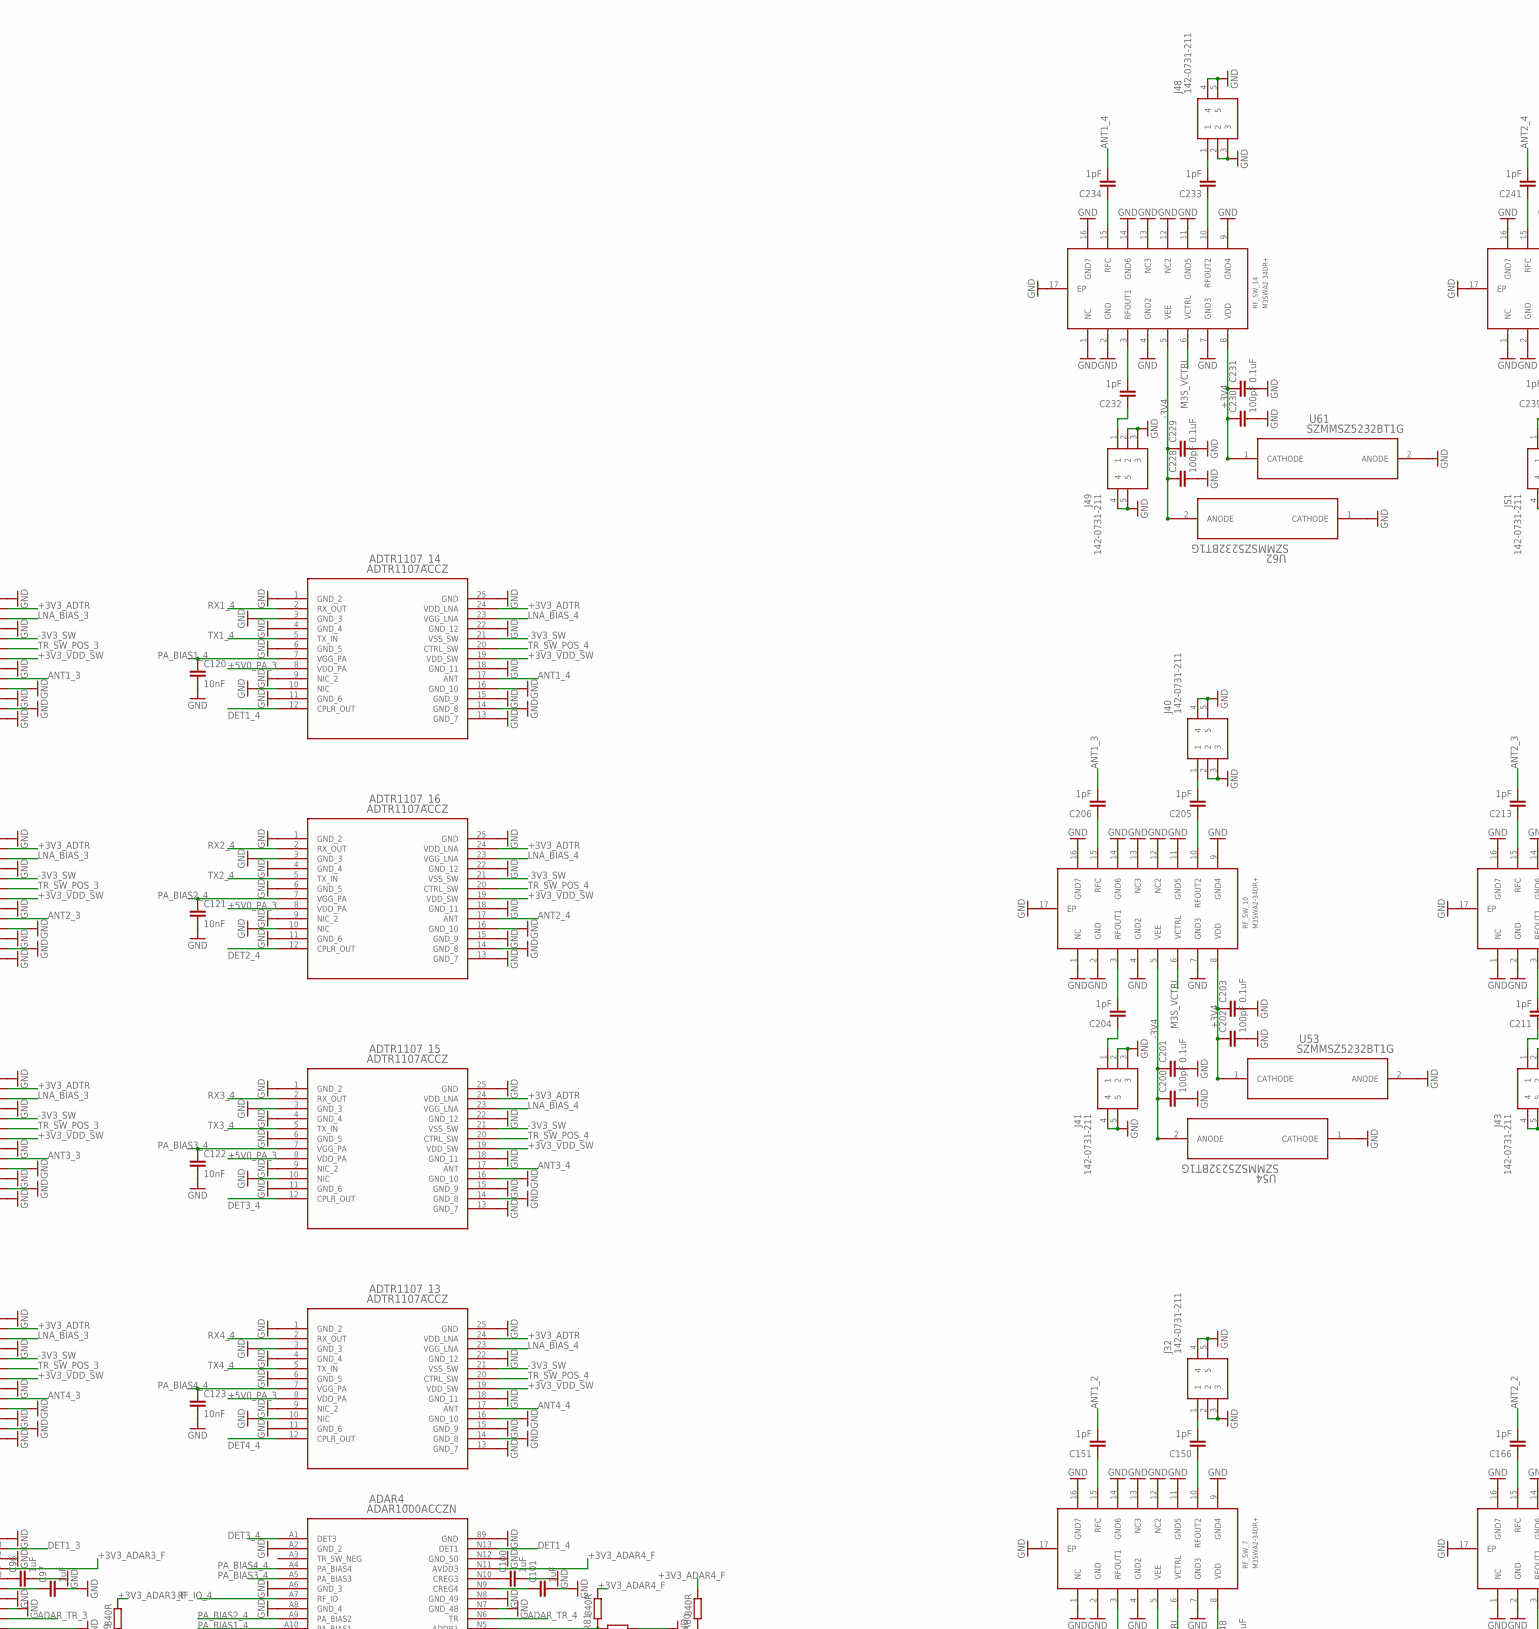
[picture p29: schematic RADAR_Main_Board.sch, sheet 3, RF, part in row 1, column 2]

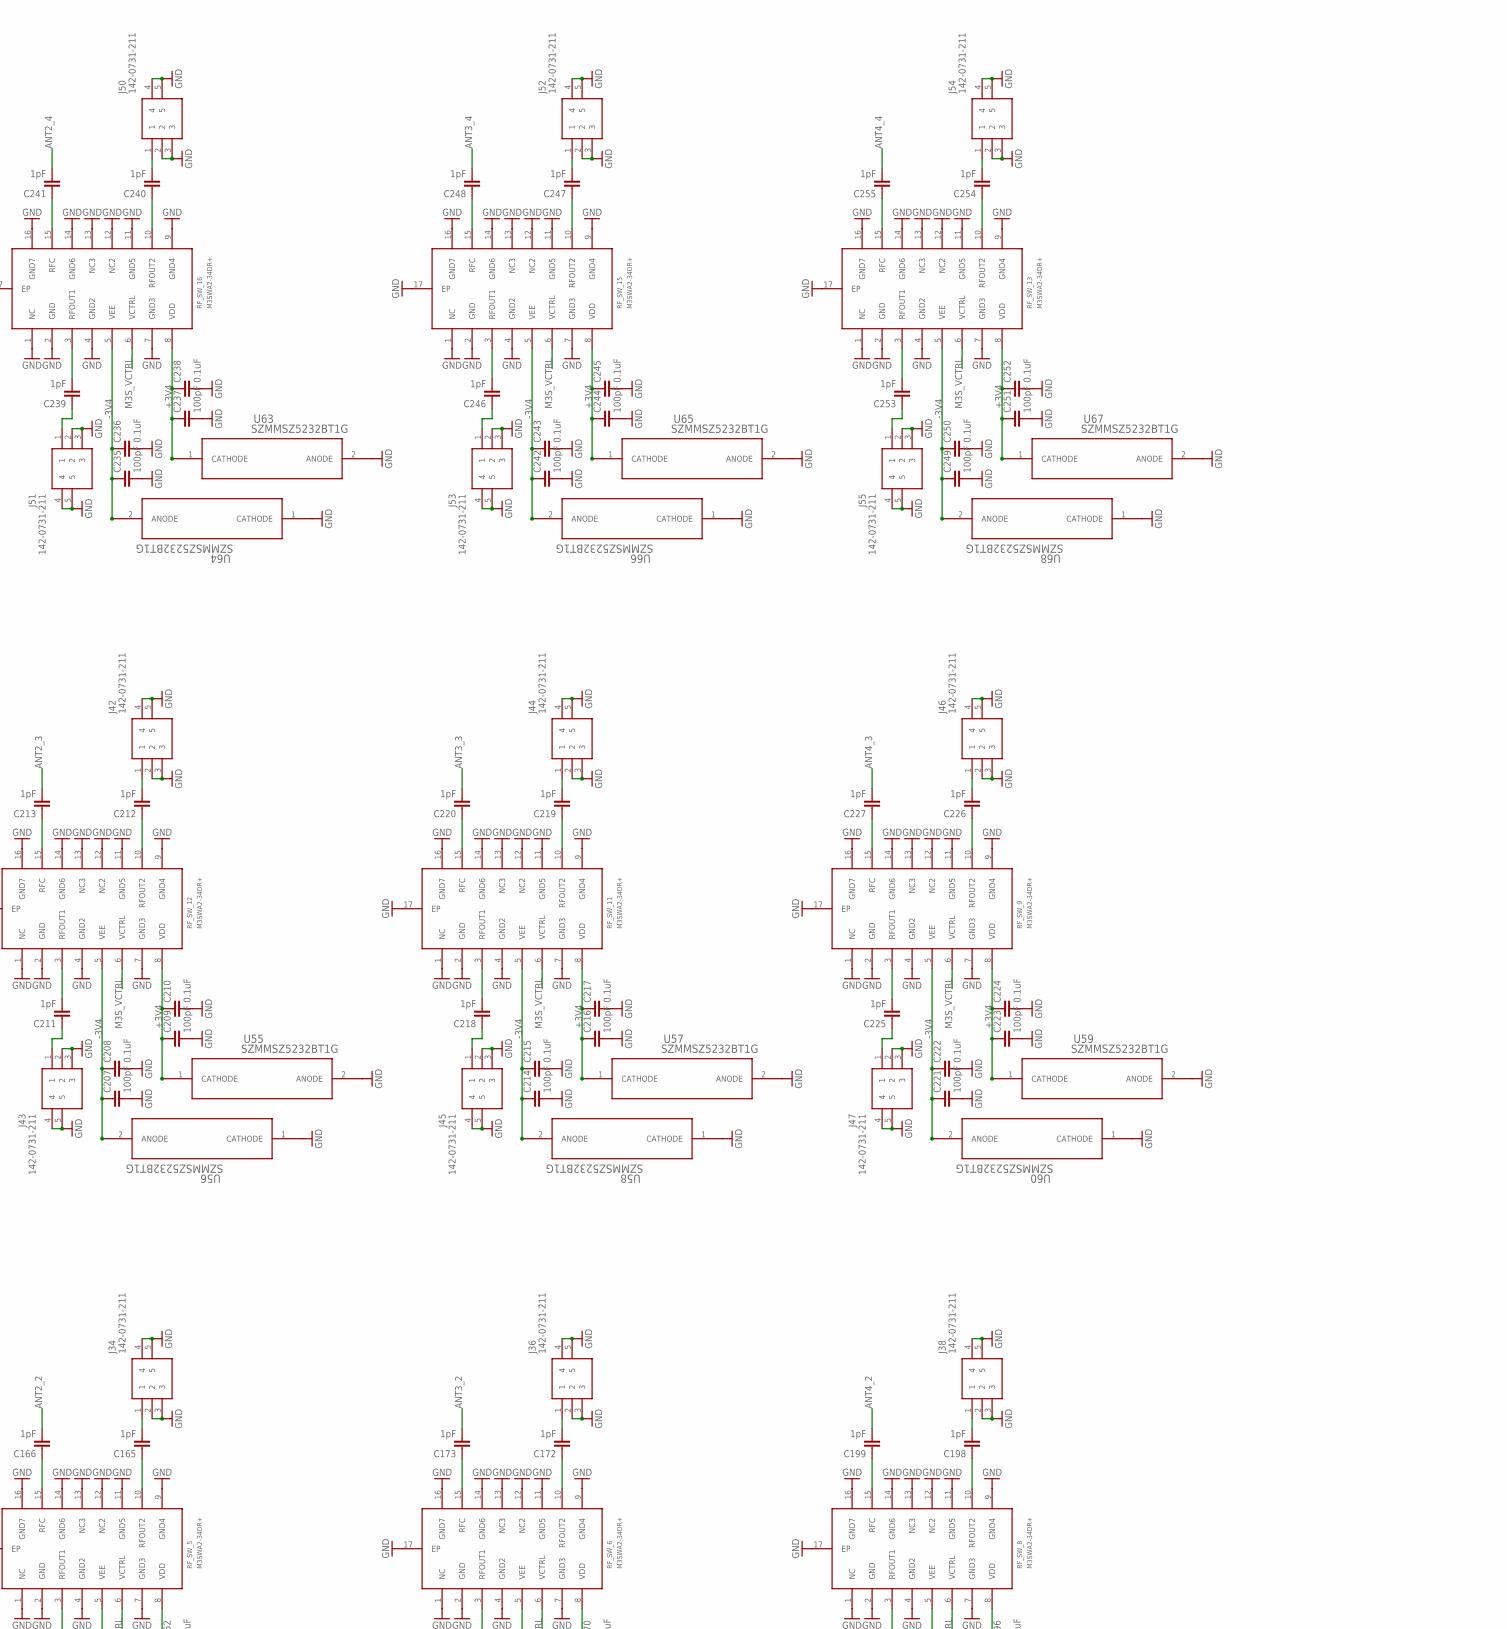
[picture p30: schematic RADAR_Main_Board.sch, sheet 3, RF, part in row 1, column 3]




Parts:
ADAR1_, ADAR2_, ADAR3_, ADAR4_: ADAR1000ACCZN; CC-88-1_ADI
ADTR1107_1, ADTR1107_2, ADTR1107_3, ADTR1107_4, ADTR1107_5, ADTR1107_6, ADTR1107_7, ADTR1107_8, ADTR1107_9, ADTR1107_10, ADTR1107_11, ADTR1107_12, ADTR1107_13, ADTR1107_14, ADTR1107_15, ADTR1107_16: ADTR1107ACCZ; CC-24-8_ADI
C1, C2, C4, C5, C6, C7, C8, C9, C10, C11, C12, C13, C14, C15, C16, C36, C38, C39, C41, C42, C44, C45, C46, C47, C51, C52, C53, C56, C67, C69, C74, C80, C82, C125, C131, C133, C138, C140, C146, C148, C160, C162, C168, C170, C175, C196, C201, C203, C208, C210, C215, C217, C222, C224, C229, C231, C236, C238, C243, C245, C250, C252, C293: 0.1uF; C0201
C3: 2.7pF; C0402
C37, C40: 10uF; C0201
C43: 0.2pF; C0201
C48, C49, C57, C58: 0.1µF; C0402
C54: 0.6pF; C0201
C59, C127: 32.8pF; C0201
C60, C63: 103pF; C0201
C61, C62: 7.8pF; C0201
C64, C65, C268, C270: 25pF; C0201
C66, C68, C73, C79, C81, C124, C130, C132, C137, C139, C145, C147, C152, C161, C167, C169, C174, C183, C200, C202, C207, C209, C214, C216, C221, C223, C228, C230, C235, C237, C242, C244, C249, C251: 100pF; C0201
C70, C71, C72, C83, C84, C85, C126, C128, C129, C134, C135, C136, C142, C143, C144, C149, C150, C151, C163, C165, C166, C171, C172, C173, C197, C198, C199, C204, C205, C206, C211, C212, C213, C218, C219, C220, C225, C226, C227, C232, C233, C234, C239, C240, C241, C246, C247, C248, C253, C254, C255: 1pF; C0201
C86, C87, C88, C89, C90, C91, C92, C93, C94, C95, C96, C97, C98, C99, C100, C101: 1uF; C0201
C102, C103, C104, C105, C106, C107, C114, C115, C116, C117, C118, C119, C120, C121, C122, C123: 10nF; C0201
C141: 106pF; C0201
C272, C274: 18pF; C0201
C308, C309: 22pF; C0201
J20, J22, J23, J24, J25, J26, J27, J28, J29, J30, J31, J32, J33, J34, J35, J36, J37, J38, J39, J40, J41, J42, J43, J44, J45, J46, J47, J48, J49, J50, J51, J52, J53, J54, J55: 142-0731-211; 1420731211
J21: CJT-T-P-HH-ST-TH1; CJTTPHHSTTH1
L2, L8: 12nH; L0201
L3, L4: 159nH; L0201
L6, L7: BLM15HB121SN1; 0402
L9, L10, L24, L28: 50nH; L0201
L22, L25, L26, L27: 107.3nH; L0201
R1, R13: 24R; R0402
R14: 115R; R0201
R15, R32: 4.3k; R0201
R16, R17, R20, R21: 200R; R0201
R18, R19, R34, R35: 0R; R0201
R22: 56R; R0201
R23, R24, R25, R26, R27, R28, R29, R30: 22R; R0201
R31, R115, R116: 50R; R0201
R33: 3k2; R0201
R36: 830R; R0402
R37: 1k; R0402
R38: 20k; R0402
R45, R46, R47, R48, R70, R71, R72, R73, R74, R75, R76, R77, R117: 4.7k; R0201
R55, R56, R57, R58: 1k; R0201
R78, R79, R80, R81: 840R; R0201
R154, R155, R156, R157, R158, R159, R160, R161, R162, R163, R164: 22.1k; R0201
R165, R166: 25R; R0201
R173: 100R; R0201
RF_SW_1, RF_SW_2, RF_SW_3, RF_SW_4, RF_SW_5, RF_SW_6, RF_SW_7, RF_SW_8, RF_SW_9, RF_SW_10, RF_SW_11, RF_SW_12, RF_SW_13, RF_SW_14, RF_SW_15, RF_SW_16: M3SWA2-34DR+; 16_QFN
SJ1: SJ2W; SJ_2
U1: AD9484BCPZ-500; CP_56_5_ADI
U3: AD9708AR; RW_28_ADI
U4, U8: AD8352ACPZ-R7; CP_16_3_ADI
U5, U13: LTC5552IUDBTRMPBF; UDB_12_ADI
U14, U15, U17, U37, U38, U39, U40, U41, U43, U44, U45, U46, U47, U48, U49, U50, U51, U52, U53, U54, U55, U56, U57, U58, U59, U60, U61, U62, U63, U64, U65, U66, U67, U68: SZMMSZ5232BT1G; SOD-123_ONS
U16: EP4RKU+; DG1677-2_MNC
U$1: M3SWA2-34DR+; 16_QFN
U$2, U$3: BPF2

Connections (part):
+1V8_CLOCK_F: C4.2, C5.2, C6.2, C7.2, C8.2, C9.2, C10.2, C11.2, C12.2, C13.2, C14.2, C293.2, SJ1.3, U1.27 (CSB), U1.30 (AVDD_2), U1.32 (AVDD_3), U1.33 (AVDD_4), U1.34 (AVDD_5), U1.37 (AVDD_6), U1.38 (AVDD_7), U1.39 (AVDD_8), U1.41 (AVDD_9), U1.42 (AVDD_10), U1.43 (AVDD_11), U1.46 (AVDD); also elsewhere on the board
+1V8_FPGA: C15.2, C16.2, C36.2, R154.1, R155.1, R156.1, R157.1, U1.7 (DRVDD_2), U1.24 (DRVDD_3), U1.47 (DRVDD); also elsewhere on the board
+3V3_ADAR1_F: ADAR1_.M10 (AVDD3_2), ADAR1_.M11 (AVDD3_3), ADAR1_.N11 (AVDD3); also elsewhere on the board
+3V3_ADAR2_F: ADAR2_.M10 (AVDD3_2), ADAR2_.M11 (AVDD3_3), ADAR2_.N11 (AVDD3), R78.1; also elsewhere on the board
+3V3_ADAR3_F: ADAR3_.M10 (AVDD3_2), ADAR3_.M11 (AVDD3_3), ADAR3_.N11 (AVDD3), R79.1; also elsewhere on the board
+3V3_ADAR4_F: ADAR4_.M10 (AVDD3_2), ADAR4_.M11 (AVDD3_3), ADAR4_.N11 (AVDD3), R80.1, R81.1; also elsewhere on the board
+3V3_ADTR: ADTR1107_1.24 (VDD_LNA), ADTR1107_2.24 (VDD_LNA), ADTR1107_3.24 (VDD_LNA), ADTR1107_4.24 (VDD_LNA), ADTR1107_5.24 (VDD_LNA), ADTR1107_6.24 (VDD_LNA), ADTR1107_7.24 (VDD_LNA), ADTR1107_8.24 (VDD_LNA), ADTR1107_9.24 (VDD_LNA), ADTR1107_10.24 (VDD_LNA), ADTR1107_11.24 (VDD_LNA), ADTR1107_12.24 (VDD_LNA), ADTR1107_13.24 (VDD_LNA), ADTR1107_14.24 (VDD_LNA), ADTR1107_15.24 (VDD_LNA), ADTR1107_16.24 (VDD_LNA); also elsewhere on the board
+3V3_AN: C40.1, C42.1, L6.2; also elsewhere on the board
+3V3_AN1_F: U5.9 (VCC); also elsewhere on the board
+3V3_AN2_F: U13.9 (VCC); also elsewhere on the board
+3V3_FPGA: C37.1, C41.1, U3.17 (REFIO), U3.27 (DVDD); also elsewhere on the board
+3V3_VDD_SW: ADTR1107_1.19 (VDD_SW), ADTR1107_2.19 (VDD_SW), ADTR1107_3.19 (VDD_SW), ADTR1107_4.19 (VDD_SW), ADTR1107_5.19 (VDD_SW), ADTR1107_6.19 (VDD_SW), ADTR1107_7.19 (VDD_SW), ADTR1107_8.19 (VDD_SW), ADTR1107_9.19 (VDD_SW), ADTR1107_10.19 (VDD_SW), ADTR1107_11.19 (VDD_SW), ADTR1107_12.19 (VDD_SW), ADTR1107_13.19 (VDD_SW), ADTR1107_14.19 (VDD_SW), ADTR1107_15.19 (VDD_SW), ADTR1107_16.19 (VDD_SW); also elsewhere on the board
+3V4: C68.1, C69.1, C81.1, C82.1, C124.1, C125.1, C132.1, C133.1, C139.1, C140.1, C147.1, C148.1, C161.1, C162.1, C169.1, C170.1, C183.1, C196.1, C202.1, C203.1, C209.1, C210.1, C216.1, C217.1, C223.1, C224.1, C230.1, C231.1, C237.1, C238.1, C244.1, C245.1, C251.1, C252.1, RF_SW_1.8 (VDD), RF_SW_2.8 (VDD), RF_SW_3.8 (VDD), RF_SW_4.8 (VDD), RF_SW_5.8 (VDD), RF_SW_6.8 (VDD), RF_SW_7.8 (VDD), RF_SW_8.8 (VDD), RF_SW_9.8 (VDD), RF_SW_10.8 (VDD), RF_SW_11.8 (VDD), RF_SW_12.8 (VDD), RF_SW_13.8 (VDD), RF_SW_14.8 (VDD), RF_SW_15.8 (VDD), RF_SW_16.8 (VDD), U14.1 (CATHODE), U17.1 (CATHODE), U38.1 (CATHODE), U40.1 (CATHODE), U43.1 (CATHODE), U45.1 (CATHODE), U47.1 (CATHODE), U49.1 (CATHODE), U51.1 (CATHODE), U53.1 (CATHODE), U55.1 (CATHODE), U57.1 (CATHODE), U59.1 (CATHODE), U61.1 (CATHODE), U63.1 (CATHODE), U65.1 (CATHODE), U67.1 (CATHODE), U$1.8 (VDD); also elsewhere on the board
+5V0_0: U4.8 (VCC_2), U4.13 (VCC), U8.8 (VCC_2), U8.13 (VCC); also elsewhere on the board
+5V0_PA_1: ADTR1107_1.8 (VDD_PA), ADTR1107_2.8 (VDD_PA), ADTR1107_3.8 (VDD_PA), ADTR1107_4.8 (VDD_PA), ADTR1107_7.8 (VDD_PA); also elsewhere on the board
+5V0_PA_2: ADTR1107_5.8 (VDD_PA), ADTR1107_6.8 (VDD_PA), ADTR1107_8.8 (VDD_PA), ADTR1107_10.8 (VDD_PA), ADTR1107_12.8 (VDD_PA); also elsewhere on the board
+5V0_PA_3: ADTR1107_9.8 (VDD_PA), ADTR1107_11.8 (VDD_PA), ADTR1107_13.8 (VDD_PA), ADTR1107_14.8 (VDD_PA), ADTR1107_15.8 (VDD_PA), ADTR1107_16.8 (VDD_PA); also elsewhere on the board
-3V3_SW: ADTR1107_1.21 (VSS_SW), ADTR1107_2.21 (VSS_SW), ADTR1107_3.21 (VSS_SW), ADTR1107_4.21 (VSS_SW), ADTR1107_5.21 (VSS_SW), ADTR1107_6.21 (VSS_SW), ADTR1107_7.21 (VSS_SW), ADTR1107_8.21 (VSS_SW), ADTR1107_9.21 (VSS_SW), ADTR1107_10.21 (VSS_SW), ADTR1107_11.21 (VSS_SW), ADTR1107_12.21 (VSS_SW), ADTR1107_13.21 (VSS_SW), ADTR1107_14.21 (VSS_SW), ADTR1107_15.21 (VSS_SW), ADTR1107_16.21 (VSS_SW); also elsewhere on the board
-3V4: C66.1, C67.1, C73.1, C74.1, C79.1, C80.1, C130.1, C131.1, C137.1, C138.1, C145.1, C146.1, C152.1, C160.1, C167.1, C168.1, C174.1, C175.1, C200.1, C201.1, C207.1, C208.1, C214.1, C215.1, C221.1, C222.1, C228.1, C229.1, C235.1, C236.1, C242.1, C243.1, C249.1, C250.1, RF_SW_1.5 (VEE), RF_SW_2.5 (VEE), RF_SW_3.5 (VEE), RF_SW_4.5 (VEE), RF_SW_5.5 (VEE), RF_SW_6.5 (VEE), RF_SW_7.5 (VEE), RF_SW_8.5 (VEE), RF_SW_9.5 (VEE), RF_SW_10.5 (VEE), RF_SW_11.5 (VEE), RF_SW_12.5 (VEE), RF_SW_13.5 (VEE), RF_SW_14.5 (VEE), RF_SW_15.5 (VEE), RF_SW_16.5 (VEE), U15.2 (ANODE), U37.2 (ANODE), U39.2 (ANODE), U41.2 (ANODE), U44.2 (ANODE), U46.2 (ANODE), U48.2 (ANODE), U50.2 (ANODE), U52.2 (ANODE), U54.2 (ANODE), U56.2 (ANODE), U58.2 (ANODE), U60.2 (ANODE), U62.2 (ANODE), U64.2 (ANODE), U66.2 (ANODE), U68.2 (ANODE), U$1.5 (VEE); also elsewhere on the board
-5V0_ADAR12: ADAR1_.B11 (AVDD), ADAR2_.B11 (AVDD); also elsewhere on the board
-5V0_ADAR34: ADAR3_.B11 (AVDD), ADAR4_.B11 (AVDD); also elsewhere on the board
ADAR_1_CS_1V8: ADAR1_.M3 (CSB), R154.2; also elsewhere on the board
ADAR_2_CS_1V8: ADAR2_.M3 (CSB), R155.2; also elsewhere on the board
ADAR_3_CS_1V8: ADAR3_.M3 (CSB), R156.2; also elsewhere on the board
ADAR_4_CS_1V8: ADAR4_.M3 (CSB), R157.2; also elsewhere on the board
ADAR_RX_LOAD_1: ADAR1_.N2 (RX_LOAD), R47.2; also elsewhere on the board
ADAR_RX_LOAD_2: ADAR2_.N2 (RX_LOAD), R71.2; also elsewhere on the board
ADAR_RX_LOAD_3: ADAR3_.N2 (RX_LOAD), R74.2; also elsewhere on the board
ADAR_RX_LOAD_4: ADAR4_.N2 (RX_LOAD), R77.2; also elsewhere on the board
ADAR_TR_1: ADAR1_.N6 (TR), R158.2; also elsewhere on the board
ADAR_TR_2: ADAR2_.N6 (TR), R159.2; also elsewhere on the board
ADAR_TR_3: ADAR3_.N6 (TR), R160.2; also elsewhere on the board
ADAR_TR_4: ADAR4_.N6 (TR), R161.2; also elsewhere on the board
ADAR_TX_LOAD_1: ADAR1_.N3 (TX_LOAD), R46.2; also elsewhere on the board
ADAR_TX_LOAD_2: ADAR2_.N3 (TX_LOAD), R70.2; also elsewhere on the board
ADAR_TX_LOAD_3: ADAR3_.N3 (TX_LOAD), R73.2; also elsewhere on the board
ADAR_TX_LOAD_4: ADAR4_.N3 (TX_LOAD), R76.2; also elsewhere on the board
ADC_CLK_IN_N: C2.1, R173.2, U1.45 (CLK-)
ADC_CLK_IN_P: C1.1, R173.1, U1.44 (CLK+)
ADC_D0_N: U1.3 (D0-); also elsewhere on the board
ADC_D0_P: U1.4 (D0+); also elsewhere on the board
ADC_D1_N: U1.5 (D1-); also elsewhere on the board
ADC_D1_P: U1.6 (D1+); also elsewhere on the board
ADC_D2_N: U1.9 (D2-); also elsewhere on the board
ADC_D2_P: U1.10 (D2+); also elsewhere on the board
ADC_D3_N: U1.11 (D3-); also elsewhere on the board
ADC_D3_P: U1.12 (D3+); also elsewhere on the board
ADC_D4_N: U1.13 (D4-); also elsewhere on the board
ADC_D4_P: U1.14 (D4+); also elsewhere on the board
ADC_D5_N: U1.15 (D5-); also elsewhere on the board
ADC_D5_P: U1.16 (D5+); also elsewhere on the board
ADC_D6_N: U1.17 (D6-); also elsewhere on the board
ADC_D6_P: U1.18 (D6+); also elsewhere on the board
ADC_D7_N: U1.19 (D7-); also elsewhere on the board
ADC_D7_P: U1.20 (D7+); also elsewhere on the board
ADC_DCO_N: U1.49 (DCO-); also elsewhere on the board
ADC_DCO_P: U1.50 (DCO+); also elsewhere on the board
ADC_IF_IN_N: C45.2, R1.2, R17.1
ADC_IF_IN_P: C44.2, R13.2, R16.2
ADC_OR_N: U1.21 (OR-); also elsewhere on the board
ADC_OR_P: U1.22 (OR+); also elsewhere on the board
ADC_PWRD: R36.2; also elsewhere on the board
AMP_IF_IN_N: C48.1, C52.2, R21.1
AMP_IF_IN_P: C49.2, C51.2, R20.2
AMP_IN_N: C57.1, L10.1, R165.1
AMP_IN_P: C58.2, L9.1, R166.1
ANT1_1: ADTR1107_3.17 (ANT), C72.2
ANT1_2: ADTR1107_7.17 (ANT), C151.2
ANT1_3: ADTR1107_10.17 (ANT), C206.2
ANT1_4: ADTR1107_14.17 (ANT), C234.2
ANT2_1: ADTR1107_1.17 (ANT), C129.2
ANT2_2: ADTR1107_5.17 (ANT), C166.2
ANT2_3: ADTR1107_12.17 (ANT), C213.2
ANT2_4: ADTR1107_16.17 (ANT), C241.2
ANT3_1: ADTR1107_2.17 (ANT), C136.2
ANT3_2: ADTR1107_6.17 (ANT), C173.2
ANT3_3: ADTR1107_11.17 (ANT), C220.2
ANT3_4: ADTR1107_15.17 (ANT), C248.2
ANT4_1: ADTR1107_4.17 (ANT), C144.2
ANT4_2: ADTR1107_8.17 (ANT), C199.2
ANT4_3: ADTR1107_9.17 (ANT), C227.2
ANT4_4: ADTR1107_13.17 (ANT), C255.2
DAC_0: R30.1; also elsewhere on the board
DAC_1: R29.1; also elsewhere on the board
DAC_2: R28.1; also elsewhere on the board
DAC_3: R27.1; also elsewhere on the board
DAC_4: R26.1; also elsewhere on the board
DAC_5: R25.1; also elsewhere on the board
DAC_6: R24.1; also elsewhere on the board
DAC_7: R23.1; also elsewhere on the board
DAC_ACOM: L7.1, U3.20 (ACOM)
DAC_AVDD: C39.2, L6.1, U3.16 (REFLO), U3.24 (AVDD)
DAC_CLOCK: J20.1, R31.2, U3.28 (CLOCK)
DAC_IOUT_F_N: C59.2, L27.2, U5.3 (IF)
DAC_IOUT_F_P: C59.1, L26.2, U5.2 (IF+)
DAC_IOUT_N: C127.2, C308.1, L25.1, R115.2, U3.21 (IOUTB)
DAC_IOUT_P: C127.1, C309.1, L22.1, R116.2, U3.22 (IOUTA)
DAC_SLEEP: R117.2, U3.15 (SLEEP); also elsewhere on the board
DET1_1: ADAR1_.N13 (DET1), ADTR1107_3.12 (CPLR_OUT)
DET1_2: ADAR2_.N13 (DET1), ADTR1107_7.12 (CPLR_OUT)
DET1_3: ADAR3_.N13 (DET1), ADTR1107_10.12 (CPLR_OUT)
DET1_4: ADAR4_.N13 (DET1), ADTR1107_14.12 (CPLR_OUT)
DET2_1: ADAR1_.G13 (DET2), ADTR1107_1.12 (CPLR_OUT)
DET2_2: ADAR2_.G13 (DET2), ADTR1107_5.12 (CPLR_OUT)
DET2_3: ADAR3_.G13 (DET2), ADTR1107_12.12 (CPLR_OUT)
DET2_4: ADAR4_.G13 (DET2), ADTR1107_16.12 (CPLR_OUT)
DET3_1: ADAR1_.A1 (DET3), ADTR1107_2.12 (CPLR_OUT)
DET3_2: ADAR2_.A1 (DET3), ADTR1107_6.12 (CPLR_OUT)
DET3_3: ADAR3_.A1 (DET3), ADTR1107_11.12 (CPLR_OUT)
DET3_4: ADAR4_.A1 (DET3), ADTR1107_15.12 (CPLR_OUT)
DET4_1: ADAR1_.G1 (DET4), ADTR1107_4.12 (CPLR_OUT)
DET4_2: ADAR2_.G1 (DET4), ADTR1107_8.12 (CPLR_OUT)
DET4_3: ADAR3_.G1 (DET4), ADTR1107_9.12 (CPLR_OUT)
DET4_4: ADAR4_.G1 (DET4), ADTR1107_13.12 (CPLR_OUT)
EN_OPAMP_IF_1: U8.15 (ENB)
EN_OPAMP_IF_2: U4.15 (ENB)
GND: ADAR1_.89 (GND), ADAR1_.A2 (GND_2), ADAR1_.A6 (GND_3), ADAR1_.A8 (GND_4), ADAR1_.A12 (GND_5), ADAR1_.A13 (GND_6), ADAR1_.B1 (GND_7), ADAR1_.B2 (GND_8), ADAR1_.B6 (GND_9), ADAR1_.B7 (GND_10), ADAR1_.B8 (GND_11), ADAR1_.B9 (GND_12), ADAR1_.B10 (GND_13), ADAR1_.B12 (GND_14), ADAR1_.B13 (GND_15), ADAR1_.C2 (GND_16), ADAR1_.C12 (GND_17), ADAR1_.D1 (GND_18), ADAR1_.D2 (GND_19), ADAR1_.D12 (GND_20), ADAR1_.D13 (GND_21), ADAR1_.E2 (GND_22), ADAR1_.E12 (GND_23), ADAR1_.F1 (GND_24), ADAR1_.F2 (GND_25), ADAR1_.F12 (GND_26), ADAR1_.F13 (GND_27), ADAR1_.G2 (GND_28), ADAR1_.G12 (GND_29), ADAR1_.H1 (GND_30), ADAR1_.H2 (GND_31), ADAR1_.H12 (GND_32), ADAR1_.H13 (GND_33), ADAR1_.J2 (GND_34), ADAR1_.J12 (GND_35), ADAR1_.K1 (GND_36), ADAR1_.K2 (GND_37), ADAR1_.K12 (GND_38), ADAR1_.K13 (GND_39), ADAR1_.L2 (GND_40), ADAR1_.L12 (GND_41), ADAR1_.M1 (GND_42), ADAR1_.M2 (GND_43), ADAR1_.M7 (GND_44), ADAR1_.M12 (GND_45), ADAR1_.M13 (GND_46), ADAR1_.N1 (GND_47), ADAR1_.N4 (ADDR0), ADAR1_.N5 (ADDR1), ADAR1_.N7 (GND_48), ADAR1_.N8 (GND_49), ADAR1_.N12 (GND_50), ADAR2_.89 (GND), ADAR2_.A2 (GND_2), ADAR2_.A6 (GND_3), ADAR2_.A8 (GND_4), ADAR2_.A12 (GND_5), ADAR2_.A13 (GND_6), ADAR2_.B1 (GND_7), ADAR2_.B2 (GND_8), ADAR2_.B6 (GND_9), ADAR2_.B7 (GND_10), ADAR2_.B8 (GND_11), ADAR2_.B9 (GND_12), ADAR2_.B10 (GND_13), ADAR2_.B12 (GND_14), ADAR2_.B13 (GND_15), ADAR2_.C2 (GND_16), ADAR2_.C12 (GND_17), ADAR2_.D1 (GND_18), ADAR2_.D2 (GND_19), ADAR2_.D12 (GND_20), ADAR2_.D13 (GND_21), ADAR2_.E2 (GND_22), ADAR2_.E12 (GND_23), ADAR2_.F1 (GND_24), ADAR2_.F2 (GND_25), ADAR2_.F12 (GND_26), ADAR2_.F13 (GND_27), ADAR2_.G2 (GND_28)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; also elsewhere on the board
LNA_BIAS_1: ADAR1_.A11 (LNA_BIAS), ADTR1107_1.23 (VGG_LNA), ADTR1107_2.23 (VGG_LNA), ADTR1107_3.23 (VGG_LNA), ADTR1107_4.23 (VGG_LNA)
LNA_BIAS_2: ADAR2_.A11 (LNA_BIAS), ADTR1107_5.23 (VGG_LNA), ADTR1107_6.23 (VGG_LNA), ADTR1107_7.23 (VGG_LNA), ADTR1107_8.23 (VGG_LNA)
LNA_BIAS_3: ADAR3_.A11 (LNA_BIAS), ADTR1107_9.23 (VGG_LNA), ADTR1107_10.23 (VGG_LNA), ADTR1107_11.23 (VGG_LNA), ADTR1107_12.23 (VGG_LNA)
LNA_BIAS_4: ADAR4_.A11 (LNA_BIAS), ADTR1107_13.23 (VGG_LNA), ADTR1107_14.23 (VGG_LNA), ADTR1107_15.23 (VGG_LNA), ADTR1107_16.23 (VGG_LNA)
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

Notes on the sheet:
TX CHAIN: DAC -> RECONSTRUCTION FILTER -> MIXER -> STUB BPF
RX CHAIN: ADC <- 2nd STAGE AMPLIFIER(10dB) <- 1st STAGE AMPLIFIER(15dB) <- IF LPF <- MIXER <- STUB BPF
TX RX RF SWITCH <-> SPLITTER/COMBINER

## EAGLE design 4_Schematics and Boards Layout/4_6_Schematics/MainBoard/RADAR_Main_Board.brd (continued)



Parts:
C256, C257, C298, C302, C303, C304, C305, C306, C307, C310: 100nF; C0201
C261, C263, C265, C267, C269, C271, C273, C275, C280, C282, C284, C286, C288, C290, C292, C294: 4.7nF; C0201
C276, C296, C300: 1µF; C0201
C277, C278, C295, C297, C299, C301: 0.1µF; C0201
JP5, JP6, JP11, JP12, JP14, JP15, JP16, JP19: PINHD-1X3; 1X03
OPA_1, OPA_2, OPA_3, OPA_4: OPA4703EA/250; PW14
R39, R40, R123, R151, R153: 10k; R0201
R41, R43, R59, R82, R85, R86, R87, R88, R93, R94, R99, R100, R101, R102, R107, R108, R109, R118, R124, R125, R126, R127, R128, R129, R130, R131, R133, R134, R135, R136, R137, R147, R148, R149: 1k; R0201
R42, R44: 4.7k; R0201
R89, R90, R91, R92, R95, R96, R97, R98, R103, R104, R105, R106, R119, R120, R121, R122: 2.443k; R0201
R132, R150, R152: 5R; R0201
U7, U69: DAC5578SRGET; RGE24_2P7X2P7
U10, U88, U89: ADS7830IPWR; PW16
U11, U73, U74, U75, U76, U77, U78, U79, U80, U81, U82, U83, U84, U85, U86, U87: INA241A3IDGKRDGK0008A-MFG; DGK0008A-MFG
X3, X38, X39, X40, X41, X42, X43, X44, X45, X46, X47, X48, X49, X50, X51, X52: 22-23-2031
X_1, X_2, X_3, X_4, X_5, X_6, X_7, X_8, X_9, X_10, X_11, X_12, X_13, X_14, X_15, X_16: 22-23-2021

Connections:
+3V3_AN3_F: C256.1, C257.1, R39.2, R40.2, R42.1, R44.1, R123.2, U7.2 (AVDD), U7.8 (VREFIN), U7.9 (RSTSEL), U69.2 (AVDD), U69.8 (VREFIN), U69.9 (RSTSEL); also elsewhere on the board
+3V3_AN4_F: C298.1, C302.1, C303.1, C304.1, C305.1, C306.1, C307.1, C310.1, JP5.1, JP6.1, JP11.1, JP12.1, JP14.1, JP15.1, JP16.1, JP19.1, R132.1, R150.1, R152.1; also elsewhere on the board
+3V3_AN5_F: U11.6 (VS), U73.6 (VS), U74.6 (VS), U75.6 (VS), U76.6 (VS), U77.6 (VS), U78.6 (VS), U79.6 (VS); also elsewhere on the board
+3V3_AN6_F: U80.6 (VS), U81.6 (VS), U82.6 (VS), U83.6 (VS), U84.6 (VS), U85.6 (VS), U86.6 (VS), U87.6 (VS); also elsewhere on the board
+5V5_PA: OPA_1.4 (V+), OPA_2.4 (V+), OPA_3.4 (V+), OPA_4.4 (V+); also elsewhere on the board
-5V5_PA: OPA_1.11 (V-), OPA_2.11 (V-), OPA_3.11 (V-), OPA_4.11 (V-); also elsewhere on the board
DAC_1_VG_CLR: R40.1, U7.12 (!CLR); also elsewhere on the board
DAC_1_VG_LDAC: R42.2, U7.22 (!LDAC); also elsewhere on the board
DAC_2_VG_CLR: R39.1, U69.12 (!CLR); also elsewhere on the board
DAC_2_VG_LDAC: R44.2, U69.22 (!LDAC); also elsewhere on the board
DAC_VOUT_VG_1: R94.1, U7.3 (VOUTA)
DAC_VOUT_VG_2: R87.1, U7.16 (VOUTB)
DAC_VOUT_VG_3: R93.1, U7.4 (VOUTC)
DAC_VOUT_VG_4: R88.1, U7.15 (VOUTD)
DAC_VOUT_VG_5: R82.2, U7.5 (VOUTE)
DAC_VOUT_VG_6: R85.2, U7.14 (VOUTF)
DAC_VOUT_VG_7: R59.2, U7.6 (VOUTG)
DAC_VOUT_VG_8: R86.2, U7.13 (VOUTH)
DAC_VOUT_VG_9: R118.1, U69.3 (VOUTA)
DAC_VOUT_VG_10: R101.1, U69.16 (VOUTB)
DAC_VOUT_VG_11: R109.1, U69.4 (VOUTC)
DAC_VOUT_VG_12: R102.1, U69.15 (VOUTD)
DAC_VOUT_VG_13: R108.2, U69.5 (VOUTE)
DAC_VOUT_VG_14: R99.2, U69.14 (VOUTF)
DAC_VOUT_VG_15: R107.2, U69.6 (VOUTG)
DAC_VOUT_VG_16: R100.2, U69.13 (VOUTH)
GND: C256.2, C257.2, C261.1, C263.1, C265.1, C267.1, C269.1, C271.1, C273.1, C275.1, C276.2, C277.2, C278.2, C280.1, C282.1, C284.1, C286.1, C288.1, C290.1, C292.1, C294.1, C295.2, C296.2, C297.2, C298.2, C299.2, C300.2, C301.2, C302.2, C303.2, C304.2, C305.2, C306.2, C307.2, C310.2, JP5.3, JP6.3, JP11.3, JP12.3, JP14.3, JP15.3, JP16.3, JP19.3, OPA_1.3 (INA+), OPA_1.5 (INB+), OPA_1.10 (INC+), OPA_1.12 (IND+), OPA_2.3 (INA+), OPA_2.5 (INB+), OPA_2.10 (INC+), OPA_2.12 (IND+), OPA_3.3 (INA+), OPA_3.5 (INB+), OPA_3.10 (INC+), OPA_3.12 (IND+), OPA_4.3 (INA+), OPA_4.5 (INB+), OPA_4.10 (INC+), OPA_4.12 (IND+), R41.1, R43.1, U7.10 (ADDR1), U7.11 (ADDR0), U7.17 (GND), U7.25 (EPAD), U10.9 (GND), U10.12 (A0), U10.13 (A1), U11.2 (GND), U11.3 (REF2), U11.7 (REF1), U69.10 (ADDR1), U69.17 (GND), U69.25 (EPAD), U73.2 (GND), U73.3 (REF2), U73.7 (REF1), U74.2 (GND), U74.3 (REF2), U74.7 (REF1), U75.2 (GND), U75.3 (REF2), U75.7 (REF1), U76.2 (GND), U76.3 (REF2), U76.7 (REF1), U77.2 (GND), U77.3 (REF2), U77.7 (REF1), U78.2 (GND), U78.3 (REF2), U78.7 (REF1), U79.2 (GND), U79.3 (REF2), U79.7 (REF1), U80.2 (GND), U80.3 (REF2), U80.7 (REF1), U81.2 (GND), U81.3 (REF2), U81.7 (REF1), U82.2 (GND), U82.3 (REF2), U82.7 (REF1), U83.2 (GND), U83.3 (REF2), U83.7 (REF1), U84.2 (GND), U84.3 (REF2), U84.7 (REF1), U85.2 (GND), U85.3 (REF2), U85.7 (REF1), U86.2 (GND), U86.3 (REF2), U86.7 (REF1), U87.2 (GND), U87.3 (REF2), U87.7 (REF1), U88.9 (GND), U88.12 (A0), U89.9 (GND), U89.13 (A1), X3.3, X38.3, X39.3, X40.3, X41.3, X42.3, X43.3, X44.3, X45.3, X46.3, X47.3, X48.3, X49.3, X50.3, X51.3, X52.3, X_1.2, X_2.2, X_3.2, X_4.2, X_5.2, X_6.2, X_7.2, X_8.2, X_9.2, X_10.2, X_11.2, X_12.2, X_13.2, X_14.2, X_15.2, X_16.2; also elsewhere on the board
unnamed: R123.1, U69.11 (ADDR0)
unnamed: R43.2, U69.21 (TWOC)
unnamed: OPA_4.2 (INA-), R85.1, R89.1
unnamed: U11.8 (IN+), X3.1
unnamed: OPA_4.6 (INB-), R86.1, R90.1
unnamed: U11.1 (IN-), X3.2
unnamed: R124.2, U11.5 (OUT)
unnamed: C261.2, R124.1, U10.1 (CH0)
unnamed: U73.8 (IN+), X38.1
unnamed: OPA_4.9 (INC-), R87.2, R91.2
unnamed: U73.1 (IN-), X38.2
unnamed: R125.2, U73.5 (OUT)
unnamed: OPA_4.13 (IND-), R88.2, R92.2
unnamed: C263.2, R125.1, U10.2 (CH1)
unnamed: U74.8 (IN+), X39.1
unnamed: U74.1 (IN-), X39.2
unnamed: R126.2, U74.5 (OUT)
unnamed: R41.2, U7.21 (TWOC)
unnamed: OPA_2.2 (INA-), R59.1, R95.1
unnamed: C265.2, R126.1, U10.3 (CH2)
unnamed: OPA_2.6 (INB-), R82.1, R96.1
unnamed: U75.8 (IN+), X40.1
unnamed: U75.1 (IN-), X40.2
unnamed: R127.2, U75.5 (OUT)
unnamed: OPA_2.9 (INC-), R93.2, R97.2
unnamed: C267.2, R127.1, U10.4 (CH3)
unnamed: U76.8 (IN+), X41.1
unnamed: OPA_2.13 (IND-), R94.2, R98.2
unnamed: U76.1 (IN-), X41.2
unnamed: R128.2, U76.5 (OUT)
unnamed: C269.2, R128.1, U10.5 (CH4)
unnamed: U77.8 (IN+), X42.1
unnamed: U77.1 (IN-), X42.2
unnamed: R129.2, U77.5 (OUT)
unnamed: OPA_3.2 (INA-), R99.1, R103.1
unnamed: C271.2, R129.1, U10.6 (CH5)
unnamed: OPA_3.6 (INB-), R100.1, R104.1
unnamed: U78.8 (IN+), X43.1
unnamed: U78.1 (IN-), X43.2
unnamed: R130.2, U78.5 (OUT)
unnamed: OPA_3.9 (INC-), R101.2, R105.2
unnamed: C273.2, R130.1, U10.7 (CH6)
unnamed: U79.8 (IN+), X44.1
unnamed: OPA_3.13 (IND-), R102.2, R106.2
unnamed: U79.1 (IN-), X44.2
unnamed: R131.2, U79.5 (OUT)
unnamed: C275.2, R131.1, U10.8 (CH7)
unnamed: C277.1, U10.10 (REFIN/REFOUT)
unnamed: C276.1, R132.2, U10.16 (VDD+)
unnamed: C278.1, U10.11 (COM)
unnamed: OPA_1.2 (INA-), R107.1, R119.1
unnamed: U80.8 (IN+), X45.1
unnamed: OPA_1.6 (INB-), R108.1, R120.1
unnamed: U80.1 (IN-), X45.2
unnamed: R133.2, U80.5 (OUT)
unnamed: C280.2, R133.1, U88.1 (CH0)
unnamed: OPA_1.9 (INC-), R109.2, R121.2
unnamed: U81.8 (IN+), X46.1
unnamed: U81.1 (IN-), X46.2
unnamed: OPA_1.13 (IND-), R118.2, R122.2
unnamed: R134.2, U81.5 (OUT)
unnamed: C282.2, R134.1, U88.2 (CH1)
unnamed: U82.8 (IN+), X47.1
unnamed: U82.1 (IN-), X47.2
unnamed: R135.2, U82.5 (OUT)
unnamed: C284.2, R135.1, U88.3 (CH2)
unnamed: U83.8 (IN+), X48.1
unnamed: U83.1 (IN-), X48.2
unnamed: R136.2, U83.5 (OUT)
unnamed: C286.2, R136.1, U88.4 (CH3)
unnamed: U84.8 (IN+), X49.1
unnamed: U84.1 (IN-), X49.2
unnamed: R137.2, U84.5 (OUT)
unnamed: C288.2, R137.1, U88.5 (CH4)
unnamed: U85.8 (IN+), X50.1
unnamed: U85.1 (IN-), X50.2
unnamed: R147.2, U85.5 (OUT)
unnamed: C290.2, R147.1, U88.6 (CH5)
unnamed: U86.8 (IN+), X51.1
unnamed: U86.1 (IN-), X51.2
unnamed: R148.2, U86.5 (OUT)
unnamed: C292.2, R148.1, U88.7 (CH6)
unnamed: U87.8 (IN+), X52.1
unnamed: U87.1 (IN-), X52.2
unnamed: R149.2, U87.5 (OUT)
unnamed: C294.2, R149.1, U88.8 (CH7)
unnamed: C295.1, U88.10 (REFIN/REFOUT)
unnamed: C296.1, R150.2, R151.2, U88.16 (VDD+)
unnamed: C297.1, U88.11 (COM)
unnamed: R151.1, U88.13 (A1)
unnamed: R153.1, U89.12 (A0)
unnamed: JP5.2, U89.4 (CH3)
unnamed: JP6.2, U89.5 (CH4)
unnamed: JP19.2, U89.1 (CH0)
unnamed: JP12.2, U89.7 (CH6)
unnamed: JP14.2, U89.2 (CH1)
unnamed: JP16.2, U89.8 (CH7)
unnamed: C299.1, U89.10 (REFIN/REFOUT)
unnamed: C300.1, R152.2, R153.2, U89.16 (VDD+)
unnamed: C301.1, U89.11 (COM)
unnamed: JP11.2, U89.6 (CH5)
unnamed: JP15.2, U89.3 (CH2)
STM32_SCL1: U7.20 (SCL), U69.20 (SCL); also elsewhere on the board
STM32_SCL2: U10.14 (SCL), U88.14 (SCL), U89.14 (SCL); also elsewhere on the board
STM32_SDA1: U7.19 (SDA), U69.19 (SDA); also elsewhere on the board
STM32_SDA2: U10.15 (SDA), U88.15 (SDA), U89.15 (SDA); also elsewhere on the board
VG_1: OPA_2.14 (OUTD), R98.1, X_7.1
VG_2: OPA_4.8 (OUTC), R91.1, X_16.1
VG_3: OPA_2.8 (OUTC), R97.1, X_8.1
VG_4: OPA_4.14 (OUTD), R92.1, X_15.1
VG_5: OPA_2.7 (OUTB), R96.2, X_4.1
VG_6: OPA_4.1 (OUTA), R89.2, X_11.1
VG_7: OPA_2.1 (OUTA), R95.2, X_3.1
VG_8: OPA_4.7 (OUTB), R90.2, X_12.1
VG_9: OPA_1.14 (OUTD), R122.1, X_5.1
VG_10: OPA_3.8 (OUTC), R105.1, X_14.1
VG_11: OPA_1.8 (OUTC), R121.1, X_6.1
VG_12: OPA_3.14 (OUTD), R106.1, X_13.1
VG_13: OPA_1.7 (OUTB), R120.2, X_2.1
VG_14: OPA_3.1 (OUTA), R103.2, X_9.1
VG_15: OPA_1.1 (OUTA), R119.2, X_1.1
VG_16: OPA_3.7 (OUTB), R104.2, X_10.1

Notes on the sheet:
RF POWER AMPLIFIER IDQ_ID CURRENT SENSOR
RF POWER AMPLIFIER BIAS VG CONTROL
RF POWER AMPLIFIER TEMPERATURE SENSING


Board: 10 copper layers, 260.0 x 300.0 mm, 789 parts (0 on the bottom side), 649 nets.

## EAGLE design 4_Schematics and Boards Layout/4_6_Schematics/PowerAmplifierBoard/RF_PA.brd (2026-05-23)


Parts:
22V: AK300/2
C1, C4, C5: 10µF; C1206
C2, C3, C6, C7, C8, C9: 0.1µF; C0402
J1, J2: 142-0731-211; 1420731211
R1, R4: 10R; R0402
R2, R3, R5, R7, R8, R9: 0R; R0402
R6: 0R; R0603
R10: 5mR; WSL2816_VIS
U$1: QPA2962_B
X2: 22-23-2021
X3: 22-23-2031

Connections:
GND: 22V.2, C1.1, C2.1, C3.1, C4.1, C5.2, C6.1, C7.1, C8.2, C9.2, J1.2, J1.3, J1.4, J1.5, J2.2, J2.3, J2.4, J2.5, U$1.GND, X2.2, X3.3
unnamed: C3.2, R3.1
unnamed: J1.1, U$1.RFIN
unnamed: C1.2, R1.1
unnamed: C2.2, R2.1
unnamed: C4.2, R4.1
unnamed: C6.2, R6.1
unnamed: C7.2, R5.1
unnamed: J2.1, U$1.RFOUT
unnamed: C5.1, R7.2
unnamed: C8.1, R8.2
unnamed: C9.1, R9.2
VD: 22V.1, R10.2, X3.1
VG: R1.2, R2.2, R3.2, U$1.VG, X2.1
VIN_M: R4.2, R5.2, R6.2, R7.1, R8.1, R9.1, R10.1, U$1.VD1, U$1.VD2, X3.2


Board: 4 copper layers, 35.0 x 60.0 mm, 25 parts (0 on the bottom side), 15 nets.

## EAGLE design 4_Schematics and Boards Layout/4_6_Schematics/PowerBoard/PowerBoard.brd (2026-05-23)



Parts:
C1, C6, C12, C18, C29, C30, C36, C42, C54, C60, C66, C71, C76, C77, C83, C89, C109, C119, C129, C144, C154: 0.1µF; C0805
C2, C3, C7, C8, C11, C13, C14, C17, C19, C20, C23, C31, C32, C35, C37, C38, C41, C43, C44, C47, C48, C49, C55, C56, C59, C61, C62, C65, C67, C68, C72, C73, C78, C79, C82, C84, C85, C88, C90, C91, C110, C111, C120, C121, C130, C131, C145, C146, C149, C155, C156, C159: 22µF; C0603
C4, C5, C9, C10, C15, C16, C21, C22, C24, C25, C28, C33, C34, C39, C40, C45, C46, C50, C51, C52, C53, C57, C58, C63, C64, C69, C70, C74, C75, C80, C81, C86, C87, C92, C93, C94, C95, C108, C112, C113, C114, C115, C118, C122, C123, C124, C125, C128, C132, C133, C134, C135, C138, C139, C140, C143, C147, C148, C157, C158: 10µF; C0805
C26, C27, C106, C107, C116, C117, C126, C127, C136, C137, C141, C142: 1µF; C0805
C96, C97, C98, C99, C100, C101, C102, C103, C104, C105: T521W476M020ATE045; T521W
C150, C152, C160, C162: 10nF; C0603
C151, C153, C161, C163: 10µF; C0603
R1: 3.09k; M0805
R2, R4, R6, R8, R10, R12, R14, R16, R18, R20, R22, R24, R26, R28, R30, R32, R34, R36, R38, R40, R42, R44, R46, R48, R50, R52, R56: 10k; M0805
R3: 13.7k; M0805
R5, R7, R11, R13, R15, R19: 32.2k; M0805
R9, R35, R43, R47: 12k; M0805
R17, R23, R25, R27, R29, R31, R37, R41, R45, R51, R55: 56.2k; M0805
R21: 34.8k; M0805
R33: 61.9k; M0805
R39: 2k; M0805
R49: 23.4k; M0805
R53, R57: 35.7k; M0805
R54, R58: 11.5k; M0805
SV1: MA10-2
U1, U2, U3, U4, U6, U7, U8, U9, U10, U11, U12, U13, U14, U15, U16, U17, U24, U26, U28, U31, U33: TPS562208DDCT; DDC0006A_N
U5, U23, U25, U27, U29, U30: ADM7151ACPZ-04-R7; CP_8_11_ADI
U18, U19, U20, U21, U22: LM2662MX/NOPB; M08A
U32, U34: TPS7A8300RGRR; RGR20_2P05X2P05_TEX
U$1, U$2: 2.2µH; IND_VLP8040T-1R0N_TDK
U$3, U$4, U$5, U$6, U$7, U$8, U$9, U$10, U$11, U$12, U$13, U$14, U$15, U$16, U$17, U$18, U$19, U$20, U$21: 3.3µH; IND_VLP8040T-1R0N_TDK
X1: AK300/2
X2, X3, X4, X5, X6, X7, X8, X9, X10, X11, X12, X13, X14, X15, X16, X17, X18, X19, X20, X21, X22, X23, X24, X25, X26, X27, X28, X29, X30, X31, X32, X33, X34, X35: 22-23-2021

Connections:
+1V0_FPGA: C2.1, C3.1, R1.2, U$1.1, X4.1
+1V8_CLOCK: C115.2, U25.2 (VOUT), X10.1
+1V8_FPGA: C7.1, C8.1, C11.1, R3.2, U$2.1, X5.1
+3V3: C13.1, C14.1, C17.1, R5.2, U$3.1, X16.1
+3V3_ADAR_12: C31.1, C32.1, C35.1, R11.2, U$6.1, X14.1
+3V3_ADAR_34: C37.1, C38.1, C41.1, R13.2, U$7.1, X15.1
+3V3_ADTR: C149.1, R53.2, U32.1 (OUT_2), U32.19 (OUT_3), U32.20 (OUT), X34.1
+3V3_AN: C25.2, U5.2 (VOUT), X12.1
+3V3_CLOCK: C53.2, U23.2 (VOUT), X11.1
+3V3_FPGA: C19.1, C20.1, C23.1, R7.2, U$4.1, X27.1
+3V3_LO_1: C125.2, U27.2 (VOUT), X8.1
+3V3_LO_2: C135.2, U29.2 (VOUT), X7.1
+3V3_SW: C55.1, C56.1, C59.1, R19.2, U18.8 (V+), U$10.1, X29.1
+3V3_VDD_SW: C43.1, C44.1, C47.1, R15.2, U$8.1, X30.1
+3V3_XO: C159.1, R57.2, U34.1 (OUT_2), U34.19 (OUT_3), U34.20 (OUT), X35.1
+3V4: C61.1, C62.1, C65.1, R21.2, U19.8 (V+), U$11.1, X23.1
+5V0_0: C28.2, C67.1, C68.1, R23.2, U5.7 (EN), U5.8 (VIN), U$12.1, X22.1
+5V0_1: C48.1, C49.1, C108.2, R17.2, U23.8 (VIN), U$5.1, X2.1
+5V0_2: C110.1, C111.1, C118.2, R37.2, U25.8 (VIN), U$9.1, X9.1
+5V0_3: C120.1, C121.1, C128.2, R41.2, U27.7 (EN), U27.8 (VIN), U$18.1, X17.1
+5V0_4: C130.1, C131.1, C138.2, R45.2, U29.7 (EN), U29.8 (VIN), U$19.1, X25.1
+5V0_5: C155.1, C156.1, C163.1, R55.2, U34.14 (EN), U34.15 (IN_2), U34.16 (IN_3), U34.17 (IN), U$21.1, X28.1
+5V0_ADAR: C72.1, C73.1, R25.2, U20.8 (V+), U21.8 (V+), U$13.1, X13.1
+5V0_ADTR: C145.1, C146.1, C153.1, R51.2, U32.15 (IN_2), U32.16 (IN_3), U32.17 (IN), U$20.1, X26.1
+5V0_LO: C140.2, U30.2 (VOUT), X6.1; also elsewhere on the board
+5V0_PA_1: C78.1, C79.1, R27.2, U$14.1, X31.1
+5V0_PA_2: C84.1, C85.1, R29.2, U$15.1, X32.1
+5V0_PA_3: C90.1, C91.1, R31.2, U$16.1, X33.1
+5V5_PA: C82.1, C88.1, R33.2, U22.8 (V+), U$17.1, X3.1
-3V3_SW: C97.2 (-), U18.5 (OUT), X18.1
-3V4: C99.2 (-), U19.5 (OUT), X24.1
-5V0_ADAR12: C101.2 (-), U20.5 (OUT), X21.1
-5V0_ADAR34: C103.2 (-), U21.5 (OUT), X20.1
-5V5_PA: C105.2 (-), U22.5 (OUT), X19.1
EN_+1V0_FPGA: SV1.1, U1.5 (EN)
EN_+1V8_CLOCK: SV1.8, U25.7 (EN)
EN_+1V8_FPGA: SV1.3, U2.5 (EN)
EN_+3V3_ADAR12: SV1.9, U6.5 (EN)
EN_+3V3_ADAR34: SV1.11, U7.5 (EN)
EN_+3V3_ADTR: SV1.13, U32.14 (EN)
EN_+3V3_CLOCK: SV1.10, U23.7 (EN)
EN_+3V3_FPGA: SV1.5, U4.5 (EN)
EN_+3V3_SW: SV1.15, U10.5 (EN)
EN_+3V3_VDD_SW: SV1.17, U8.5 (EN)
EN_+5V0_ADAR: SV1.7, U13.5 (EN)
EN_+5V0_PA1: SV1.19, U14.5 (EN)
EN_+5V0_PA2: SV1.2, U15.5 (EN)
EN_+5V0_PA3: SV1.4, U16.5 (EN)
EN_+5V5_PA: SV1.6, U17.5 (EN)
GND: C2.2, C3.2, C4.2, C5.2, C7.2, C8.2, C9.2, C10.2, C11.2, C13.2, C14.2, C15.2, C16.2, C17.2, C19.2, C20.2, C21.2, C22.2, C23.2, C24.1, C25.1, C26.1, C27.1, C28.1, C31.2, C32.2, C33.2, C34.2, C35.2, C37.2, C38.2, C39.2, C40.2, C41.2, C43.2, C44.2, C45.2, C46.2, C47.2, C48.2, C49.2, C50.2, C51.2, C52.1, C53.1, C55.2, C56.2, C57.2, C58.2, C59.2, C61.2, C62.2, C63.2, C64.2, C65.2, C67.2, C68.2, C69.2, C70.2, C72.2, C73.2, C74.2, C75.2, C78.2, C79.2, C80.2, C81.2, C82.2, C84.2, C85.2, C86.2, C87.2, C88.2, C90.2, C91.2, C92.2, C93.2, C94.2, C95.2, C97.1 (+), C99.1 (+), C101.1 (+), C103.1 (+), C105.1 (+), C106.1, C107.1, C108.1, C110.2, C111.2, C112.2, C113.2, C114.1, C115.1, C116.1, C117.1, C118.1, C120.2, C121.2, C122.2, C123.2, C124.1, C125.1, C126.1, C127.1, C128.1, C130.2, C131.2, C132.2, C133.2, C134.1, C135.1, C136.1, C137.1, C138.1, C139.1, C140.1, C141.1, C142.1, C143.1, C145.2, C146.2, C147.2, C148.2, C149.2, C151.2, C152.2, C153.2, C155.2, C156.2, C157.2, C158.2, C159.2, C161.2, C162.2, C163.2, R2.1, R4.1, R6.1, R8.1, R10.1, R12.1, R14.1, R16.1, R18.1, R20.1, R22.1, R24.1, R26.1, R28.1, R30.1, R32.1, R34.1, R36.1, R38.1, R40.1, R42.1, R44.1, R46.1, R48.1, R50.1, R52.1, R54.1, R56.1, R58.1, SV1.12, SV1.14, SV1.16, SV1.18, SV1.20, U1.1 (GND), U2.1 (GND), U3.1 (GND), U4.1 (GND), U5.4 (GND), U5.9 (EPAD), U6.1 (GND), U7.1 (GND), U8.1 (GND), U9.1 (GND), U10.1 (GND), U11.1 (GND), U12.1 (GND), U13.1 (GND), U14.1 (GND), U15.1 (GND), U16.1 (GND), U17.1 (GND), U18.3 (GND), U18.6 (LV), U19.3 (GND), U19.6 (LV), U20.3 (GND), U20.6 (LV), U21.3 (GND), U21.6 (LV), U22.3 (GND), U22.6 (LV), U23.4 (GND), U23.9 (EPAD), U24.1 (GND), U25.4 (GND), U25.9 (EPAD), U26.1 (GND), U27.4 (GND), U27.9 (EPAD), U28.1 (GND), U29.4 (GND), U29.9 (EPAD), U30.4 (GND), U30.9 (EPAD), U31.1 (GND), U32.8 (GND_2), U32.18 (GND), U32.21 (EPAD), U33.1 (GND), U34.8 (GND_2), U34.18 (GND), U34.21 (EPAD), X1.2, X2.2, X3.2, X4.2, X5.2, X6.2, X7.2, X8.2, X9.2, X10.2, X11.2, X12.2, X13.2, X14.2, X15.2, X16.2, X17.2, X18.2, X19.2, X20.2, X21.2, X22.2, X23.2, X24.2, X25.2, X26.2, X27.2, X28.2, X29.2, X30.2, X31.2, X32.2, X33.2, X34.2, X35.2; also elsewhere on the board
unnamed: C1.2, U1.2 (SW), U$1.2
unnamed: C1.1, U1.6 (VBST)
unnamed: C6.2, U2.2 (SW), U$2.2
unnamed: R1.1, R2.2, U1.4 (VFB)
unnamed: C6.1, U2.6 (VBST)
unnamed: R3.1, R4.2, U2.4 (VFB)
unnamed: C12.2, U3.2 (SW), U$3.2
unnamed: C12.1, U3.6 (VBST)
unnamed: R5.1, R6.2, U3.4 (VFB)
unnamed: C18.2, U4.2 (SW), U$4.2
unnamed: C18.1, U4.6 (VBST)
unnamed: R7.1, R8.2, U4.4 (VFB)
unnamed: C24.2, U5.1 (VREG)
unnamed: C139.2, U30.1 (VREG)
unnamed: C26.2, U5.3 (BYP)
unnamed: C30.2, U6.2 (SW), U$6.2
unnamed: C30.1, U6.6 (VBST)
unnamed: R11.1, R12.2, U6.4 (VFB)
unnamed: C36.2, U7.2 (SW), U$7.2
unnamed: C36.1, U7.6 (VBST)
unnamed: R13.1, R14.2, U7.4 (VFB)
unnamed: C42.2, U8.2 (SW), U$8.2
unnamed: C42.1, U8.6 (VBST)
unnamed: R15.1, R16.2, U8.4 (VFB)
unnamed: R9.1, R10.2, U5.5 (REF_SENSE)
unnamed: C29.2, U9.2 (SW), U$5.2
unnamed: C27.2, R9.2, U5.6 (REF)
unnamed: C54.2, U10.2 (SW), U$10.2
unnamed: C54.1, U10.6 (VBST)
unnamed: R19.1, R20.2, U10.4 (VFB)
unnamed: C60.2, U11.2 (SW), U$11.2
unnamed: C60.1, U11.6 (VBST)
unnamed: R21.1, R22.2, U11.4 (VFB)
unnamed: C66.2, U12.2 (SW), U$12.2
unnamed: C66.1, U12.6 (VBST)
unnamed: R23.1, R24.2, U12.4 (VFB)
unnamed: C71.2, U13.2 (SW), U$13.2
unnamed: C71.1, U13.6 (VBST)
unnamed: R25.1, R26.2, U13.4 (VFB)
unnamed: C77.2, U14.2 (SW), U$14.2
unnamed: C77.1, U14.6 (VBST)
unnamed: R27.1, R28.2, U14.4 (VFB)
unnamed: C83.2, U15.2 (SW), U$15.2
unnamed: C83.1, U15.6 (VBST)
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

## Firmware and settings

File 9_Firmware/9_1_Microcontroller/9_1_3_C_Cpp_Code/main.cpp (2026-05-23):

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
/* Includes ------------------------------------------------------------------*/
#include "main.h"
#include "usb_device.h"
#include "USBHandler.h"
#include "usbd_cdc_if.h"
#include "ADAR1000_Manager.h"
#include "ADAR1000_AGC.h"
extern "C" {
#include "ad9523.h"
}
#include "no_os_delay.h"
#include "no_os_alloc.h"
#include "no_os_print_log.h"
#include "no_os_error.h"
#include "no_os_units.h"
#include "no_os_dma.h"
#include "no_os_spi.h"
#include "no_os_uart.h"
#include "no_os_util.h"
#include <stdint.h>
#include <errno.h>
#include <math.h>
#include <stdio.h>
#include <string.h>
#include <inttypes.h>
#include <iostream>
#include <vector>
#include "stm32_spi.h"
#include "stm32_delay.h"
extern "C" {
#include "um982_gps.h"
}
extern "C" {
#include "GY_85_HAL.h"
}
#include "BMP180.h"
extern "C" {
#include "platform_noos_stm32.h"
}
extern "C" {

#include "adf4382a_manager.h"
#include "adf4382.h"
#include "no_os_delay.h"
#include "no_os_error.h"
#include "diag_log.h"
}
#include <cmath>
#include "DAC5578.h"
#include "ADS7830.h"
#include "gps_handler.h"

#include "stm32f7xx_hal.h"




/* USER CODE BEGIN PD */


/* -------- GPIO index mapping for no-OS interface -------- */
#define GPIO_IDX_TX_CS       0
#define GPIO_IDX_RX_CS       1
#define GPIO_IDX_TX_DELSTR   2
#define GPIO_IDX_TX_DELADJ   3
#define GPIO_IDX_RX_DELSTR   4
#define GPIO_IDX_RX_DELADJ   5
#define GPIO_IDX_TX_CE       6
#define GPIO_IDX_RX_CE       7
#define GPIO_IDX_SW_SYNC     8

/* USER CODE END PD */


I2C_HandleTypeDef hi2c1;
I2C_HandleTypeDef hi2c2;
I2C_HandleTypeDef hi2c3;

SPI_HandleTypeDef hspi1;
SPI_HandleTypeDef hspi4;

TIM_HandleTypeDef htim1;
TIM_HandleTypeDef htim3;  // B15 fix: DELADJ PWM timer (CH2=TX, CH3=RX)

UART_HandleTypeDef huart5;
UART_HandleTypeDef huart3;

/* USER CODE BEGIN PV */
// UM982 dual-antenna GPS receiver
UM982_GPS_t um982;

// Global data structures
GPS_Data_t current_gps_data = {0};

// Global USB handler
USBHandler usbHandler;
extern USBD_HandleTypeDef hUsbDeviceFS;

// Buffer for USB reception
uint8_t usb_rx_buffer[64];

//IMU variable
GY85_t imu;

float Pitch_Sensor, Yaw_Sensor, Roll_Sensor;

float abias[3] = {-0.108, -0.038, -0.006}, gbias[3] = {-10, 6, -12}, mbias[3]={0.0,0.0,0.0};
float M11=1.0,  M12=-0.0,  M13=0.0,
      M21=0.0,  M22=1.0,   M23=0.0,
      M31=0.0,  M32=-0.0,  M33=1.0;
float ax, ay, az, gx, gy, gz, mx, my, mz,mxc,myc,mzc; // variables to hold latest sensor data values
float q[4] = {1.0f, 0.0f, 0.0f, 0.0f};    // vector to hold quaternion
float temperature;
float Mag_Declination = -0.61; //0°

float RxAcc,RyAcc,RzAcc;
float Rate_Ayz_1,Rate_Axz_1,Rate_Axy_1;
float Axz_1,Ayz_1,Axy_1, Axz_0,Ayz_0,Axy_0;
float RxEst_0,RyEst_0,RzEst_0, RxEst_1,RyEst_1,RzEst_1,Azr_Est;
float RxGyro,RyGyro,RzGyro, R_Est;

unsigned long now_timeperiod;
unsigned long lasttime_timeperiod = 0;
int Time_Period = 0;

//Barometer BMP180

/*resolution:
BMP180_ULTRALOWPOWER - pressure oversampled 1 time  & power consumption 3μA
BMP180_STANDARD      - pressure oversampled 2 times & power consumption 5μA
BMP180_HIGHRES       - pressure oversampled 4 times & power consumption 7μA
BMP180_ULTRAHIGHRES  - pressure oversampled 8 times & power consumption 12μA, library default
*/
BMP180 myBMP(BMP180_ULTRAHIGHRES);
float RADAR_Altitude;

//GPS
double RADAR_Longitude = 0;
double RADAR_Latitude = 0;

extern uint8_t GUI_start_flag_received;  // [STM32-006] Legacy, unused -- kept for linker compat


//RADAR
// Radar parameters
const int m_max = 32;  // Number of chirps per beam position
const int n_max = 31;   // Number of beam positions
const float T1 = 30.0f; // Chirp duration in microseconds
const float PRI1 = 167.0f; // Pulse repetition interval in microseconds
const float T2 = 0.5f;  // Short chirp duration in microseconds
const float PRI2 = 175.0f; // Short PRI in microseconds
const float Guard = 175.4f; // Guard time in microseconds

uint8_t	m = 1; // m = N° of chirp/ position = 16 (made of T1 and PRF1)+ Guard = 175µs +16 (made of T2 and PRF2)
uint8_t	n = 1; // n =[1-31] N° of elevations/azimuth
uint8_t	y = 1;// y = N° of azimuths/revolution = 50 controlled by a microcontroller connected to a stepper motor
uint8_t y_max = 50;// y = N° of azimuths/revolution
uint64_t IF_freq = 120000000ULL;//120MHz

#define PowerAmplifier 1

//Stepper Motor
float Stepper_steps = 200.0f;//step per revolution

// DAC5578 handles (RF Power Amplifier DAC controlling Vg)
DAC5578_HandleTypeDef hdac1, hdac2;
/* Phase accumulators */
float phase_dac1[8] = {0};
float phase_dac2[8] = {0};
const uint32_t sampleRate = 370;    // Sample rate in Hz
const uint32_t period = 2700;       // Period in microseconds
uint8_t DAC_val = 126;

// ADC handles (RF Power Amplifier ADC measuring Idq)
ADS7830_HandleTypeDef hadc1, hadc2;
uint8_t adc1_readings[8] = {0};
uint8_t adc2_readings[8] = {0};
float Idq_reading[16]={0.0f};

/* [GAP-3 FIX 2] Hardware IWDG watchdog handle
 * Prescaler=256, Reload=500 → timeout ≈ 4.096 s from 32 kHz LSI.
 * If the main loop stalls, the MCU resets automatically. */
IWDG_HandleTypeDef hiwdg;


// Global manager instance ADF4382A
ADF4382A_Manager lo_manager;
extern SPI_HandleTypeDef hspi4;

//ADAR1000

ADAR1000Manager adarManager;
ADAR1000_AGC    outerAgc;
static uint8_t matrix1[15][16];
static uint8_t matrix2[15][16];
static uint8_t vector_0[16] = {0,0,0,0,0,0,0,0,0,0,0,0,0,0,0,0};

/* Radar parameters
const int m_max = 32;  // Number of chirps per beam position
const int n_max = 31;   // Number of beam positions
const float T1 = 30.0f; // Chirp duration in microseconds
const float PRI1 = 167.0f; // Pulse repetition interval in microseconds
const float T2 = 0.5f;  // Short chirp duration in microseconds
const float T2 = 175.0f; // Short PRI in microseconds
const float Guard = 175.40f; // Guard time in microseconds*/

//Temperature Sensors
ADS7830_HandleTypeDef hadc3;
float Temperature_1 = 0.0f, Temperature_2 = 0.0f, Temperature_3 = 0.0f, Temperature_4 = 0.0f;
float Temperature_5 = 0.0f, Temperature_6 = 0.0f, Temperature_7 = 0.0f, Temperature_8 = 0.0f;

// Phase differences for 31 beam positions
const float phase_differences[31] = {
    160.0f, 80.0f, 53.333f, 40.0f, 32.0f, 26.667f, 22.857f, 20.0f, 17.778f, 16.0f,
    14.545f, 13.333f, 12.308f, 11.429f, 10.667f, 0.0f,
    -10.667f, -11.429f, -12.308f, -13.333f, -14.545f, -16.0f, -17.778f, -20.0f,
    -22.857f, -26.667f, -32.0f, -40.0f, -53.333f, -80.0f, -160.0f
};

// Convenience HAL wrappers for AD9523 control pins (GPIOF as you said)
static inline void AD9523_PD(bool v)        { HAL_GPIO_WritePin(GPIOF, AD9523_PD_Pin, v ? GPIO_PIN_SET : GPIO_PIN_RESET); }
static inline void AD9523_REF_SEL(bool v)   { HAL_GPIO_WritePin(GPIOF, AD9523_REF_SEL_Pin, v ? GPIO_PIN_SET : GPIO_PIN_RESET); }
static inline void AD9523_SYNC_PULSE(void)  { HAL_GPIO_WritePin(GPIOF, AD9523_SYNC_Pin, GPIO_PIN_SET); HAL_Delay(1); HAL_GPIO_WritePin(GPIOF, AD9523_SYNC_Pin, GPIO_PIN_RESET); }
static inline void AD9523_RESET_ASSERT()    { HAL_GPIO_WritePin(GPIOF, AD9523_RESET_Pin, GPIO_PIN_RESET); } // check polarity
static inline void AD9523_RESET_RELEASE()   { HAL_GPIO_WritePin(GPIOF, AD9523_RESET_Pin, GPIO_PIN_SET); }
static inline void AD9523_CS(bool v)        { HAL_GPIO_WritePin(GPIOF, AD9523_CS_Pin, v ? GPIO_PIN_SET : GPIO_PIN_RESET); }
static inline void AD9523_EEPROM_SEL(bool v){ HAL_GPIO_WritePin(GPIOF, AD9523_EEPROM_SEL_Pin, v ? GPIO_PIN_SET : GPIO_PIN_RESET); }

/* USER CODE END PV */

void SystemClock_Config(void);
void PeriphCommonClock_Config(void);
static void MPU_Config(void);
static void MX_GPIO_Init(void);
static void MX_TIM1_Init(void);
static void MX_TIM3_Init(void);  // B15 fix: DELADJ PWM timer init
static void MX_I2C1_Init(void);
static void MX_I2C2_Init(void);
static void MX_I2C3_Init(void);
static void MX_SPI1_Init(void);
static void MX_SPI4_Init(void);
static void MX_UART5_Init(void);
static void MX_USART3_UART_Init(void);
static void MX_IWDG_Init(void);  /* GAP-3 FIX 2: hardware watchdog */
/* USER CODE BEGIN PFP */

// Function prototypes
void systemPowerUpSequence();
void systemPowerDownSequence();
void initializeBeamMatrices();
void runRadarPulseSequence();
void executeChirpSequence(int num_chirps, uint32_t T1, uint32_t PRI1, uint32_t T2, uint32_t PRI2);
void printSystemStatus();

//////////////////////////////////////////////
////////////////////micros()//////////////////
//////////////////////////////////////////////
unsigned long micros(void){
unsigned long Micros = __HAL_TIM_GET_COUNTER(&htim1);
return Micros; //Clock TIM1 -> AHB/APB1 is set to 72MHz/presc+1   presc = 71
}

//////////////////////////////////////////////
//////////////////Delay_us()//////////////////
//////////////////////////////////////////////

void delay_us(volatile uint32_t us){
__HAL_TIM_SET_COUNTER(&htim1,0);  // set the counter value a
while (__HAL_TIM_GET_COUNTER(&htim1) < us);  // //Clock TIMx -> AHB/APB1 is set to 72MHz/presc+1   presc = 71
}

//////////////////////////////////////////////
//////////////////delay_ns()//////////////////
//////////////////////////////////////////////
void delay_ns(uint32_t nanoseconds)
{
    // Get the starting cycle count
    uint32_t start_cycles = DWT->CYCCNT;

    // Convert nanoseconds to the number of CPU clock cycles
    // Use `SystemCoreClock` to get the current CPU frequency.
    // Use 64-bit math to prevent overflow for large nanosecond values.
    uint32_t cycles = (uint32_t)(((uint64_t)nanoseconds * SystemCoreClock) / 1000000000);

    // Busy-wait until the required number of cycles has passed
    while ((DWT->CYCCNT - start_cycles) < cycles);
}

//////////////////////////////////////////////
//////////////////////RADAR///////////////////
//////////////////////////////////////////////
uint8_t degreesTo7BitPhase(float degrees) {
    // Normalize to 0-360 range
    while(degrees < 0) degrees += 360.0f;
    while(degrees >= 360.0f) degrees -= 360.0f;

    // Convert to 7-bit (0-127)
    uint8_t phase_7bit = (uint8_t)((degrees / 360.0f) * 128.0f);

    return phase_7bit % 128;
}

extern "C" {

    // USB CDC receive callback (called by STM32 HAL)
    void CDC_Receive_FS(uint8_t* Buf, uint32_t *Len) {
        DIAG("USB", "CDC_Receive_FS callback: %lu bytes received", *Len);
        // Process received USB data
        usbHandler.processUSBData(Buf, *Len);

        // Prepare for next reception
        USBD_CDC_SetRxBuffer(&hUsbDeviceFS, &usb_rx_buffer[0]);
        USBD_CDC_ReceivePacket(&hUsbDeviceFS);
    }
}

void systemPowerUpSequence() {
    DIAG_SECTION("PWR: systemPowerUpSequence");
    uint8_t msg[] = "Starting Power Up Sequence...\r\n";
    HAL_UART_Transmit(&huart3, msg, sizeof(msg)-1, 1000);

    // Step 1: Initialize ADTR1107 power sequence
    DIAG("PWR", "Step 1: initializeADTR1107Sequence()");
    if (!adarManager.initializeADTR1107Sequence()) {
        DIAG_ERR("PWR", "ADTR1107 power sequence FAILED -- calling Error_Handler()");
        uint8_t err[] = "ERROR: ADTR1107 power sequence failed!\r\n";
        HAL_UART_Transmit(&huart3, err, sizeof(err)-1, 1000);
        Error_Handler();
    }
    DIAG("PWR", "Step 1 OK: ADTR1107 sequence complete");

    // Step 2: Initialize all ADAR1000 devices
    DIAG("PWR", "Step 2: initializeAllDevices()");
    if (!adarManager.initializeAllDevices()) {
        DIAG_ERR("PWR", "ADAR1000 initialization FAILED -- calling Error_Handler()");
        uint8_t err[] = "ERROR: ADAR1000 initialization failed!\r\n";
        HAL_UART_Transmit(&huart3, err, sizeof(err)-1, 1000);
        Error_Handler();
    }
    DIAG("PWR", "Step 2 OK: All ADAR1000 devices initialized");

    // Step 3: Perform system calibration
    DIAG("PWR", "Step 3: performSystemCalibration()");
    if (!adarManager.performSystemCalibration()) {
        DIAG_WARN("PWR", "System calibration returned issues (non-fatal)");
        uint8_t warn[] = "WARNING: System calibration issues\r\n";
        HAL_UART_Transmit(&huart3, warn, sizeof(warn)-1, 1000);
    } else {
        DIAG("PWR", "Step 3 OK: System calibration passed");
    }

    // Step 4: Set to safe TX mode
    DIAG("PWR", "Step 4: setAllDevicesTXMode()");
    adarManager.setAllDevicesTXMode();
    DIAG("PWR", "Step 4 OK: All devices set to TX mode");

    uint8_t success[] = "Power Up Sequence Completed Successfully\r\n";
    HAL_UART_Transmit(&huart3, success, sizeof(success)-1, 1000);
    DIAG("PWR", "systemPowerUpSequence COMPLETE");
}
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
int main(void)
{

  /* MPU Configuration--------------------------------------------------------*/
  MPU_Config();

  /* MCU Configuration--------------------------------------------------------*/

  /* Reset of all peripherals, Initializes the Flash interface and the Systick. */
  HAL_Init();

  /* Configure the system clock */
  SystemClock_Config();

  /* Configure the peripherals common clocks */
  PeriphCommonClock_Config();

  /* Initialize all configured peripherals */
  MX_GPIO_Init();
  MX_TIM1_Init();
  MX_TIM3_Init();  // B15 fix: init DELADJ PWM timer before LO manager uses it
  MX_I2C1_Init();
  MX_I2C2_Init();
  MX_I2C3_Init();
  MX_SPI1_Init();
  MX_SPI4_Init();
  MX_UART5_Init();
  MX_USART3_UART_Init();
  MX_USB_DEVICE_Init();
  MX_IWDG_Init();  /* GAP-3 FIX 2: start hardware watchdog (~4 s timeout) */
  /* USER CODE BEGIN 2 */

  HAL_TIM_Base_Start(&htim1);

  /* --- Enable DWT cycle counter for accurate microsecond delays --- */
  DWT_Init();

  DIAG_SECTION("SYSTEM INIT");
  DIAG("SYS", "DWT cycle counter initialized, TIM1 started");
  DIAG("SYS", "HAL tick at init start: %lu ms", (unsigned long)HAL_GetTick());

  //Wait for OCXO 3mn
  DIAG("CLK", "OCXO warmup starting -- waiting 180 s (3 min)");
  uint32_t ocxo_start = HAL_GetTick();
  /* [GAP-3 FIX 2] Cannot use HAL_Delay(180000) — IWDG would reset MCU.
   * Instead loop in 1-second steps, kicking the watchdog each iteration. */
  for (int ocxo_sec = 0; ocxo_sec < 180; ocxo_sec++) {
      HAL_IWDG_Refresh(&hiwdg);
      HAL_Delay(1000);
  }
  DIAG_ELAPSED("CLK", "OCXO warmup", ocxo_start);

  DIAG_SECTION("AD9523 POWER SEQUENCING");
  DIAG("PWR", "Asserting AD9523 reset (pin LOW)");
  HAL_GPIO_WritePin(AD9523_RESET_GPIO_Port,AD9523_RESET_Pin,GPIO_PIN_RESET);

  //Power sequencing AD9523
  DIAG("PWR", "Enabling 1.8V clock rail");
  HAL_GPIO_WritePin(EN_P_1V8_CLOCK_GPIO_Port,EN_P_1V8_CLOCK_Pin,GPIO_PIN_SET);
  HAL_Delay(100);
  DIAG("PWR", "Enabling 3.3V clock rail");
  HAL_GPIO_WritePin(EN_P_3V3_CLOCK_GPIO_Port,EN_P_3V3_CLOCK_Pin,GPIO_PIN_SET);
  HAL_Delay(100);
  DIAG("PWR", "Releasing AD9523 reset (pin HIGH)");
  HAL_GPIO_WritePin(AD9523_RESET_GPIO_Port,AD9523_RESET_Pin,GPIO_PIN_SET);
  HAL_Delay(100);
  DIAG("PWR", "AD9523 power sequencing complete -- all rails up, reset released");

  //Set planned Clocks on AD9523
  /*
  o Channel 0 = 300MHz LVDS (ADF4382 TX)
  o Channel 1 = 300MHz LVDS (ADF4382 RX) (Phase aligned with Channel 0)
  o Channel 4 = 400MHz LVDS (ADC)
  o Channel 5 = 400MHz LVDS (FPGA_ADC)(Phase aligned with Channel 4)
  o Channel 6 = 100MHz LVCMOS (FPGA system clock)
  o Channel 7 = 20MHz LVCMOS (FPGA test)
  o Channel 8 = 60MHz LVDS (ADF4382 TX sync)
  o Channel 9 = 60MHz LVDS (ADF4382 RX sync)(Phase aligned with Channel 8)
  o Channel 10 = 120MHz LVCMOS
  o Channel 11 = 120MHz LVCMOS (Phase aligned with Channel 10)
   */


  // Ensure stm32_spi.c and stm32_delay.c are compiled and linked

  DIAG("CLK", "Calling configure_ad9523()...");
  uint32_t ad9523_cfg_start = HAL_GetTick();
  if (configure_ad9523() != 0) {
      // configuration error - handle as needed
      DIAG_ERR("CLK", "configure_ad9523() FAILED -- entering infinite halt loop");
      while (1) { HAL_Delay(1000); }
  }
  DIAG_ELAPSED("CLK", "configure_ad9523()", ad9523_cfg_start);
  DIAG("CLK", "AD9523 configured successfully");

  //Power sequencing FPGA
  DIAG_SECTION("FPGA POWER SEQUENCING");
  DIAG("PWR", "Enabling 1.0V FPGA rail");
  HAL_GPIO_WritePin(EN_P_1V0_FPGA_GPIO_Port,EN_P_1V0_FPGA_Pin,GPIO_PIN_SET);
  HAL_Delay(100);
  DIAG("PWR", "Enabling 1.8V FPGA rail");
  HAL_GPIO_WritePin(EN_P_1V8_FPGA_GPIO_Port,EN_P_1V8_FPGA_Pin,GPIO_PIN_SET);
  HAL_Delay(100);
  DIAG("PWR", "Enabling 3.3V FPGA rail");
  HAL_GPIO_WritePin(EN_P_3V3_FPGA_GPIO_Port,EN_P_3V3_FPGA_Pin,GPIO_PIN_SET);
  HAL_Delay(100);
  DIAG("PWR", "FPGA power sequencing complete -- 1.0V -> 1.8V -> 3.3V");


// Initialize module IMU
  DIAG_SECTION("IMU INIT (GY-85)");
  DIAG("IMU", "Initializing GY-85 IMU...");
  if (!GY85_Init()) {
      DIAG_ERR("IMU", "GY85_Init() FAILED -- calling Error_Handler()");
      Error_Handler();
  }
  DIAG("IMU", "GY-85 initialized OK, running 10 calibration samples");
  for(int i=0; i<10;i++){
  if (!GY85_Update(&imu)) {
      Error_Handler();
  }

  ax = imu.ax;
  ay = imu.ay;
  az = imu.az;
  gx = -imu.gx;
  gy = -imu.gy;
  gz = imu.gz;
  mx = imu.mx;
  my = imu.my;
  mz = imu.mz;

  ax *= 6.10351e-5;   //2.0 / 32768.0;
  ay *= 6.10351e-5;
  az *= 6.10351e-5;

  ax -= abias[0];   // Convert to g's, remove accelerometer biases
  ay -= abias[1];
  az -= abias[2];

  gx *= 0.0152588f;   //500.0 / 32768.0;
  gy *= 0.0152588f;
  gz *= 0.0152588f;

  gx -= gbias[0];   // Convert to degrees per seconds, remove gyro biases
  gy -= gbias[1];
  gz -= gbias[2];

  mx *= 6.10351e-5;   //2.0 / 32768.0;
  my *= 6.10351e-5;
  mz *= 6.10351e-5;

  mxc = M11*(mx-mbias[0]) + M12*(my-mbias[1]) +M13*(mz-mbias[2]);
  myc = M21*(mx-mbias[0]) + M22*(my-mbias[1]) +M23*(mz-mbias[2]);
  mzc = M31*(mx-mbias[0]) + M32*(my-mbias[1]) +M33*(mz-mbias[2]);

  mx = mxc;
  my = myc;
  mz = mzc;

  float norm = sqrt((mx*mx) + (my*my) + (mz*mz));
  mx /=norm;
  my /=norm;
  mz /=norm;

  /***************************************************************/
  /*********************IMU Complementary Filter******************/
  /***************************************************************/
    RxAcc = ax;
    RyAcc = ay;
    RzAcc = az;

    Rate_Ayz_1 = gx;
    Rate_Axz_1 = gy;
    Rate_Axy_1 = gz;

    Rate_Ayz_1 = Rate_Ayz_1*0.01745;//Convertion from °/s to Radians/s
    Rate_Axz_1 = Rate_Axz_1*0.01745;
    Rate_Axy_1 = Rate_Axy_1*0.01745;

    /*Combining Accelerometer & Gyroscope Data*/
    Axz_0 = atan2(RxEst_0,RzEst_0);
    Ayz_0 = atan2(RyEst_0,RzEst_0);
    Axy_0 = atan2(RxEst_0,RyEst_0);

    now_timeperiod = micros();

    Time_Period = now_timeperiod - lasttime_timeperiod;

    Axz_1= Axz_0 + Rate_Axz_1*Time_Period*0.000001;
    Ayz_1= Ayz_0 + Rate_Ayz_1*Time_Period*0.000001;
    Axy_1= Axy_0 + Rate_Axy_1*Time_Period*0.000001;

    lasttime_timeperiod = now_timeperiod;

    RxGyro = sin(Axz_1)/(sqrt(1.0 + cos(Axz_1)*cos(Axz_1) * tan(Ayz_1)*tan(Ayz_1)));
    RyGyro = sin(Ayz_1)/(sqrt(1.0 + cos(Ayz_1)*cos(Ayz_1) * tan(Axz_1)*tan(Axz_1)));
    if(RzEst_0 >= 0){
      RzGyro = 1.0*sqrt(1 - RxGyro*RxGyro - RyGyro*RyGyro);
    }
    else {
      RzGyro = -1*sqrt(1 - RxGyro*RxGyro - RyGyro*RyGyro);
    }

    RxEst_1 = RxAcc*0.5 + RxGyro*0.5 ;// Weight of Gyro. over Acc.
    RyEst_1 = RyAcc*0.5 + RyGyro*0.5 ;
    RzEst_1 = RzAcc*0.5 + RzGyro*0.5 ;

    R_Est = sqrt(RxEst_1*RxEst_1+RyEst_1*RyEst_1+RzEst_1*RzEst_1);

    Pitch_Sensor = atan2(RxEst_1,sqrt(RyEst_1*RyEst_1)+(RzEst_1*RzEst_1))*180/PI;
    Roll_Sensor = atan2(RyEst_1,sqrt(RxEst_1*RxEst_1)+(RzEst_1*RzEst_1))*180/PI;

    float magRawX = mx*cos(Pitch_Sensor*PI/180.0f)  - mz*sin(Pitch_Sensor*PI/180.0f);
	float magRawY = mx*sin(Roll_Sensor*PI/180.0f)*sin(Pitch_Sensor*PI/180.0f) + my*cos(Roll_Sensor*PI/180.0f)- mz*sin(Roll_Sensor*PI/180.0f)*cos(Pitch_Sensor*PI/180.0f);
    Yaw_Sensor = (180*atan2(magRawY,magRawX)/PI) - Mag_Declination;

    if(Yaw_Sensor<0)Yaw_Sensor+=360;

    // Override magnetometer heading with UM982 dual-antenna heading when available
    if (um982_is_heading_valid(&um982)) {
        Yaw_Sensor = um982_get_heading(&um982);
    }

    RxEst_0 = RxEst_1;
    RyEst_0 = RyEst_1;
    RzEst_0 = RzEst_1;

    HAL_Delay(300);

  }

    ///////////////////////////////////////////////////////////////////////////////////
    ///////////////////////////////////BAROMETER BMP180////////////////////////////////
    ///////////////////////////////////////////////////////////////////////////////////
    DIAG_SECTION("BAROMETER INIT (BMP180)");
    DIAG("IMU", "Reading 5 barometer samples for altitude baseline");
  	for(int i = 0; i<5 ; i++){
		float BMP_Perssure = myBMP.getPressure();
		RADAR_Altitude = 44330*(1-(pow((BMP_Perssure/101325),(1/5.255))));
		HAL_Delay(100);
  	}
    DIAG("IMU", "Barometer init complete, RADAR_Altitude baseline set");

    ///////////////////////////////////////////////////////////////////////////////////
    ///////////////////////////////////////ADF4382/////////////////////////////////////
    ///////////////////////////////////////////////////////////////////////////////////
    DIAG_SECTION("ADF4382A LO INIT");
    printf("Starting ADF4382A Radar LO System...\n");
    printf("Using SPI4 with TIMED SYNCHRONIZATION (60 MHz clocks)\n");
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

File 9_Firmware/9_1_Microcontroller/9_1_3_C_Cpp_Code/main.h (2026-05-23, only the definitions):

#define AD9523_PD_Pin GPIO_PIN_3
#define AD9523_PD_GPIO_Port GPIOF
#define AD9523_REF_SEL_Pin GPIO_PIN_4
#define AD9523_REF_SEL_GPIO_Port GPIOF
#define AD9523_SYNC_Pin GPIO_PIN_5
#define AD9523_SYNC_GPIO_Port GPIOF
#define AD9523_RESET_Pin GPIO_PIN_6
#define AD9523_RESET_GPIO_Port GPIOF
#define AD9523_CS_Pin GPIO_PIN_7
#define AD9523_CS_GPIO_Port GPIOF
#define AD9523_STATUS0_Pin GPIO_PIN_8
#define AD9523_STATUS0_GPIO_Port GPIOF
#define AD9523_STATUS1_Pin GPIO_PIN_9
#define AD9523_STATUS1_GPIO_Port GPIOF
#define AD9523_EEPROM_SEL_Pin GPIO_PIN_10
#define AD9523_EEPROM_SEL_GPIO_Port GPIOF
#define ADAR_1_CS_3V3_Pin GPIO_PIN_0
#define ADAR_1_CS_3V3_GPIO_Port GPIOA
#define ADAR_2_CS_3V3_Pin GPIO_PIN_1
#define ADAR_2_CS_3V3_GPIO_Port GPIOA
#define ADAR_3_CS_3V3_Pin GPIO_PIN_2
#define ADAR_3_CS_3V3_GPIO_Port GPIOA
#define ADAR_4_CS_3V3_Pin GPIO_PIN_3
#define ADAR_4_CS_3V3_GPIO_Port GPIOA
#define LED_1_Pin GPIO_PIN_12
#define LED_1_GPIO_Port GPIOF
#define LED_2_Pin GPIO_PIN_13
#define LED_2_GPIO_Port GPIOF
#define LED_3_Pin GPIO_PIN_14
#define LED_3_GPIO_Port GPIOF
#define LED_4_Pin GPIO_PIN_15
#define LED_4_GPIO_Port GPIOF
#define EN_P_5V0_PA1_Pin GPIO_PIN_0
#define EN_P_5V0_PA1_GPIO_Port GPIOG
#define EN_P_5V0_PA2_Pin GPIO_PIN_1
#define EN_P_5V0_PA2_GPIO_Port GPIOG
#define EN_P_1V0_FPGA_Pin GPIO_PIN_7
#define EN_P_1V0_FPGA_GPIO_Port GPIOE
#define EN_P_1V8_FPGA_Pin GPIO_PIN_8
#define EN_P_1V8_FPGA_GPIO_Port GPIOE
#define EN_P_3V3_FPGA_Pin GPIO_PIN_9
#define EN_P_3V3_FPGA_GPIO_Port GPIOE
#define EN_P_5V0_ADAR_Pin GPIO_PIN_10
#define EN_P_5V0_ADAR_GPIO_Port GPIOE
#define EN_P_3V3_ADAR12_Pin GPIO_PIN_11
#define EN_P_3V3_ADAR12_GPIO_Port GPIOE
#define EN_P_3V3_ADAR34_Pin GPIO_PIN_12
#define EN_P_3V3_ADAR34_GPIO_Port GPIOE
#define EN_P_3V3_ADTR_Pin GPIO_PIN_13
#define EN_P_3V3_ADTR_GPIO_Port GPIOE
#define EN_P_3V3_SW_Pin GPIO_PIN_14
#define EN_P_3V3_SW_GPIO_Port GPIOE
#define EN_P_3V3_VDD_SW_Pin GPIO_PIN_15
#define EN_P_3V3_VDD_SW_GPIO_Port GPIOE
#define EN_P_5V0_PA3_Pin GPIO_PIN_2
#define EN_P_5V0_PA3_GPIO_Port GPIOG
#define EN_P_5V5_PA_Pin GPIO_PIN_3
#define EN_P_5V5_PA_GPIO_Port GPIOG
#define EN_P_1V8_CLOCK_Pin GPIO_PIN_4
#define EN_P_1V8_CLOCK_GPIO_Port GPIOG
#define EN_P_3V3_CLOCK_Pin GPIO_PIN_5
#define EN_P_3V3_CLOCK_GPIO_Port GPIOG
#define ADF4382_RX_LKDET_Pin GPIO_PIN_6
#define ADF4382_RX_LKDET_GPIO_Port GPIOG
#define ADF4382_RX_DELADJ_Pin GPIO_PIN_7
#define ADF4382_RX_DELADJ_GPIO_Port GPIOG
#define ADF4382_RX_DELSTR_Pin GPIO_PIN_8
#define ADF4382_RX_DELSTR_GPIO_Port GPIOG
#define MAG_DRDY_Pin GPIO_PIN_6
#define MAG_DRDY_GPIO_Port GPIOC
#define ACC_INT_Pin GPIO_PIN_7
#define ACC_INT_GPIO_Port GPIOC
#define GYR_INT_Pin GPIO_PIN_8
#define GYR_INT_GPIO_Port GPIOC
#define STEPPER_CW_P_Pin GPIO_PIN_4
#define STEPPER_CW_P_GPIO_Port GPIOD
#define STEPPER_CLK_P_Pin GPIO_PIN_5
#define STEPPER_CLK_P_GPIO_Port GPIOD
#define EN_DIS_RFPA_VDD_Pin GPIO_PIN_6
#define EN_DIS_RFPA_VDD_GPIO_Port GPIOD
#define EN_DIS_COOLING_Pin GPIO_PIN_7
#define EN_DIS_COOLING_GPIO_Port GPIOD
#define FPGA_DIG5_SAT_Pin       GPIO_PIN_13
#define FPGA_DIG5_SAT_GPIO_Port GPIOD
#define FPGA_DIG6_Pin           GPIO_PIN_14
#define FPGA_DIG6_GPIO_Port     GPIOD
#define FPGA_DIG7_Pin           GPIO_PIN_15
#define FPGA_DIG7_GPIO_Port     GPIOD
#define ADF4382_RX_CE_Pin GPIO_PIN_9
#define ADF4382_RX_CE_GPIO_Port GPIOG
#define ADF4382_RX_CS_Pin GPIO_PIN_10
#define ADF4382_RX_CS_GPIO_Port GPIOG
#define ADF4382_TX_LKDET_Pin GPIO_PIN_11
#define ADF4382_TX_LKDET_GPIO_Port GPIOG
#define ADF4382_TX_DELSTR_Pin GPIO_PIN_12
#define ADF4382_TX_DELSTR_GPIO_Port GPIOG
#define ADF4382_TX_DELADJ_Pin GPIO_PIN_13
#define ADF4382_TX_DELADJ_GPIO_Port GPIOG
#define ADF4382_TX_CS_Pin GPIO_PIN_14
#define ADF4382_TX_CS_GPIO_Port GPIOG
#define ADF4382_TX_CE_Pin GPIO_PIN_15
#define ADF4382_TX_CE_GPIO_Port GPIOG
#define DAC_1_VG_CLR_Pin GPIO_PIN_4
#define DAC_1_VG_CLR_GPIO_Port GPIOB
#define DAC_1_VG_LDAC_Pin GPIO_PIN_5
#define DAC_1_VG_LDAC_GPIO_Port GPIOB
#define DAC_2_VG_CLR_Pin GPIO_PIN_8
#define DAC_2_VG_CLR_GPIO_Port GPIOB
#define DAC_2_VG_LDAC_Pin GPIO_PIN_9
#define DAC_2_VG_LDAC_GPIO_Port GPIOB

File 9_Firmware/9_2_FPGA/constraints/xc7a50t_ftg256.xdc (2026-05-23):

# ============================================================================
# RADAR SYSTEM FPGA CONSTRAINTS
# ============================================================================
# Device: XC7A50T-2FTG256I (FTG256 package)
# Board:  AERIS-10 Phased Array Radar — Main Board
# Source: Pin assignments extracted from Eagle schematic (RADAR_Main_Board.sch)
#         FPGA = U42
#
# NOTE: The README and prior version of this file incorrectly referenced
#       XC7A100TCSG324-1. The physical board uses XC7A50T in a 256-ball BGA
#       (FTG256). All PACKAGE_PIN values below are FTG256 ball locations.
#
# I/O Bank Voltage Summary:
#   Bank 0:  VCCO = 3.3V (JTAG, flash CS)
#   Bank 14: VCCO = 2.5V (ADC LVDS_25 data — placer-enforced; adc_pwdn as LVCMOS25)
#   Bank 15: VCCO = 3.3V (DAC, clocks, STM32 SPI 3.3V side, DIG bus, mixer)
#   Bank 34: VCCO = 1.8V (ADAR1000 beamformer control, SPI 1.8V side)
#   Bank 35: VCCO = 3.3V (FT2232H USB 2.0 FIFO — 15 signals)
#
# DRC Fix History:
#   - PLIO-9: Moved clk_120m_dac from C13 (N-type) to D13 (P-type MRCC).
#     Clock inputs must use the P-type pin of a Multi-Region Clock-Capable pair.
#   - BIVC-1 / Place 30-372: Bank 14 must have a single VCCO. LVDS_25 forces
#     VCCO=2.5V, so adc_pwdn was changed from LVCMOS33 to LVCMOS25 to match.
#     IBUFDS input buffers are VCCO-independent. BIVC-1 also waived via
#     set_property SEVERITY in the build script as an additional safety net.
#     in the build script. adc_pwdn (LVCMOS25) coexists in the same bank.
#   - UCIO/NSTD: Unconstrained ports (FT601 ports inactive with USB_MODE=1,
#     status/debug outputs have no physical pins). Handled with SEVERITY
#     demotion + default IOSTANDARD.
#   - PLIO-9: FT2232H CLKOUT routed to C4 (IO_L12N_T1_MRCC_35, N-type).
#     Clock inputs normally use P-type MRCC pins, but IBUFG works correctly
#     on N-type. Demote PLIO-9 to warning in build script.
# ============================================================================

# ============================================================================
# CONFIGURATION
# ============================================================================
set_property CFGBVS VCCO [current_design]
set_property CONFIG_VOLTAGE 3.3 [current_design]

# ============================================================================
# DRC WAIVERS — Hardware-Level Known Issues (applied in build script)
# ============================================================================
# BIVC-1: Bank 14 VCCO=3.3V with LVDS_25 inputs + LVCMOS33 adc_pwdn.
# IBUFDS input buffers are VCCO-independent on 7-series — they use an
# internal differential amplifier that works correctly at any VCCO.
# The BIVC-1 DRC check is intended for OBUFDS *outputs* where VCCO
# directly affects the output swing. Since Bank 14 has only LVDS inputs
# and one LVCMOS33 output, this is safe to demote to a warning.
# → Applied in build_50t_test.tcl: set_property SEVERITY {Warning} [get_drc_checks BIVC-1]
#
# NSTD-1 / UCIO-1: Unconstrained ports — FT601 USB ports (inactive with
# USB_MODE=1 generate block), dac_clk (DAC clock comes from AD9523, not FPGA),
# and all status/debug outputs (no physical pins available). These ports are
# present in the shared RTL but have no connections on the 50T board.
# → Applied in build_50t_test.tcl: set_property SEVERITY {Warning} [get_drc_checks {NSTD-1 UCIO-1}]

# ============================================================================
# CLOCK CONSTRAINTS
# ============================================================================

# 100MHz System Clock (AD9523 OUT6 → FPGA_SYS_CLOCK → Bank 15 MRCC pin E12)
set_property PACKAGE_PIN E12 [get_ports {clk_100m}]
set_property IOSTANDARD LVCMOS33 [get_ports {clk_100m}]
create_clock -name clk_100m -period 10.0 [get_ports {clk_100m}]
set_input_jitter [get_clocks clk_100m] 0.1

# 120MHz DAC Clock (AD9523 OUT11 → FPGA_DAC_CLOCK → Bank 15 MRCC pin D13)
# NOTE: The physical DAC (U3, AD9708) receives its clock directly from the
#       AD9523 via a separate net (DAC_CLOCK), NOT from the FPGA. The FPGA
#       uses this clock input for internal DAC data timing only. The RTL port
#       `dac_clk` is an RTL output that assigns clk_120m directly. It has no
#       physical pin on the 50T board and is left unconnected here. The port
#       CANNOT be removed from the RTL because the 200T board uses it with
#       ODDR clock forwarding (pin H17, see xc7a200t_fbg484.xdc).
# FIX: Moved from C13 (IO_L12N = N-type) to D13 (IO_L12P = P-type MRCC).
#      Clock inputs must use the P-type pin of an MRCC pair (PLIO-9 DRC).
set_property PACKAGE_PIN D13 [get_ports {clk_120m_dac}]
set_property IOSTANDARD LVCMOS33 [get_ports {clk_120m_dac}]
create_clock -name clk_120m_dac -period 8.333 [get_ports {clk_120m_dac}]
set_input_jitter [get_clocks clk_120m_dac] 0.1
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

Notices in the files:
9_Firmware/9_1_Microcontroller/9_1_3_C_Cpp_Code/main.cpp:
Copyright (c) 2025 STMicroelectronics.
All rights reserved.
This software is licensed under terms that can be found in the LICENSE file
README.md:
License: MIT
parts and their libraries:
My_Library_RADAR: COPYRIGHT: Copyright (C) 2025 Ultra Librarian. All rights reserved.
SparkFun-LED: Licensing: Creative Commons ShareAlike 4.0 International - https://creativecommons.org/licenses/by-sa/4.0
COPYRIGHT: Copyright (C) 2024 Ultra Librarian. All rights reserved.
